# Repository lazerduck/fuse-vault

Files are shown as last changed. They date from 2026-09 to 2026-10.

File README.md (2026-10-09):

# Fuse Vault
Fuse Vault is a security hardware device designed to provide a genuinely trustable location where you can store various secret and sensitive documents. It provides encrypted at rest storage and on-device unlocking alongside FIDO2 passkey capabilities.

## Philosophy
Fuse Vault is built around the principle of Trust. Every aspect of Fuse Vault needed to be as open source, inspectable and trustable by the user as possible. The intention was to create a device that could be trusted rather than a device that had to be trusted. Specifically in contrast to things like a TPM. To achieve this, Fuse Vault has used open source hardware where possible and all the software is also open source, inspectable and customizable. Additionally, where trust can't be 100% confirmed, we instead take whatever measures we can to get as close as possible to something we can trust. For example, when encrypting data, we allow users to establish a stack of algorithms each with a varied provenance.

## Hardware
The core of Fuse Vault is the RP2354, a Raspberry Pi RP2350-family microcontroller with integrated flash. Its architecture, memory map and peripheral interfaces are publicly documented, and the Pico SDK and boot ROM source are available. The Hazard3 RISC-V cores are open hardware; the Arm Cortex-M33 cores used by this firmware are not open-source implementations. The whole chip should therefore not be described as open-source hardware. See the [Raspberry Pi chip documentation](https://www.raspberrypi.com/documentation/microcontrollers/microcontroller-chips.html) and [boot ROM source](https://github.com/raspberrypi/pico-bootrom-rp2350). There is also a screen and D-pad enabling user interaction with the device without using the host computer. This is intended to ensure the user's key is never exposed to an attacker through a compromised computer. The PCB contains a USB-A and a USB-C male port allowing it to be plugged into most devices. In this revision of the PCB, for simplicity the storage is attached as an SD card. All data on this card is either always encrypted or not sensitive, however this is understood as a potential vulnerability.

## Software
The software is written in C with the Pico SDK and controls and coordinates the rest of the functionality of the device. The software is highly user configurable and designed to be secure over fast with observed speeds around 400 KiB/s on the device display. Throughput depends on the selected cipher stack and workload; this is not a guaranteed rate. One KiB is 1,024 bytes.

### Subsections

- [Key handling](docs/KeyHandling.md)
- [File storage](docs/FileStorage.md)
- [Setup, unlock and enrollment](docs/Setup.md)
- [FIDO2 and passkeys](docs/FIDO2.md)
- [The unlocked session](docs/Session.md)
- [Randomness](docs/Randomness.md)
- [Planned improvements](docs/Improvements.md)

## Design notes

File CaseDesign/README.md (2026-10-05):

# Fuse Vault PCB reference

**Latest: prototype E — four supported shell snaps.** [Print instructions](prototype-e/README.md)
replace D's failed thin latch with ramped alignment posts and recesses. Print the
standard snap sample first, then E base and lid. Reuse the working D end caps and
USB-C collar. Closure must hold the collar securely without help from the end caps;
physical holding force still needs testing. Intended for occasional service access.

**Previous prototype D — slimmer case; latch failed physical test.** [Print and assembly instructions](prototype-d/README.md)
cover the 12.1 mm body, tighter PCB locators, hook-and-snap closure, TPU covers
with detents, bare joystick and tactile back-button dimple. Start with the latch
test pair. The existing USB-C collar is reusable; D needs new base, lid and covers.
Physical testing is pending; earlier prototypes are preserved.

**Previous prototype C — assembly access.** [Print and assembly instructions](prototype-c/README.md)
cover the open-top PCB/collar seats, enlarged SD-card loading clearance and
externally accessible top nut. Print the C base and lid; reuse the previous
accessories. Built after the first real V2 board trial exposed insertion
obstructions. C CAD checks pass; a physical re-test is still needed.

**Previous prototype B:** [prototype-b/README.md](prototype-b/README.md) contains
print files and instructions for the flat lid, wider/lower TPU D-pad, integral
back-button tab and two TPU USB end caps. Start with the small back-button coupon.
[REVISION_B_REQUIREMENTS.md](REVISION_B_REQUIREMENTS.md) records the feedback and
current direction. B printing and populated V2 board fit remain pending.

**First case prototype now available:** [prototype-a/README.md](prototype-a/README.md)
contains the five-part PLA/TPU fit prototype, single M2 screw, hooked lid and captured
USB-C collar. Use `build_case.py` and `prototype_parameters.json` for that design.
Its corrected reference and validation are separate from the original files below.

**2026-09-21 evidence update:** See [CASE_DESIGN_BRIEF.md](CASE_DESIGN_BRIEF.md)
for the supplied screen drawing, verified USB shell heights, USB-C support
requirement, captive controls and enclosed SD card. Manufacturer PDFs are now in
`datasheets/`. The reference exports below remain revision 1: the display thickness
and USB-C mounting datum still require correction and regeneration before case CAD.

Mechanically useful **reference revision 1**, built from the supplied Gerber archive, BOM, CPL and top/bottom renders. No enclosure has been designed. The board geometry and assembly positions are source-derived; the components are simplified envelopes with explicitly provisional Z dimensions.

## Open these files

- **reference.step**: coloured, named assembly with PCB, 71 populated component envelopes and one clearly named TFT placeholder.
- **pcb.step**: exact nominal bare-board geometry, including all unique drilled holes, slots and the rectangular cutout.
- **keepouts.step**: 98 separately named clearance, terminal, solder, locating-peg and access volumes. Import in the same coordinates as reference.step.
- **reference.stl**: millimetre-scale, multi-solid preview. Components can overlap and touch; this is not a single watertight printable assembly or an enclosure.
- **pcb.stl**: bare-board mesh.
- **reference_preview.png**: top and underside views of the actual generated geometry.
- **top_validation.png / bottom_validation.png**: model envelopes and extracted features registered against the supplied renders.
- **parameters.json**: editable assumptions, with evidence beside each important component.
- **drill_schedule.csv / placements.csv / component_envelopes.csv**: extracted drill data, BOM-linked placement data, and generated component bounds.
- **validation.json**: machine-readable geometry and render-registration checks.

## Board geometry

All coordinates are **millimetres in the original EasyEDA Gerber coordinate system**, viewed from the top. X increases toward USB-A. Y is negative across the board. The bottom PCB surface is Z=0 and the top is Z=1.6. Bottom-side component coordinates are not mirrored; only the bottom-view image is mirrored for comparison.

| Feature | Nominal value / bounds | Evidence |
|---|---|---|
| Board size | 73.335 x 21.237 mm | Original GKO outline centreline |
| X extent | -0.127 to 73.208 | GKO |
| Y extent | -21.237 to 0 | GKO |
| Thickness | 1.6 mm | Gerber ZIP manufacturing metadata: `erp_parameter_file.json`, `stencil_ply=1.6` |
| Internal rectangular cutout | 2.540 x 15.748 mm | GKO |
| Cutout X | 11.42583 to 13.96583 | GKO |
| Cutout Y | -19.52613 to -3.77813 | GKO |
| Unique drill features | 105 round holes + 2 routed slots | Three original Excellon files, duplicate via records removed |
| USB-C slots | 0.50002 diameter cutter; 1.29997 centreline travel; 1.79999 overall length | PTH G85 records |

The large green areas above and below the circuitry in the renders are manufacturing rails. The processed CAM panel outline adds approximately 25 mm at each long edge. Those rails and their tooling holes are excluded from the finished PCB reference. No dedicated enclosure screw-hole pattern is established on the finished board: the large holes near USB-A and the other non-plated holes are occupied connector/switch locating features.

These are exact **design-file nominal** coordinates, not measurements of the manufactured board. Router corner radii, V-score break residue, board thickness tolerance and plating variation are not determined by the supplied data. The cutout retains the sharp nominal corners in the GKO.

## Important component locations

These are CPL placement origins, which are not always the physical centre of the body. Explicit `offset_xy` values align the simplified body to its footprint/render. Special-component sizes and offsets are expressed in board axes; generic packages use the CPL rotation.

| Ref | BOM part | Side | CPL X | CPL Y | CPL rotation |
|---|---|---|---:|---:|---:|
| J1 | SHOU HAN AM90, C404965 | Top | 69.850 | -11.049 | 90 |
| J2 | XKB U261-121N-4BS2S, C2879827 | Top / assumed mid-mount | 1.143 | -10.668 | 270 |
| CARD1 | SHOU HAN TF PUSH, C393941 | Bottom | 57.404 | -9.779 | 0 |
| U3 | SHOU HAN 0.5-8P CTSJ-H2.0 119, C5373445 | Bottom | 23.241 | -11.557 | 90 |
| SW3 | SHOU HAN 10*10*9-6P WX, C2858290 | Top | 60.325 | -14.732 | 0 |
| SW4 | LXW-TS-45X45X38-SMD, C53447035 | Top | 49.149 | -15.875 | 270 |
| SW1 | TS-1140SP-4x4x2.0H-260, C51927161 | Bottom | 6.731 | -3.302 | 180 |
| SW2 | TS-1140SP-4x4x2.0H-260, C51927161 | Bottom | 6.858 | -17.526 | 0 |

Both USB components are represented as protruding **plugs**, consistent with the supplied renders. Their simplified solid envelopes are not detailed connector shells.

## Assumptions to resolve before committing enclosure dimensions

1. **TFT:** No display part appears in either BOM or CPL. The 27.9 x 13.5 mm rectangle comes directly from top silkscreen, but is not proven to be the glass outline or active viewing area. The cyan volume is a placeholder with a 0.5 mm PCB gap and 2.5 mm thickness. No bezel opening should be derived from it yet. The flex corridor to the cutout is a provisional clearance volume, not a verified cable route.
2. **USB Z position:** J1 uses an assumed 4.5 mm body height sitting on the top PCB surface. J2 uses an assumed 2.4 mm height with its bottom 2.0 mm below the top PCB surface. These seating heights need a drawing or physical measurement. Their XY envelopes have been compared with the renders.
3. **Controls:** SW3 total height 9.0 mm, SW4 3.8 mm, and SW1/SW2 2.0 mm are inferred from exact BOM part identifiers, not verified against mechanical drawings. Joystick base/shaft shape, movement diameter and button actuators are simplified. No separate D-pad or joystick cap is supplied or modelled.
4. **microSD:** Body XY and offset are estimated from the registered bottom render, and its 2.0 mm height is provisional. The card exits toward +Y. A 20 mm withdrawal space is provided as a design allowance; actual latched/ejected card positions and push travel are not established.
5. **FPC connector:** XY uses the bottom-silkscreen envelope; 2.0 mm height is inferred from the H2.0 identifier. Latch-opening clearance remains provisional.
6. **Other parts:** Package dimensions come from footprint names, with assumed heights. Inductor heights 4.0 and 2.0 mm are inferred from series names. Solder, pins, locating pegs, special terminals and general 0.5 mm clearances are conservative editable allowances, not tolerance-certified bounds.

The manufacturer-document links were investigated, but their PDF downloads returned access/rate-limit errors. **No height is labelled drawing-verified.** Do not infer that an assumed clearance guarantees fit.

## Validation performed

- Parsed the original metric 4.5-format outline and metric Excellon files. Unsupported drill/outline syntax causes extraction to fail rather than silently dropping geometry.
- Deduplicated identical drill records across the PTH/via files; retained both original source references in the drill schedule.
- Checked that the PCB is one valid solid and every extracted drill centre passes through it.
- Independently calculated PCB volume from rectangle areas and circular/slot areas: **2383.867963245 mm3**, matching the exported STEP geometry.
- Re-imported the STEP files: **73 reference solids** and **98 keep-out solids**, all valid, with preserved volumes.
- Registered the top and mirrored bottom images using board edges, then compared seven independently selected visible component centres. Maximum discrepancy: **1.134 pixels**, approximately **0.115 mm at the render scale**. This is an image-registration result, not an assembly tolerance claim.
- Visually inspected the top/bottom overlays and depth-buffered 3D preview. The display guide, cutout, connector arrangement, joystick and bottom-side controls correspond to the supplied renders.

Z heights cannot be validated from these orthographic top/bottom renders. This revision is ready for spatial planning and measurement correction; close-fitting enclosure openings depend on resolving the assumptions above.

## Regenerate or change dimensions

Tested with Python 3.13 and CadQuery 2.8.0. From this directory:

```powershell
python -m pip install -r requirements.txt
python extract_geometry.py
python build_reference.py
python validate_and_preview.py
```

Edit `parameters.json` for body sizes, seating offsets, display dimensions and access allowances. Set `display.enabled` to false to remove the TFT placeholder. The extraction script preserves the original source files and creates `geometry.json`. To change source placements, update the source CPL and run extraction again.

`reference.step` and `keepouts.step` have the same origin and units. Keep the assemblies separate in CAD. The keep-outs intentionally overlap one another and the reference; they are spaces reserved from a future case, not extra physical parts. The PCB keep-out is a conservative bounding box and reserves the internal cutout too.

## Source provenance

The original archive was `fuse-vault_PCB1_20260916_204032.zip_Y4.zip`; geometry comes from its `12416276a_y4/yg` originals, not its translated panel CAM output. Selected source Gerbers and drills are included. The supplied top and bottom PNGs are preserved as `source/top.png` and `source/bottom.png`.

The two user-supplied files are tab-delimited UTF-16 despite their `.csv` extension:

- `d195f926bac54f4a8a605b863e6e7800_1789587642000.csv` -> `source/assembly-a.csv` (BOM).
- `d195f926bac54f4a8a605b863e6e7800_1789587642000 (1).csv` -> `source/assembly-b.csv` (CPL).

`source_hashes.json` records SHA-256 digests for the included source files. Factory account/order metadata and signed download links are not redistributed.

Manufacturer-document lookup locations, for resolving the remaining assumptions:

- [AM90](https://jlcpcb.com/partdetail/SHOUHAN-AM90/C404965)
- [U261-121N-4BS2S](https://jlcpcb.com/partdetail/XKBConnection-U261_121N4BS2S/C2879827)
- [TF PUSH](https://jlcpcb.com/partdetail/SHOUHAN-TFPUSH/C393941)
- [10*10*9-6P WX](https://jlcpcb.com/partdetail/SHOUHAN-10_10_9_6PWX/C2858290)

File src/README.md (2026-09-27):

# Source layout

All active first-party software lives under `src/`. Directory names describe
where the code runs, rather than whether it happens to be called firmware.

```text
src/
  shared/                 Libraries used by both device and desktop builds
    ui/                   Scenes, menus, drawing, credential input, debounce
    crypto/               Cipher interfaces and portable implementations
    storage/              Authenticated block storage and volume format
    security/             Vault lifecycle, keys, policy and persistence logic
    fido/                 FIDO transport, verification and encrypted store
    benchmark/            Shared benchmark engine and protocol
  pico/                   RP2354/Pico SDK code
    device/               Main application, USB, worker queues, UI/FIDO adapters
    platform/             GPIO buttons, TFT, SD, entropy, authority, board headers
    crypto/               SHA accelerator and SRAM placement headers
    benchmark/            Benchmark firmware application
    alive/                Minimal board bring-up application
  host/                   Desktop entry points and hardware simulations
    tools/                UI preview, command-line clients, browser test server
    tests/                Unit/integration tests, SDK stubs and test fixtures
```

`third_party/` contains pinned dependencies and their integration code. `v1/`
is the reference archive, not part of the active build. `build*/` contains
local generated output. Historical reports in `results/` retain the paths used
when they were written.

## Build entry points

Run these commands from the repository root. Use a **new build directory** when
switching from the old `firmware/` source paths: CMake caches its source directory.
The examples assume the Pico SDK is available at `$PICO_SDK_PATH`.

Desktop libraries, tools and tests:

```sh
cmake -S . -B build-host -DFV_MBEDTLS_DIR="$PICO_SDK_PATH/lib/mbedtls"
cmake --build build-host -j4
ctest --test-dir build-host --output-on-failure
```

Add `-DFV_ENABLE_FIDO_ENGINE=ON` for FIDO integration tests (requires Python
`fido2` and `cryptography`), or `-DFV_SANITIZERS=ON` for ASan/UBSan. The root
CMake project delegates to `host/CMakeLists.txt`; host test definitions live
in `host/tests.cmake` and `host/fido_tests.cmake`. Executables remain at the
build-directory root.

Main device application, with physical UI, USB storage and FIDO:

```sh
cmake -S src/pico/device -B build-device \
  -DPICO_SDK_PATH="$PICO_SDK_PATH" \
  -DFV_DEVICE_UI=ON -DFV_USB_MSC=ON -DFV_USB_FIDO=ON
cmake --build build-device -j4
```

The application target is still named `fuse_vault_security` to preserve existing
artifact names. Benchmark and bring-up images use `-S src/pico/benchmark` and
`-S src/pico/alive` respectively. Each application links the shared libraries it
needs; it does not contain another implementation of them.

For offline UI screenshots:

```sh
python3 src/host/tools/ui_preview.py --output /tmp/fuse-vault-ui-preview
```

This needs a host C compiler and Pillow; it renders synthetic data without
accessing a device. See [UI architecture](shared/ui/README.md) for the event flow
and how to add a scene or menu action.

## Dependency direction

Pico applications and host tools depend on shared libraries. Shared C code must
not depend on GPIO, USB scheduling, SDK time functions, host filesystems, or
worker queues. Build configuration may select an accelerated Pico backend.

The UI submits `fv_ui_job` data and receives `fv_ui_result` data. The device
adapter owns queue transport and the display driver; scene code owns presentation
and navigation. Expensive storage/crypto operations continue to run on the worker
core, outside input handling and drawing.

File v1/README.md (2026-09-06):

# Fuse Vault

Fuse Vault is a physically separate trust boundary for storing and using digital
secrets. It protects data at rest, keeps authentication and cryptographic keys
away from the host computer, and releases plaintext only through deliberate,
user-authorized disclosure. Its security model combines physical possession
with a knowledge-based secret, without biometric recovery, key escrow, or a
vendor-accessible back door.

The project is an experimental hardware-encrypted USB storage device built
around the Raspberry Pi RP2354A. It is designed for material such as recovery
codes, passwords, private documents, encryption keys, and passkey credentials:
secrets that must remain protected while stored but must also be usable when
their owner chooses to reveal them.

The device is a custom PCB with USB-A and USB-C plugs, an 80×160 colour display,
physical directional controls, and removable SD-card storage. All authentication,
key derivation, encryption, and decryption are intended to happen on the device.

Fuse Vault is currently under development. The PCB is in manufacture. Portable
firmware implements the setup and unlock state machines, device-root and
attempt-count lifecycle, authenticated redundant headers, selectable AES-XTS
and ChaCha20 data layers inside an authenticated Ascon storage envelope, and a
shared target runtime with SD-sector and TinyUSB MSC backends. The remaining
release work is hardware validation of the display, SD transport, and USB mux,
plus physical OTP/secure-boot validation and target interoperability/security testing. See
[the product-readiness checklist](docs/product-readiness.md).

## Mission

Fuse Vault is designed around two primary goals: **security at rest** and
**controlled disclosure**.

A secret is useful only if it can eventually be used. Fuse Vault therefore does
not attempt to prevent plaintext from ever reaching another computer. Instead,
it keeps the device locked and its contents encrypted until the user explicitly
authorizes access using the device's own display and physical controls.

The intended disclosure boundaries are:

- **Locked:** The host receives no storage volume, unlock secret, plaintext, or
  usable key material.
- **Unlocked storage:** The user deliberately exposes the decrypted filesystem
  as a USB mass-storage volume. The connected host can then access that volume.
- **Selective disclosure:** Where supported, the user releases one chosen
  credential or performs one authentication operation without mounting or
  exposing the wider vault.

This makes Fuse Vault more than an encrypted USB drive. It is a user-controlled
boundary between stored secrets and computers that are not inherently trusted.

## The idea

Connecting Fuse Vault supplies power and starts its user interface, but does not
immediately expose a storage volume. The user enters their unlock secret using
the onboard display and controls, without typing it on the host computer.

After successful authentication, the device presents itself as a conventional
USB mass-storage volume. The host performs ordinary block reads and writes while
the RP2354A transparently decrypts data read from the SD card and encrypts data
before writing it. The SD card should never contain the plaintext filesystem.

Disconnecting or locking the device removes access to the decrypted volume and
clears transient secrets from RAM.

```text
                    Fuse Vault
             ┌───────────────────────┐
USB-A / USB-C│  RP2354A              │      SD card
host ◀───────│  USB mass storage     │◀────▶ encrypted blocks
             │  key derivation       │
             │  cipher pipeline      │
             │  display + controls   │
             ├───────────────────────┤
             │ Password entry occurs │
             │ entirely on-device.   │
             └───────────────────────┘
```

## Design principles

- **Security at rest.** Capturing the locked device or removing and imaging its
  SD card does not reveal the stored contents.
- **Hardware-isolated authentication.** Password entry, key derivation, and
  storage cryptography are performed by the RP2354A rather than the host CPU.
- **Deliberate disclosure.** Nothing is mounted before authentication. Plaintext
  is released only after an explicit action using the physical device.
- **Minimum necessary disclosure.** Modes that operate on individual
  credentials reveal only the selected secret or authentication result rather
  than exposing the complete storage volume.
- **Integrity as well as confidentiality.** Encrypted storage must detect
  unauthorized modification and, where the storage design permits, rollback of
  protected data.
- **Encrypted media is untrusted media.** Removing and imaging the SD card
  should disclose ciphertext, not the filesystem or its contents.
- **No recovery by design.** The user secret is combined with a unique,
  device-bound secret. If that secret is destroyed or the device becomes
  unrecoverable, the encrypted data is also permanently lost.
- **Do not depend on one cipher.** The planned cryptographic pipeline can apply
  multiple independently keyed algorithms, reducing reliance on any single
  primitive or standards authority.
- **Minimise host trust.** The host receives only data that the user explicitly
  makes available. It should never receive the vault password or master keys.

Fuse Vault necessarily trusts a deliberately limited set of components: the
RP2354A silicon and immutable boot process, the configured device-security
facilities, the Fuse Vault firmware and provisioning process, and the onboard
display and controls used to authorize operations. The host computer, removable
storage, and undocumented host security processors remain outside that trusted
boundary.

## Hardware

The current design includes:

- Raspberry Pi RP2354A microcontroller with 2 MB of stacked flash
- WiseVision N096-1608TBBIG09-C08 80×160 RGB display
- Four-way directional control and a back button
- SD card wired for native four-bit SD; firmware uses PIO/DMA-driven SPI over
  the same pins as a conservative baseline
- Male USB-A and USB-C connectors
- USB ESD protection and power-path diodes
- Voltage-divider sensing for connector detection
- A multiplexer for selecting the active USB data connection

The RP2354A was chosen for its integrated flash and security-oriented facilities,
including OTP storage, a hardware true-random-number generator, SHA-256
acceleration, Arm TrustZone support, signed boot, and encrypted code storage.

The EasyEDA Pro hardware project is stored in
[`circuit board/fuse-vault.eprj2`](circuit%20board/fuse-vault.eprj2).

## Key hierarchy

The intended key flow is:

```text
user-entered secret ─┐
                     ├─▶ password KDF ─▶ master key
device-bound secret ─┘                       │
                                            ├─▶ key for cipher layer 1
                                            ├─▶ key for cipher layer 2
                                            └─▶ keys for authentication,
                                                metadata, and other purposes
```

The user-entered secret exists only in RAM while needed. It is never stored on
the SD card or sent to the host. A salt and an appropriate password-based key
derivation function will be used alongside the device-bound secret. Derived keys
must be domain-separated so that no key is reused across algorithms or purposes.

The device-bound secret deliberately makes the vault inseparable from its
hardware. Fuse Vault will not provide a back door, recovery key, or escrow path.

The V1 KDF domains, credential envelope, memory ownership, OTP root layout,
candidate page locks, secure-boot/recovery policy, and fail-closed signing
workflow are specified. Target KDF-cost calibration, real signing identities,
and sacrificial-silicon validation remain release gates.

## Encryption pipeline

Fuse Vault supports a versioned stack of block-preserving encryption layers.
The user selects and orders the available layers when the vault is formatted.
Encryption passes each storage block through the configured pipeline;
decryption processes the same pipeline in reverse.

```text
write: plaintext block  ─▶ cipher A ─▶ cipher B ─▶ encrypted SD block
read:  encrypted block ─▶ cipher B⁻¹ ─▶ cipher A⁻¹ ─▶ plaintext block
```

The V1 registry implements AES-256-XTS and ChaCha20 and reserves an unavailable
ID for SM4-XTS. Every layer uses independently derived key material bound to its
algorithm, version, vault, and stack position. A mandatory authenticated Ascon
storage envelope prevents a user selection from removing integrity protection.

The V1 on-media format defines tweaks/nonces, authenticated metadata, redundant
copy-on-write records, interrupted-write recovery, and its explicit rollback
limit. See [the encrypted-data format](docs/encrypted-data-format-v1.md).

## Operating modes

The device may offer a mode selector when it powers on. Planned modes include:

### Encrypted storage

After local authentication, expose the decrypted vault as USB mass storage.
While it is unlocked, the connected host can read, copy, modify, or delete all
data made available through that volume. Fuse Vault protects data at rest; it
does not attempt to isolate data that the user has made available to an unlocked
host.

### FIDO2 authenticator

Act as a FIDO2 roaming authenticator, with user interaction and verification on
the device. FIDO credentials and storage-encryption keys must use separate key
domains and permissions. Unlocking one function must not implicitly authorize
the other.

### Selective keyboard output (possible future feature)

Allow the user to select one stored credential on the device and deliberately
send only that value to the host as USB keyboard input at the current cursor.
This would avoid mounting the storage vault or exposing unrelated secrets.

The selected value would necessarily become visible to the receiving host and
application, so this mode is selective disclosure rather than secret isolation.
It is a post-V1 possibility, not a current requirement.

## Initial threat model

Fuse Vault aims to protect against:

- Theft or loss while the device is locked
- Offline imaging or removal of the SD card
- Password capture by host keyloggers during normal on-device entry
- Direct access to plaintext or storage keys by the host before unlocking
- Unauthorized or downgraded firmware, once secure boot and provisioning are
  correctly implemented
- Repeated guessing, using a persistent attempt counter and a possible
  destructive lockout policy

Data exposed to a host after unlocking falls outside this boundary. Side-channel
analysis, fault injection, debug-port policy, firmware rollback, supply-chain
attacks, and invasive physical attacks will be addressed in a separate threat
model.

A proposed limit of approximately ten failed unlock attempts would erase or
irreversibly invalidate the device-bound secret. This behaviour must be designed
to survive power interruption and state rollback. It also intentionally permits
denial of service: an attacker with the device could destroy access to its data
even without learning the data.

## Project status

Fuse Vault is at the assembled-firmware and hardware-integration stage. The PCB
is in manufacture. The setup, selectable encryption, persistence, encrypted
block, and USB-MSC control paths now form one RP2354A runtime. The remaining
critical path is physical display/SD/presence-sense bring-up, OTP and secure-boot validation,
and hardware power-loss, performance, and host-interoperability testing.

Near-term work includes:

1. Bring up the display and SD card, confirm USB presence polarity, and verify
   connector routing on revision-1 boards.
2. Benchmark KDF, crypto-stack, SD, and USB performance on the RP2354A.
3. Create the release/recovery signing identities and validate the frozen OTP,
   secure-boot, debug, rollback, and signed-update policy on sacrificial devices.
4. Run power-cut/removal campaigns and Windows/macOS/Linux MSC tests.
5. Complete independent cryptographic and firmware review.
6. Add FIDO2 as an independently authorized product slice after V1 storage.

## Security status

The project is at the design and prototyping stage and has not yet undergone an
independent security audit. A dedicated security policy and private disclosure
process will be added before public hardware or firmware releases.

## Documentation

- [Raspberry Pi microcontroller documentation](https://www.raspberrypi.com/documentation/microcontrollers/microcontroller-chips.html)
- [FIDO2 specifications](https://fidoalliance.org/specifications/download/)
- [V1 product contract](docs/v1-product-contract.md)
- [Product-readiness checklist](docs/product-readiness.md)
- [FIDO2 library assessment and integration plan](docs/fido2-integration-plan.md)
- [Release and OTP artifact workflow](provisioning/README.md)

## License

No project licence has been selected yet. Until a licence is added, all rights
remain with the project copyright holder.

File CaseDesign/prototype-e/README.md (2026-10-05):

# Prototype E — four ramped shell snaps

Replaces the failed thin D latch with short, broad alignment posts and matching
sloped recesses. Intended for a firm closure and occasional opening, including
holding the USB-C collar captive with the USB end covers removed. **Physical
holding strength remains untested.** No thin spring arm or sacrificial support web.

## Print tonight

1. Start with **base_snap_standard.stl + lid_snap_standard.stl**. These use the
   same 0.25 mm engagement as the supplied full case. They are short cross-sections
   with two opposing walls, so they exercise more than an isolated flexible tooth.
2. Use your **0.4 mm nozzle**, 0.2 mm layers and the shell material/settings you
   intend for the case. Inspect the slicer preview: stems, ramps and recesses must
   have continuous extrusion paths. Keep supports off the snap mating surfaces.
   All STLs are already bed-oriented: base floor down, lid outer face down.
3. Let the sample cool, clear stray strings, align it and press the two sides home.
   It should seat fully and resist being pulled apart. There is no web to cut.
   A sample that barely catches or falls apart is a failed fit, not ready for USB-C
   retention. A sample that needs excessive force should not be forced onto a board.
4. Print **base.stl + lid.stl** after the standard sample works. Reuse the working
   D USB covers and existing USB-C collar. Do not mix E and D shell halves.

Additional sample pairs: `*_snap_light.stl` use 0.15 mm engagement;
`*_snap_firm.stl` use 0.35 mm. They are comparison samples only. The supplied full
shell is **standard**, not firm. If only another sample works, the full shell
needs regenerating with that engagement before printing. Local samples do not
establish the complete case's stiffness or retention force.

## What changed

- Four supported snap posts: one on each side near USB-C and another pair near
  USB-A. Front posts are 3.5 mm wide and rear posts 3 mm wide, with 1 mm stems,
  wider roots and sloping catches. Surrounding shell walls provide the small
  elastic movement, rather than a separately slotted spring arm.
- Nominal 0.25 mm engagement beyond the entry clearance. The ramps/recesses slope
  in both printing directions. These are detents, not irreversible barbs.
- Original USB-C-end hooks remain. The old D latch cuts, catch and support web
  are removed; that side wall is solid again.
- Board supports are independent of the snaps. Populated-board loading, the
  larger SD notch, 12.1 mm body thickness, controls and flex pocket are unchanged.
- D end-cap shapes and USB-C collar are unchanged. `preserved_geometry.json`
  also checks that the case's USB-C capture region matches D.

## Assembly and retention check

Fit the SD card and USB-C collar to the board first, then lower them together
into the base. Arrange the cable without pinching it. Engage the original
USB-C-end lid hooks, lower the lid, then press beside each opposing snap pair.
Press on the rim, not on the screen, joystick or back button. Check that all four
positions seat and that the seam closes evenly.

First try the empty case without end covers. Gently pull the halves apart near
both ends: the four snaps must hold on their own. Then install the board and
check that ordinary USB insertion/removal does not open the seam or displace the
collar. Do not use the bare connector as a lever or a destructive strength test.
If a snap does not hold, stop and adjust the engagement rather than relying on
an end cover to provide the missing USB-C retention.

Opening is deliberately less convenient than closing. Remove the USB covers,
work a thin plastic pick along the side seam near a snap, and release one region
at a time. Avoid levering on the connectors or pushing tools into the electronics.
The design is for a few service openings, not frequent daily access. Inspect for
cracks after opening; infrequent use does not make a damaged snap safe to reuse.

## Files and checks

`base.stl` and `lid.stl` are the only new full-size prints needed. Accessory STLs
are included for completeness. STEP parts retain assembly coordinates; assembly
STEPs include simplified electronics and are not single printable objects.

`validation.json` covers solids, STEP round trips, closed bed-oriented meshes,
static/sample fit, board/SD/collar insertion, bare-shaft clearance, lid closure,
end-cover fit and axial collar capture. During closure, intentional interference
is permitted only on the outward snap beads; the stems and other case geometry
must remain clear. A 0.4 mm sample separation encounters the retaining ramps.

These checks do **not** establish wall stress, pull-off force, print tolerance or
USB-C load capacity. Test the real printed parts with the end covers removed.
The slimmer D cable allowance and other provisional electronics dimensions are
unchanged. Earlier A/B/C/D files and ZIPs are preserved.

Rebuild using CadQuery 2.8 and VTK:

```sh
python CaseDesign/build_case_e.py
python CaseDesign/render_case_e.py
```

`P['snap_engagement']` sets the full-case engagement. The three sample pairs are
fixed at 0.15 / 0.25 / 0.35 mm. Repackage the ZIP after rebuilding.

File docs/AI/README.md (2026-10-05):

# AI documentation archive

These are earlier AI-generated design notes, proposals and implementation records.
They are retained for reference and may contain stale status or superseded decisions.
For the documentation currently being reconciled with the implementation, start with
the [project README](../../README.md) and [key handling](../KeyHandling.md).
A proposal or completion claim in this archive is not by itself an accepted current requirement.

## Previous project overview

A fresh start from the existing circuit board design.

FIDO implementation stages, accepted design decisions, validation evidence and
the next action are tracked in the [V2 FIDO delivery ledger](v2-fido-progress.md).
The [browser/passkey-management runbook](v2-fido-browser-testing.md) covers F4 testing.
Current development priorities are tracked in the
[V2 software completion and polish plan](v2-software-polish.md).
For offline screen previews, run `python3 src/host/tools/ui_preview.py` (host C compiler
and Pillow required); no USB connection is needed.

## Source map

All active source is under `src/`:

- [`src/shared/`](../../src/README.md): reusable UI, crypto, storage, security and FIDO libraries.
- [`src/pico/`](../../src/pico/device/README.md): device applications, board drivers and accelerated backends.
- [`src/host/`](../../src/host/CMakeLists.txt): desktop tools, tests and simulated hardware.

See the [source/build guide](../../src/README.md) and [UI scene guide](../../src/shared/ui/README.md).
The main device application is `src/pico/device/`; `v1/` remains an archive.

## V2 source

The [standalone crypto module](../../src/shared/crypto/README.md) contains the cipher interface,
AES-256-XTS and Camellia-256-XTS implementations, ordered pipelines, desktop tests,
and a RAM benchmark. See its README for build instructions and current scope.

The [board benchmark firmware](../../src/pico/benchmark/README.md) adds native four-bit SD,
a laptop-controlled binary USB interface and two-core encryption/storage benchmarks.

The [authenticated storage module](../../src/shared/storage/README.md) adds packed HMAC tags
and unset sectors. See [security-state placement](v2-security-state.md) for
the split between SD metadata and Pico flash/OTP state.

The next-stage [volume format and key lifecycle draft](v2-volume-and-key-design.md)
defines proposed headers, derivations, unlock and credential-change behaviour for review.
The [portable vault module](../../src/shared/security/README.md) implements the four-slot
[VMK envelope](v2-vmk-envelope-proposal.md), create/unlock, encrypted storage,
credential changes and attempt accounting, with desktop lifecycle/failure tests.
The [OTP enrollment and authenticated flash journal](v2-persistent-authority.md)
are implemented for hardware testing; the persistent format is not frozen.

The [security bring-up firmware](../../src/pico/device/README.md) links that lifecycle
to the Pico/SD and adds TRNG/CTR-DRBG diagnostics, unlock timing, and optional
OTP snapshots and guarded provisioning/destruction tools. Persistent enrollment
uses 60,000 PBKDF2 iterations. Physical provisioning and power-cycle verification
are the next board tests. Track release work in the
[production checklist](production-checklist.md).

## Circuit board

- [EasyEDA Pro board project](../../circuit%20board/fuse-vault.eprj2)
- [Hardware evidence and bring-up notes](hardware-bringup-stage4.md)
- [Display connector investigation](display-connector-failure-analysis.md)
- [Extracted display connector evidence](hardware-evidence/u3-project-records.json)

The retained hardware notes are historical records. References to firmware,
tests, and implementation status describe V1; that code now lives under `v1/`.

## V1 reference archive

[The previous project](../../v1/README.md) is preserved under `v1/`, including firmware,
display drivers, tests, tools, provisioning files, documentation, editor settings,
and local build outputs. It is available for reference and selective reuse.

Archived files retain their original contents. Commands, absolute paths, editor
settings, and cached build paths may need updating before reuse. Links to the
board project in the archived README refer to its former relative location;
the board project remains in the top-level `circuit board/` folder.

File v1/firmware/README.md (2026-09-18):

# Fuse Vault firmware

This directory contains the C firmware for the custom Fuse Vault RP2354A board.
It uses the Raspberry Pi Pico C/C++ SDK and contains the portable product core,
the RP2354A platform composition, native simulation, and verification tests.

The firmware enters locked and exposes no USB data interface. The GPIO map and
FSUSB42 OE/SEL behavior and active-high USB presence dividers are captured for
PCB revision 1. The screen mounts horizontally with its flex through the PCB;
its P-channel backlight switch enables low. Display initialization and SD
card-detect polarity remain gated pending assembled-board bring-up.

The application state machine and 160x80 RGB565 framebuffer renderer are
portable C shared by the RP2354A target, a native simulator, and automated
tests. Consequently, the simulator displays the same pixels that will be sent
to the TFT rather than recreating the interface with desktop widgets. Platform
code—not the application core—owns secrets, persistent security state, USB,
storage, input, and display hardware.

The SD card uses the standard SD memory-card SPI protocol on the existing
CLK/CMD/DAT0/DAT3 wiring. PIO0 drives mode-0 SPI timing; two DMA channels move
transmit and receive bytes, including whole 512-byte payloads. The fixed SPI
peripheral cannot map CLK=GPIO4, MOSI=GPIO5 and MISO=GPIO6, so PIO preserves the
PCB wiring. The display continues to use its separate SPI0 peripheral.

Initialization is limited to 400 kHz (divider rounded down in frequency), with
at least 74 initial clocks after a power-settling delay. After initialization
and CSD validation, data transfers use at most 8 MHz. Command CRC7, data CRC16,
capacity parsing and read-back verification remain in place. DMA/PIO waits have
a 100 ms deadline; a transport failure stops the state machine and DMA before
returning, invalidates the card and follows the existing storage-fault path.
Reinitialization resets the transport and returns to the slow clock.

The driver claims one PIO0 state machine, two instruction words and two DMA
channels, and releases them on deinitialization. Resource exhaustion fails
initialization. Calls remain synchronous on core 0: PIO/DMA removes CPU-driven
bit timing and byte copying, but does not add background USB/UI scheduling.
The candidate clock rates still require logic-analyser and card testing.

PCB revision 1 accidentally connects each USB-presence signal to two GPIOs:
GPIO2/GPIO16 for USB-A and GPIO3/GPIO17 for USB-C. Firmware treats GPIO2 and
GPIO3 as canonical and must leave GPIO16 and GPIO17 configured as high-impedance
inputs.

## Prerequisites

- CMake 3.15 or later
- Ninja or Make
- Arm GNU embedded toolchain supported by the Pico SDK
- Raspberry Pi Pico SDK 2.3.0 or later
- `picotool` for inspecting and loading binaries (recommended)

On Ubuntu-based systems, install the build dependencies with:

```sh
sudo apt install build-essential cmake ninja-build python3 \
  gcc-arm-none-eabi libnewlib-arm-none-eabi \
  libstdc++-arm-none-eabi-newlib
```

Add `libusb-1.0-0-dev` if `picotool` should communicate with connected boards
over USB. It is not required to compile the firmware or copy a UF2 file to a
board in BOOTSEL mode.

Clone the Pico SDK, including its submodules, somewhere outside this repository:

```sh
git clone --branch 2.3.0 --recurse-submodules \
  https://github.com/raspberrypi/pico-sdk.git /path/to/pico-sdk
```

## Build

From the repository root:

```sh
cmake -S firmware -B firmware/build -G Ninja \
  -DPICO_SDK_PATH=/path/to/pico-sdk \
  -DCMAKE_BUILD_TYPE=Debug
cmake --build firmware/build
```

The build produces `fuse_vault.uf2`, `fuse_vault.elf`, and related files in
`firmware/build/`.

The custom board definition selects the secure Arm Cortex-M33 platform, the
RP2350 A package, and the RP2354A's 2 MiB stacked flash. It uses the generic
serial-read boot stage until the flash configuration has been validated on the
assembled device.

The candidate ST7735S display turns on by default, so orientation, offsets and
colour order can be inspected during bring-up. `FUSE_VAULT_ENABLE_DISPLAY=OFF`
is available for transport diagnostics (normal application startup requires a
working display). Enabling the display does not mark its profile as validated.
Bench builds can supply `FUSE_VAULT_BENCH_USB_A_PRESENT_LEVEL`,
`FUSE_VAULT_BENCH_USB_C_PRESENT_LEVEL`, and
`FUSE_VAULT_BENCH_SD_CARD_DETECT_LEVEL` as `0` or `1`. Measured values must be
recorded in the board definition before release.

A production-candidate configuration additionally sets
`FUSE_VAULT_RELEASE_BUILD=ON`. That profile requires an optimized Release build,
a semantic version, an assigned non-development USB VID/PID, an explicit review
acknowledgement, and all display/SD/USB evidence gates in the board definition.
It rejects every bench-only override and a disabled display, and runs the OTP
policy verifier in release mode. It therefore fails today by design until the
signing hashes, recorded evidence, and assembled-board measurements have been
reviewed. A successful release build is still unsigned; use the
read-only packaging workflow in `../provisioning/README.md` to sign and verify
the ELF and recovery UF2.

## Host simulator and tests

Build the portable firmware core without the Pico SDK:

```sh
cmake -S firmware/host -B firmware/build-host -G Ninja \
  -DCMAKE_BUILD_TYPE=Debug
cmake --build firmware/build-host
ctest --test-dir firmware/build-host --output-on-failure
```

For AddressSanitizer and UndefinedBehaviorSanitizer verification, configure a
separate host build with `-DFUSE_VAULT_ENABLE_SANITIZERS=ON`. Environments that
run tests under `ptrace` must invoke CTest with
`ASAN_OPTIONS=detect_leaks=0`; address and undefined-behavior checking remain
enabled, while leak checking must be run on an unrestricted host.

### File-backed OTP emulator

Host builds include a deliberately small OTP model backed by an 8 KiB file.
It represents all 4096 logical ECC data rows as little-endian 16-bit values.
New images contain only zeroes; programming may change bits only from zero to
one, each row is flushed independently, and the image persists across process
restarts. It therefore exercises the firmware's empty, partially programmed,
active, invalid, and revoked layouts without claiming to reproduce OTP timing,
analogue failure modes, ECC fault correction, permissions, or page locking.

The accompanying tool generates test roots from the host operating system and
never prints them:

```sh
firmware/build-host/fuse_vault_otp_file_tool /tmp/fuse-vault-otp.bin status
firmware/build-host/fuse_vault_otp_file_tool /tmp/fuse-vault-otp.bin provision
firmware/build-host/fuse_vault_otp_file_tool /tmp/fuse-vault-otp.bin status
firmware/build-host/fuse_vault_otp_file_tool /tmp/fuse-vault-otp.bin revoke
```

Deleting the image creates a new emulated device on the next invocation. This
is intentionally possible only in the host model; real OTP cannot be reset.
Equivalent inspect, provision, and revoke commands are available in the VS Code
task list and use `firmware/build-host/emulated-otp.bin`.

Run the interactive terminal simulator:

```sh
firmware/build-host/fuse_vault_simulator
```

On a desktop with GTK 3 development files installed, the host build also
produces a graphical 160x80 landscape display simulator:

```sh
firmware/build-host/fuse_vault_display_simulator
```

The graphical simulator displays the 80x160 panel rotated into the device's
160x80 landscape orientation at 4x scale. Arrow keys map to the four D-pad
directions, Enter (or Space) maps to the centre OK button, and Backspace (or
Escape) maps to the Back button. Clickable controls use the same debounce and
repeat handling. The simulated-host note field accepts normal text input;
click a device control to return keyboard focus to navigation.

Keyboard press and release events now pass through the same input controller as
the RP2354 GPIO buttons. It applies a 25 ms debounce, a 450 ms hold delay, and a
120 ms repeat interval. Each application state registers only the controls it
accepts and whether they may repeat; changing screens while a control is held
requires release before the new binding can fire. See
[`docs/firmware-architecture.md`](../docs/firmware-architecture.md).

Secret entry is a reusable component shared by setup, confirmation, and
unlocking. The setup method screen offers four methods:

- **Number wheels:** three 0-99 wheels. Left and Right choose a wheel, Up and
  Down change it, and OK completes entry.
- **Direction sequence:** D-pad directions append to a 6-16 step sequence,
  Back removes the last step, and OK completes a sufficiently long sequence.
- **Numeric keypad:** a navigable 3x4 keypad provides digits, delete, and OK.
  PINs contain 4-12 digits; Back also deletes the most recent digit.
- **Word list:** four initially empty positions each select one of 64 stable
  words. Choices sit above, right, below, and left to match the D-pad. Each press
  chooses a group of 16, a group
  of four, then a word. Every word takes exactly three presses, and selection
  advances to the next empty position. Group labels show the first and last
  three-letter word prefixes. After all four words are chosen, arrows edit the
  corresponding numbered position and OK submits the reviewed phrase. Back
  undoes a group choice, cancels an edit, or removes the previous word at the
  root. Back at the first empty position leaves the screen. Held buttons do
  not repeat. Incomplete phrases cannot be submitted or encoded; completed
  phrases retain the existing word IDs and canonical encoding.

Pressing Back on an empty variable-length entry returns to the preceding
screen. Setup keeps the first entry in transient memory and confirms it by
comparing its canonical encoding with a separately entered value. The selected
method remains active after setup. On a persistent restart, the boot-recovery
boundary validates the complete vault header and translates its stable method
identifier before supplying the recovered method to `fv_app_init`; missing or
invalid provisioned metadata fails closed.

Every method produces a fixed-capacity, zero-padded canonical encoding with a
format version, method identifier, value count, and method-specific values.
The credential-envelope backend consumes the complete encoding through two
independently salted, bounded work functions; the encoding is never treated as
an encryption key. These human-entered methods rely on the persistent attempt
limit and device-held secret rather than standalone password entropy.

In VS Code, run `Fuse Vault: Run display simulator` from **Tasks: Run Task**.
Use `Fuse Vault: Run persistent simulator` to exercise attempt persistence
across restarts without manually acknowledging counter writes.
For breakpoints and stepping, select `Fuse Vault: Debug display simulator` in
the Run and Debug panel and press F5. The build is configured automatically
before either action.

The graphical simulator now always uses persistent development storage and
the shared `fv_device_runtime`. Setup, authentication, attempt accounting,
encryption-stack selection, encrypted block access and teardown run for real.
There are no success/failure injection shortcuts in this window. The separate
terminal simulator remains an event-driven state-machine inspection tool.

With no arguments, the default device is stored under
`$XDG_DATA_HOME/fuse-vault/simulator/default` (normally
`~/.local/share/fuse-vault/simulator/default`). First launch enters setup;
subsequent launches recover that device. Use `--state-dir DIRECTORY` to keep a
named device elsewhere. Only one simulator may open a given device at a time.

`--new` starts a separate device; `--unprovisioned` remains an alias.
With an explicit state directory, existing provisioned state always wins and
is never erased. The window's **New device** button creates a uniquely named
sibling directory, leaving the previous device available via `--state-dir`.

A useful ergonomics session:

1. Complete setup using the clickable D-pad/OK/Back or keyboard controls.
2. Choose an entry method, enter and confirm its secret, choose the ordered
   cipher stack, then accept the no-recovery policy.
3. Enter the same secret to unlock, then select Vault storage.
4. Type a short sample note in the simulated-host panel and click **Save**.
5. Click **Restart**, unlock again, then **Load** to retrieve that note.
6. Try a wrong secret, Back, Lock and Eject; try another method with **New device**.

The note panel accesses logical sector zero exclusively through virtual MSC and
the encrypted block adapter, with sync on save. It is a 511-byte UTF-8 sample
payload, not a filesystem or an OS-mounted drive. Lock/restart/eject disables
the panel and clears its displayed text. The backing media file stores the
encrypted record. Simulated roots remain ordinary local files, so use test
secrets and test notes. This environment does not emulate physical OTP locks
or device timing; cryptographic work runs synchronously on the host CPU.

When Mbed TLS 3.6 sources are available, the graphical simulator also connects
**FIDO2** to the real CTAP engine and encrypted private credential store. CMake
looks in `$PICO_SDK_PATH/lib/mbedtls` and `~/pico-sdk/lib/mbedtls`, or accepts
`-DFUSE_VAULT_MBEDTLS_SOURCE=/path/to/mbedtls`. The selected Python interpreter
must have `fido2` and `cryptography` installed; choose it with
`-DPython3_EXECUTABLE=/usr/bin/python3`. Set `-DFUSE_VAULT_SIMULATOR_FIDO2=OFF`
for a storage-only GUI build.

Unlock, select **FIDO2**, and use the simulated host's **Register** or
**Authenticate** buttons. Approve on the device with **OK**; **Back** cancels.
The client verifies registration and authentication signatures using python-fido2.
When idle, device **OK** opens the passkey list; select a passkey and confirm
with **Right** to delete it. Password changes and restarts preserve credentials.
Verification starts within 30 seconds of unlock and remains bound to that site
for up to ten minutes; unlock again for another site or after expiry.

This panel uses private local IPC, not USB HID: it does not expose a security key
to desktop browsers. The simulated site's `simulated-fido-host.json` contains
public registration data; authenticator signing keys stay in encrypted media.
New simulator devices have 2 MiB of media, including a 1 MiB FIDO reservation.
Older 128 KiB devices still open unchanged for storage and settings, but cannot
fit the FIDO store. Use **New device** for FIDO testing; it preserves the old device.
After rebuilding, close and reopen the application to load the new executable.

**Restart** performs orderly detach and starts recovery using the same files.
Power-cut fault injection remains in automated tests. **New device** creates
fresh simulated roots on setup and lets you compare password methods without
deleting earlier devices. Keyboard holds use the firmware debounce/repeat
controller; loss of window focus releases held controls.

The RP2354 boot path now composes OTP roots, the internal flash journal, the raw
SD backend, authenticated media layout and redundant header store through the
same platform-service boundary as the host tests. It validates journal/media
vault identity before recovering the entry method and fails locked on any
missing, corrupt, unsupported, or inconsistent provisioned metadata.

The SD driver may initialize successfully with no card present. New devices can
therefore reach setup and retry after insertion. Provisioned devices show a
media-required state with USB disconnected, initialize a card on its insertion
edge, and continue only after the journal identity and authenticated vault
header match. Removal, low-level SD failure, encrypted-block failure, or MSC
sync failure during a live session is promoted to the application fault path so
USB disconnects and session keys are erased.

A limited host NOR utility tests the invariants needed by the future RP2354A
internal-flash attempt journal: aligned erase/program operations, the inability
to change programmed zero bits back to one without erase, and torn programming.
It is a fault-injection aid, not a hardware simulator, and does not model flash
timing, XIP/cache effects, wear, or electrical failure.

The portable authenticated journal itself is now implemented and shared with
the RP2354A build. It uses two erase sectors and append-only 256-byte records,
keeps the latest valid record safe while rotating sectors, and authenticates
each record with two 32-byte tags supplied by the platform cryptography layer.
Host tests interrupt writes at every byte boundary, corrupt the newest record,
and force sector rotation. Their deterministic tag function is intentionally
non-cryptographic.

The RP2354A flash adapter reserves the final 8 KiB of stacked flash, enforces
page/sector alignment and bounds, performs writes through Pico SDK safe-flash
coordination, and verifies programmed or erased contents. Link-time and boot-time
overlap checks keep firmware out of the reserved range; boot fails locked if the
geometry is not safe.

The dual authenticator is now implemented: independent 256-bit device roots
feed SP 800-108 HMAC-SHA-256 and KMAC256 derivations, and both full-size tags
must validate. The SHA branch uses RP2350 hardware acceleration and the Keccak
branch is portable C. Host tests include NIST's published KMAC256 sample and an
independently generated HMAC derivation/tag answer. Hardware journal writes
are enabled only after active roots have been recovered; the boot path connects
that root set to journal recovery.

The same firmware handles first setup and normal operation. On a fresh device,
setup generates, commits and reads back two random OTP roots before creating
the vault header and journal. No provisioning build or second flash is needed.
Setup reuses existing active roots. Only a completely empty root/revocation
layout permits creation; partial, invalid, revoked or unreadable OTP never
causes regeneration. Recoverable SD or journal failures never revoke roots.

The OTP lifecycle uses page 60 for roots, format and active markers, and page 59
for revocation. Root data is verified before the active marker is committed.
Boot accepts empty roots for first setup, or active roots with an empty journal
for new vault setup. Provisioned state requires a matching authenticated SD
header. Attempt reservations append before authentication; destructive lockout
programs the one-way revocation marker and clears derived keys.

OTP access locks and firmware signing are separate from root creation. Candidate
page locks, a picotool-compatible permission file, secure-boot policy and signing
packager are defined in `../provisioning/`. Root creation must finish before
applying the permanent page-60 read-only lock. The application does not program
these locks or secure-boot settings automatically.

The credential-envelope backend generates a random 32-byte VMK and protects it
with an inner AES-256-GCM envelope and an outer Ascon-AEAD128 envelope. The
independent wrapping keys come from PBKDF2-HMAC-SHA-256 plus Root A and iterated
KMAC256 plus Root B. The 92-byte result fits in the existing vault header, whose
security-relevant metadata is authenticated as AEAD associated data. Host tests
require the correct entry and both roots, mutate every envelope byte, exercise
metadata tampering and work limits, and include the official empty-message
Ascon-AEAD128 known answer. The target starts at 100,000 PBKDF2 and 10,000 KMAC
iterations; assembled-device latency measurement must set final release values.

The core refuses to begin authentication until an incremented attempt counter
has been persisted, and it refuses to request USB mass-storage attachment until
successful authentication and persistence of the reset counter. The tests exercise
provisioning, vault unlock and lock, future-FIDO availability gating, persistent attempt
limits, fault handling, and the MSC attachment boundary.

The shared authentication coordinator canonicalizes the active entry, validates
the persisted header and method, reads both device roots, and opens the envelope.
Credential and method mismatches are ordinary failed attempts; missing, corrupt,
or unreadable security material faults closed. A successful VMK belongs to an
explicit session until lock, eject, or fault requests session-key erasure, while
the coordinator workspace is cleared before every return.

## Flash

For initial bring-up, hold the board's BOOTSEL control while connecting it and
copy `firmware/build/fuse_vault.uf2` to the RP2350 boot volume. Alternatively,
use a supported debug probe or `picotool` once the board connection and reset
arrangement have been confirmed.

## Layout

```text
firmware/
├── boards/fuse_vault.h       Custom Pico SDK board definition
├── host/                     Native simulator and tests
├── include/fuse_vault/app.h  Portable application interface
├── include/fuse_vault/block_device.h
│                              Protocol-neutral storage interface
├── include/fuse_vault/security_journal.h
│                              Portable authenticated journal interface
├── src/app.c                 State machine and UI view model
├── src/main.c                RP2354A platform entry point
├── src/rp2354_security_flash.c
│                              Reserved stacked-flash journal backend
└── CMakeLists.txt            Firmware build definition
```

## Next steps

1. Verify the populated ST7735S module, candidate framebuffer orientation,
   offsets, colour order, SPI rate, and reset/backlight polarity.
2. Verify USB-A/USB-C presence polarity and bench-test the integrated
   disable/select/enable routing and disconnect-on-change behavior.
3. Bench-test SD CRC, geometry, removal, durability, and throughput on real cards.
4. Test TinyUSB MSC format/mount/read/write/sync/eject across supported hosts.
5. Supply signing identities and validate the frozen OTP, secure-boot, debug,
   rollback, and signed-update policy on sacrificial boards.
6. Run target KDF/stack/throughput/stack-watermark and power-cut campaigns.

See [`docs/product-readiness.md`](../docs/product-readiness.md) for the current
release checklist.

## Pico FIDO device integration

The optional FIDO build connects the upstream CTAP2 engine to device unlock,
physical confirmation, the existing USB owner and encrypted SD storage. After
normal provisioning, unlock the device and select **FIDO2**. There is no separate
FIDO PIN. Select approves a request; Back cancels or locks the device.

The unlock can supply FIDO verification for the first site within 30 seconds,
then for that site for at most ten minutes. A different site or expiry requires
the same device unlock again. Storage and FIDO remain exclusive USB modes.

```sh
cmake -S firmware -B firmware/build-fido \
  -DPICO_SDK_PATH=/path/to/pico-sdk -DFUSE_VAULT_ENABLE_FIDO2=ON
cmake --build firmware/build-fido -j4
```

The enabled build requires Pico SDK 2.3's linker override API and reserves a
64 KiB guarded main-SRAM stack. Existing electrical bring-up gates still apply.
The feature defaults off and remains forbidden in release builds pending actual
hardware, interoperability and security validation. No physical device has been
tested. Development HID PID `0x4012` avoids the MSC descriptor-cache collision;
it is not a production USB identity.

FIDO's private SD region uses the same encrypted-block implementation and selected
stack as the vault, with separate keys derived from the unlocked VMK. Two snapshot
banks and an authenticated internal-journal digest protect committed state from
SD replay. FIDO reset deletes FIDO credentials only; whole-device root revocation
also destroys access to FIDO data. Journal v2 migration requires keeping the
firmware rollback protection policy intact.

Host validation, including the independent FIDO client, is available with:

```sh
cmake -S firmware/host -B /tmp/fuse-vault-fido-host \
  -DFUSE_VAULT_MBEDTLS_SOURCE=/path/to/pico-sdk/lib/mbedtls
cmake --build /tmp/fuse-vault-fido-host -j4
ctest --test-dir /tmp/fuse-vault-fido-host --output-on-failure
```

When the selected Python interpreter has `fido2` and `cryptography`, CMake adds
`fuse_vault_fido_device_reference` (complete simulated device path) and
`fuse_vault_fido_reference` (engine ClientPIN regression fixture). The fixtures'
auto-approved presence is test-only. Tests verify signatures independently,
restart persistence, lock/verification limits, deletion/reset, failed writes and
old-media rejection. Sanitizer testing covers these paths; hardware timings,
watermarks and power-cut behavior are still unmeasured.

See the [integration status and hardware checklist](../docs/fido2-integration-plan.md)
and [pinned sources/local adaptations](third_party/pico_fido/README.fuse-vault.md).

## On-device passkey browser

In a FIDO-enabled target build, unlock, select FIDO2, then press Select to
browse saved resident passkeys. Up/Down selects an entry; Left/Right scrolls
site and account text. Select opens a deletion confirmation, Back cancels,
and a fresh Right press deletes the selected passkey. Back from the list
returns to FIDO; Back again locks. Empty stores show “No saved passkeys”.
Non-resident credentials are held by the relying party and cannot be listed.

The host cannot issue FIDO commands while local management is open. Deletion
uses the stable credential ID and the existing encrypted snapshot/journal
commit, returning to the list only after durable success. Failures close the
session; lock, faults and the ten-minute session limit clear displayed metadata.
Local management does not issue host UV tokens or change the RP verification
cache. Site/account text is bounded to 255 bytes and non-ASCII bytes display as
question marks with the current device font. There is no rename/export UI.

The independent simulated-device test now drives this same application and
runtime flow after registering real credentials, covering cancellation,
multiple entries, host exclusion, durable deletion, failed commits, expiry and
metadata clearing. Run the FIDO host suite above to exercise it without a board.
The graphical storage simulator remains storage-only.

All target builds now reserve a guarded 64 KiB stack in main SRAM with a separate
heap boundary, including the default storage build. Link-time assertions protect
the reservation; compiler `.su` reports are generated for firmware sources.
This fixes the default build's former 2 KiB allocation beneath a roughly 26 KiB
display frame. Physical stack watermark measurements remain a bring-up task.

## Password and entry-method settings

Both storage-only and FIDO-enabled builds unlock before showing the mode menu.
Unlocking alone does not attach USB; choose storage to mount it, or Settings to
change the password or entry method using the authenticated session. The user enters the replacement twice, reviews it, and
saves; success locks the device while preserving storage and FIDO credentials.
Navigation, view rendering and the persistent change coordinator are separate
modules. See [the lifecycle and transaction design](../docs/password-change.md)
for the journal-v3 header anchor, power-loss behavior and extension points.

After rebuilding the graphical simulator, close and relaunch its window to load
the new executable. Its Restart button only reboots the simulated device state
inside the running process; it does not reload an updated binary.

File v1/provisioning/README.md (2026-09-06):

# Fuse Vault release and OTP artifacts

This directory separates release preparation from irreversible hardware
provisioning. Repository tools create and verify files only. They never invoke
`picotool load`, `picotool otp load`, `picotool otp permissions`, or any other
device-writing operation.

## Files

- `otp-policy-v1.json` is the complete machine-readable release policy. Its two
  signing-key hashes and its hardware-evidence flags intentionally start
  incomplete.
- `picotool-otp-permissions-v1.json` is the picotool 2.3.0 page-permission input
  for OTP pages 59 and 60.
- `tools/verify_otp_policy.py` checks allocation, permissions, majority-vote
  words, boot/recovery policy, key slots, and evidence gates without touching a
  device.
- `tools/prepare_signed_release.py` signs an image, asks picotool to verify it,
  and creates four ordered OTP input files plus a SHA-256 receipt. It does not
  program them.

## Key ceremony and release preparation

Generate independent secp256k1 release and offline-recovery signing identities
outside the repository. Keep private keys out of source control. Record the
picotool-compatible SHA-256 public-key digests in slots 0 and 1 of
`otp-policy-v1.json`, then set the two corresponding `release_evidence` flags
only after an independent comparison.

Prepare each final ELF or UF2 with a deliberate semantic and rollback version:

```text
python3 tools/prepare_signed_release.py \
  --input <unsigned-image> \
  --output <new-signed-image> \
  --private-key <release-private-key.pem> \
  --artifact-dir <new-receipt-directory> \
  --major <major> --minor <minor> --rollback <monotonic-version>
```

The command refuses to overwrite an image or artifact directory, refuses an
unrecorded/mismatched release key, includes full-SRAM clearing in the signed
image metadata, and checks picotool's signature and rollback report. Run it once
for the factory ELF and once for the USB-recovery UF2 using the same version.

## Irreversible ceremony boundary

The numbered JSON files are deliberately staged rather than combined:

1. Program and independently read back both boot-key hashes.
2. Mark slots 0 and 1 valid and slots 2 and 3 permanently invalid.
3. After ordinary firmware first setup creates the device roots and verifies
   their read-back (no image swap required), apply pages 59 and 60 access
   permissions using picotool's dedicated permissions command.
4. Only after signed normal boot, signed USB recovery, rollback, permission,
   power-cut, and debug tests pass, apply the final critical boot flags. Secure
   boot and permanent debug disablement are in this last file.

The actual hardware commands are intentionally absent. They must live in a
separately reviewed manufacturing work instruction with device identity,
operator confirmation, independent read-back, and reject/quarantine handling.
Run `python3 tools/verify_otp_policy.py --release` before that ceremony; any open
gate is a stop condition.

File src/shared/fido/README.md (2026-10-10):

# Portable FIDO engine and SD journal

Firmware uses the bounded storage callbacks in `fido_engine.h` with
`fv_fido_journal` from `fido_journal.h`. The 824 KiB filesystem stays on SD; no
complete plaintext image is allocated. The 1 MiB private region and USB geometry
are unchanged. See [format, migration and recovery](../../../docs/AI/v2-fido-storage.md)
and [user-visible behaviour](../../../docs/FIDO2.md).

The engine supports 512 resident slots, built-in UV, physical approval, zero
signature counters, host credential management and local management. SD callbacks
are serialized by the firmware worker. Close the engine and journal before lock,
credential changes or media replacement. A storage failure faults the session.
Record views have function-scoped ownership; verification tokens have dedicated
session buffers. No API returns a borrowed pointer into SD storage.

The old RAM-image/snapshot API is retained for compatibility tests and migration
fixture generation, not firmware operation. Never use it to write a converted
card. Import provenance remains in
[the vendor notes](../../../third_party/pico_fido/README.fuse-vault.md).

## Build and test

```sh
cmake -S . -B build-fido \
  -DFV_MBEDTLS_DIR=/home/adam/pico-sdk/lib/mbedtls \
  -DFV_ENABLE_FIDO_ENGINE=ON -DCMAKE_BUILD_TYPE=Debug
cmake --build build-fido -j4
ctest --test-dir build-fido --output-on-failure
```

Python `fido2` and `cryptography` are required. Use `-DFV_SANITIZERS=ON` for
ASan/UBSan; in this traced environment set `ASAN_OPTIONS=detect_leaks=0` (no leak
check claim). Journal interruption tests take several minutes. Hardware acceptance
still requires actual power cuts, timing and peak RAM under combined USB/FIDO use.

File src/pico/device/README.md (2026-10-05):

# RP2354 security bring-up firmware

A separate **development image** linking the actual portable vault lifecycle to
four-lane SD, SRAM cipher code and Pico SHA. Core 0 services USB; core 1 owns
crypto, entropy, SD and device authority. USB identity is `cafe:4022`, product
`Fuse Vault SECURITY DEBUG`, distinct from the existing pipeline benchmark.

## Available bring-up tests

- Read-only OTP snapshots: all 64 pages' blank/programmed/all-ones/unreadable row
  counts, raw public lock rows, lock-read errors and current software locks.
- Laptop snapshot comparison: decoded permanent Secure/Non-secure/bootloader
  locks, key-selection settings, redundant-copy agreement and occupancy changes.
- TRNG-backed AES-256 CTR-DRBG, with built-in health checks enabled, source-error
  propagation, repeated/zero/all-ones block checks and fresh reseeding per request.
- Full envelope seal/unlock/wrong-credential timing at a chosen PBKDF2 count.
- Destructive SD test: create a two-layer AES/Camellia vault, unlock, write 1 MiB,
  lock/reopen/read/verify, change credential, reject the old credential, then
  reopen and verify all data using the new credential. Batches are 32 KiB.

The persistent path stores root/token in fixed application OTP pages and attempts/
header authority in an authenticated flash journal. See the
[allocation, record format and debug workflow](../../../docs/AI/v2-persistent-authority.md).
These operations are implemented and host-tested; physical OTP programming and
power-cycle verification remain pending. No automatic initial provisioning occurs.

The separate `vault-test` command still uses RAM-only enrollment and now refuses
an already provisioned device. All test credentials are public literals. No VMK,
root, token, entropy bytes or raw data-row contents are returned. The existing
benchmark image/protocol remains separate.

## Build and remove debug commands

```sh
cmake -S src/pico/device -B build-pico-security \
  -DPICO_SDK_PATH=/home/adam/pico-sdk -DPICO_NO_PICOTOOL=1 \
  -DCMAKE_BUILD_TYPE=Release -DFV_DEBUG_OTP_INSPECT=ON \
  -DFV_DEBUG_ENROLLMENT=ON
cmake --build build-pico-security -j4
v1/firmware/build/_deps/picotool/picotool uf2 convert \
  build-pico-security/fuse_vault_security.elf \
  build-pico-security/fuse_vault_security.uf2 --family rp2350-arm-s --platform rp2350
```

The archived picotool is reused only as a build executable. An installed picotool
can be substituted. Source dependencies stay in V2 / the configured Pico SDK.

`FV_DEBUG_OTP_INSPECT` and `FV_DEBUG_ENROLLMENT` default **OFF**. The OFF build
excludes inspection and the prepare-flash/provisioning/create/check/change/wrong/destroy command
handlers; binary symbols and command strings were checked. Internal final-attempt
destruction remains enabled. This entire image is a debug harness: disabling these
options alone does not make it a production application. There are no arbitrary
OTP-row, raw-memory, secret-export or software-lock-change commands.

## First-run commands

Flash `build-pico-security/fuse_vault_security.uf2` using BOOTSEL, then reconnect
normally. Use its `/dev/serial/by-id/usb-Fuse_Vault_Fuse_Vault_SECURITY_DEBUG_...`
port (the tool validates the distinct USB VID/PID).

```sh
python3 src/host/tools/security_probe.py --port "$PORT" info
python3 src/host/tools/security_probe.py --port "$PORT" snapshot --out results/otp-before.json
python3 src/host/tools/security_probe.py --port "$PORT" rng
python3 src/host/tools/security_probe.py --port "$PORT" kdf --iterations 60000
python3 src/host/tools/security_probe.py --port "$PORT" vault-test --erase-sd
```

The last command destroys the SD layout: headers at LBA 0/8, metadata at 2064,
and 2,048 payload sectors. It leaves the private-object reservation untouched,
but the card's previous partition/filesystem layout is no longer usable. No writes
occur from info/snapshot/rng/kdf themselves. On boot, an enrolled device can finish
a previously pending final-attempt destruction; virgin devices are never enrolled
automatically.

The KDF command is a configurable timing diagnostic. Enrollment and the vault
self-test now use the agreed **60,000 iterations**; persistent header acceptance
bounds are exactly 60,000. Previous hardware timing measured about 1.40 seconds.

For persistent provision/create/power-cycle/check/rotation, follow the
[persistent workflow](../../../docs/AI/v2-persistent-authority.md#debug-workflow).
Capture a new snapshot after provisioning or advancement:

```sh
python3 src/host/tools/security_probe.py --port "$PORT" snapshot --out results/otp-after.json
python3 src/host/tools/security_probe.py diff results/otp-before.json results/otp-after.json
```

Snapshot files are created exclusively, so a baseline cannot be overwritten by
mistake. Diffs reject different device identities. An unreadable row/page is not
reported as blank, erased or securely destroyed. Occupancy is aggregate: programming
more bits in an already-programmed row may leave counts unchanged. Lock rows show
individual redundant copies so partial lock transitions can be seen. These tools
do not by themselves verify irreversible destruction or authorize an allocation.
Factory/boot/key-reserved pages must be identified before selecting application slots.
No data-row hashes are exported as an indirect secret fingerprint.

The protocol is bounded ASCII requests and JSON responses, one command at a time.
Malformed/oversized framing requires reconnect. A timeout does not retry a command;
a running SD test can continue after USB disconnect and erases its temporary keys
when it finishes. None of these commands is intended as a production host API.

## Entropy implementation and remaining work

`src/pico/platform/entropy.c` uses chain 0, sample period 100 system clocks and
normal VN/CRNGT/autocorrelation checks. Each 192-bit collection has a one-second
bound; health failure/timeout aborts the operation. These development parameters
follow [RP2350 datasheet §12.12](https://datasheets.raspberrypi.com/rp2350/rp2350-datasheet.pdf).
`pico_rand` is not linked or used. Mbed TLS CTR-DRBG consumes 48 entropy bytes for
initialization/reseeding and reseeds every generation request. Its standard
self-test runs before bring-up use. Diagnostics return status/timings only.

This is an implemented candidate entropy adapter, not a claim of characterized
min-entropy, certification or hardware-tested reliability. The first board run passed the source smoke test; qualification still includes temperature,
clock and supply conditions and failure recovery policy. There is no fallback to
SDK PRNG, serial numbers, timers or test seeds on entropy failure.

The current allocation is root page 16, token pages 17–24, with flash offsets
0x1fe000–0x1fffff reserved by both V2 firmware linker layouts. Commands recheck live
contents/permissions and verify writes. Permanent access locks are deliberately
unchanged during development. Hardware interruption testing, Secure access/debug
policy and protected RAM isolation are tracked in the
[production checklist](../../../docs/AI/production-checklist.md).

More passing RNG smoke tests show reliable integration, not entropy quality. We
rely on vendor source design and focus remaining checks on failure handling and
the intended board operating conditions.

## Validation

- 19 desktop tests pass, also under ASan/UBSan. They include entropy failures,
  OTP inspection contracts, CLI wrong-device/debug-option guards, byte-cut journal
  failures, token lifecycle and a full vault pipeline using the persistent model.
- ARM builds succeed with both debug options enabled and both disabled. The debug
  ELF has 129,484 bytes BSS, including a 32 KiB worker stack and 32 KiB data buffer.
  Physical runtime stack verification remains a release task.
- [First hardware run, 2026-09-17](../../../results/security-bringup-20260917.md): five
  RNG diagnostics, three 60,000-iteration envelope timing runs and three complete
  SD lifecycle runs passed. Median unlock: 1.40151 s. This used the previous
  RAM-authority firmware; OTP snapshots matched and no OTP writes were performed.
- The new persistent image still needs flashing, real provisioning and power-cycle
  tests. Host failure injection does not prove physical OTP/ECC behavior.

## Reused-board initialization (2026-09-18)

The first persistent-image connection showed blank root/token OTP pages but a
failed authority open. No provisioning was attempted. The updated image adds
occupancy fields to `state` to distinguish stale flash from an OTP/read failure,
and an explicit `prepare-flash --confirm-device ID` command guarded by entirely
blank/readable enrollment OTP. See the
[hardware run record](../../../results/security-persistence-20260918.md). The cause
is not yet confirmed; a new flash is needed to run those diagnostics.

## Startup isolation image

`FV_DEBUG_STARTUP=ON` (default OFF) delays worker launch and authority recovery
until an explicit `START` command. This is diagnostic-only: it deliberately delays
pending-policy recovery and must not appear in production. Build output lives in
`build-pico-security-startup/`; journal reservation and OTP allocation are unchanged.

Use `python3 src/host/tools/security_startup.py --port "$PORT" boot` for core0 startup stage
and USB A/C sense inputs; `start` requests the worker. Neither unlocks. START runs
normal authority recovery, which can complete an already pending destruction.
Normal `security_probe.py` commands work after stage 14. Stages: 0 awaiting START,
1 core0 flash-lockout setup, 2 core1 launch, 10 worker entered, 11 worker lockout
ready, 12 authority adapter ready/open starting, 13 open finished/recovery starting,
14 worker ready. The existing USB mux selection/interlock remains unchanged.

### Automatic boot trace fallback

`FV_DEBUG_BOOT_TRACE=ON` requires `FV_DEBUG_STARTUP=ON`. This separate diagnostic
arms a five-second ROM BOOTSEL watchdog before SDK clock initialization and cancels
it when USB mounts. It records a tagged progress stage in watchdog scratch0. Other scratch fields
were unreliable across the ROM/load path and are no longer treated as trace data. Stages: 1 early runtime, 2 clocks returned,
3 main entered, 4 before TinyUSB init, 5 TinyUSB returned, 6 USB mounted;
7 early peripheral resets returned, 8 early USB power-down returned,
254 watchdog arming returned an error.
On a subsequent warm image load, BOOT exposes the previous trace only if its magic
matches. Do not unplug after a fallback: power loss clears the retained trace.
The watchdog cannot capture faults before its early hook executes. This is a
diagnostic mechanism, not a production recovery policy. It never starts the
worker, unlocks, provisions or changes the journal by itself.

Trace-only link wrappers also mark crystal oscillator entry/return (10/11),
system PLL (12/13), USB PLL (14/15) and voltage adjustment (16/17). They preserve
SDK calls and do not change clocks/voltages beyond the original initialization.
Observed tagged stage 8 on cold boot narrowed the failure to SDK clock setup.

Clock-switch/tick checkpoints: entry `20+2*clock_index`, return `+1`; tick entry
`60+2*tick_index`, return `+1` (SDK enum values). Trace-only `security_startup.py
--port "$PORT" reboot` requests a normal ROM restart and is accepted only while
stage 0 and START has not been requested. It does not run authority callbacks.
A software restart is useful for reproduction, not proof of physical cold boot.

## USB mass-storage bring-up

The opt-in `FV_USB_MSC` + `FV_DEBUG_SESSION` build exposes an existing encrypted
vault as a removable disk with CDC debug lock/unlock. See [USB_STORAGE.md](USB_STORAGE.md)
for the build, host commands, filesystem setup, lock behaviour and limitations.

## Device UI / full-card setup

See [DEVICE_UI.md](DEVICE_UI.md) for the firmware-owned framebuffer, GTK debug
viewer, physical D-pad, full-capacity initialization, failure policy settings and
USB-C-preferred mux. This build preserves existing volumes until explicit erase
and setup; it does not silently enlarge the earlier 1 MiB test vault.

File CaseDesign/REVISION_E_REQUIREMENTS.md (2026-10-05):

# Prototype E requirements

D physical feedback: latch failed to catch and was too flimsy. Slimmer dimensions,
SD bay and end caps were positively received. Printer has a 0.4 mm nozzle.

User direction: use small sloping snaps on shell-alignment features, with shallow
matching recesses. Moderate strength is required because the closed shell secures
the USB-C collar. Opening is occasional; hundreds of service cycles are unnecessary.
The end covers must not be the only mechanism holding the shell closed.

E implements four short supported snap posts, retains the original USB-C hooks,
and removes D's isolated spring arm and support web. Standard engagement is 0.25 mm;
0.15 and 0.35 mm fit samples are also included. Board supports remain independent.
Only the base/lid need reprinting. D body envelope, controls, collar and covers
are retained. CAD clearance/capture checks are not a physical strength result.

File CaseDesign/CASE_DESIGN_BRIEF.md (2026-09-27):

# V2 enclosure design brief

**Current requirements:** [REVISION_B_REQUIREMENTS.md](REVISION_B_REQUIREMENTS.md)
records prototype-A print feedback and the new joystick protection, back-button
redesign and USB end caps. It supersedes the older control/closure proposals below.
Prototype A exists and has been printed; the remainder of this document preserves
the earlier drawing evidence and planning assumptions, not its current build status.

Updated 2026-09-21 following the user's screen datasheet and enclosure requirements.

## Agreed requirements

- Provide structural support for the long USB-C plug at its narrow PCB attachment.
- Fit a separate joystick cap and a captive plunger for the back button.
- Keep the microSD card inside the enclosure, with no external removal opening.
- Use a two-piece enclosure. The first prototype will use screws for repeatable
  assembly and adjustment; snap closure can be reconsidered after fit checks.
- Locate the PCB with selected clear edge supports and matching lid restraints.
  Case screws join external-to-PCB bosses, not the occupied connector locating holes.

## Drawing evidence

Local copies of the manufacturer PDFs are in `datasheets/`. Source URLs and
SHA-256 digests are in `datasheets/manifest.json`.

### Display: N096-1608TBBIG09-C08, revision A

PDF page 5, Mechanical Drawing, specifies:

- Backlight/module outline: 27.9 +/-0.15 by 13.5 +/-0.15 mm.
- Thickness: 1.5 +/-0.1 mm; provisionally reserve 1.6 mm before mounting adhesive
  and assembly clearance.
- Active area: 21.7 by 10.8 mm. This is offset along the long axis, not centred
  within the module: 1.7 mm from the end opposite the flex, leaving 4.5 mm at
  the flex end. Across the width the nominal margins are 1.35 mm.
- Flex extension from the module end: 23.0 +/-0.5 mm in the flat drawing.
- Flex contact end: 4.5 +/-0.07 mm wide; 0.3 +/-0.03 mm thick including stiffener.

Page 4's summary instead lists a 27.95 mm module length and 1.5 mm maximum
thickness. Retain this discrepancy: use the dimensioned drawing plus its
tolerances for provisional clearance, and verify the supplied module before
finalising its seat. The existing 27.9 by 13.5 silkscreen guide agrees with the
drawing's nominal outline. Its existing 2.5 mm thickness is an obsolete assumption.

The expected flex exit faces the PCB cutout (negative X), but installed orientation
and folded route must be checked. With that orientation, the active area would
start 4.5 mm from the module's negative-X edge and end 1.7 mm before its positive-X
edge. Do not centre a bezel opening on the module automatically. Provide mounting
support under the module perimeter/backlight structure without point loading the
glass or pinching the flex. The flat flex length does not establish bend radius.

### USB-A: SHOU HAN AM90

Manufacturer drawing on PDF page 1:

- Main shell height: 4.50 +/-0.10 mm.
- Mating shell width: 12.00 +/-0.10 mm.
- Rear/attachment width: 12.52 +/-0.15 mm.
- Body length shown: 18.75 +/-0.15 mm.
- Rear view also shows a 5.85 +/-0.10 mm overall extent including attachment
  features; 4.5 mm is not an all-features envelope.

The current 4.5 mm shell height is therefore supported by the drawing. The model
still needs a separate mating shell and rear attachment envelope, plus registration
of the seating plane against the PCB footprint. Its simple 12.4 mm wide box is
not an accurate representation of both regions.

### USB-C: XKB U261-121N-4BS2S

Manufacturer drawing, PDF page 1, revision A1:

- Main shell height: 2.40 +/-0.03 mm.
- Main shell width: 8.25 +/-0.05 mm.
- Rear width: 8.75 +/-0.25 mm; front view also shows an 8.60 mm extent.
- Overall length: 13.61 +/-0.25 mm.
- Side view shows 11.25 mm to the rear of the principal shell.
- Rear view places the solder-contact plane 0.95 mm above the shell bottom.
  Interpreting that plane as the PCB top gives nominal shell bounds Z=0.65 to
  3.05 mm for a 1.6 mm PCB, before solder seating variation. Confirm that datum
  interpretation and footprint registration before generating the close-fitting cradle.

The current reference instead uses Z=-0.4 to 2.0 mm, from an assumed
`bottom_from_surface=-2`. Do not size the support from that reference without
correcting the mounting datum. The 2.4 mm shell height itself is supported.

## USB-C support construction

Use an integrated lower cradle and a matching lid saddle around the rear metal
shell, with side ribs tied into the main case. This provides a load path from the
connector shell into the case, reducing dependence on the narrow PCB attachment.
Provide nearby PCB restraints so the board cannot slide under insertion or
withdrawal loads. Avoid bearing on pins, solder fillets, or small surface parts.

The shroud must stop behind the plug's required mating region. Neither the drawing's
overall length nor the shell height establishes how much may safely be covered.
Keep its length, shell clearance, and shell-to-PCB offset adjustable and verify full
insertion in a real receptacle. Do not assume a long cosmetic sleeve provides support.
The first fit sample should include the cradle, its lid saddle, and the local PCB
supports, so both connector seating and receptacle clearance can be checked together.

## Controls and retention

- Joystick: allow a provisional 3 mm displacement from neutral in any lateral
  direction (conservative interpretation of the user's estimate). This is not a
  verified travel specification. Clearance at the lid depends on shaft height and
  cap geometry; include a separate allowance for centre-press travel. The existing
  10 mm motion diameter only approximates shaft clearance and does not reserve a cap.
- Back button: use a guided, captive plunger with a retaining flange, a small
  unpressed gap, and a mechanical travel stop. SW4 is the provisional target; confirm
  its function before freezing the lid. Neither the required stroke nor plunger
  length is established solely by the switch's total height.
- SD: install the card before case closure. Remove the external withdrawal corridor
  from the enclosure's design constraints, but retain an installed-card envelope and
  a gap that avoids pressing the push-push mechanism. A covered card is not the same
  as a modelled card: the current reference represents only its socket.
- Retention: locate supports using both PCB faces. Match the upper restraints to
  lower supports so screw tightening does not bend the board. Use case-to-case stops
  to control closure; the display must not serve as a clamping spacer.

## Reference status and next construction step

This brief supersedes the old display, USB verification, and externally removable
SD assumptions. Existing `parameters.json`, STEP/STL exports, and `validation.json`
remain reference revision 1; they have not been regenerated by this evidence review.
They must not be described as already corrected or validated against these drawings.

Before building the fit-test tray, update and regenerate the reference with the
screen drawing envelope, separate USB shell/attachment envelopes, corrected USB-C
datum, installed SD card allowance, and cap movement envelope. Then build the
screw-closed tray/lid with the USB-C cradle as a required feature. Printer/material
tolerances and the physical screen/flex installation remain prototype fit checks.

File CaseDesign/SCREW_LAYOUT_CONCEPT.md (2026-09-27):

# V2 screw layout concept

2026-09-21. Planning sketch, not a printable or mechanically validated design.

Four screws can join the enclosure outside the existing PCB. Use one pair near
each end of the board, with continuous rounded side walls enclosing all four posts.
This avoids separate exterior ears and requires no board drilling or V3 revision.

All coordinates use the existing Gerber XY origin; dimensions are millimetres.

| Concept | Post envelope diameter | Screw centres | Approximate main body |
|---|---:|---|---|
| M2 | 6.5 | X=8 and 65, each at Y=3.75 and -24.987 | 80 x 36.737 |
| M3 | 8.5 | X=8 and 65, each at Y=4.75 and -25.987 | 80 x 40.737 |

The main body runs X=-3.5 to 76.5 with 5 mm plan corner radii. The USB-C cradle
extends another 1 mm at the nose. Exposed plugs are excluded from body length.
These are illustrative budgets, not minimum achievable dimensions.

Each post is 0.5 mm clear of the nominal PCB edge. Its surrounding case extends
0.75 mm beyond its circular envelope; the post itself supplies the local bulk.
The four post circles do not intersect any of the existing component-envelope XY
rectangles, checked for both concepts. This does not check cap sweep, installed SD
card, flex folds, screw access, or a complete three-dimensional assembly.

The section illustrates screws entering from underneath and engaging captive nuts
in the lid. Screw holes and nut pockets must be specified against selected hardware;
the 2.3/3.4 mm drawn clearance bores and post diameters are provisional. This is not
a heat-set insert sizing recommendation: insert body diameter and surrounding
plastic requirements depend on the selected insert. See manufacturer guidance:
https://www.spirol.com/resources/white-papers/how-to-design-the-proper-hole-for-heat-ultrasonic-inserts/

The PCB sits on separate ledges with matching upper restraints. Put these only on
confirmed clear edge regions, and stop case closure on the posts, not the PCB or
screen. The section is schematic and does not establish case height or screw length.

USB-C support remains mandatory: lower cradle plus upper saddle around the rear
shell, tied into the case. The sketch places it around X=-4.5 to 1.2, leaving about
7.26 mm of the present model's plug ahead of the support. This is a proposed fit-test
position, not a verified USB insertion requirement. Blend the nose into the case,
check against real receptacles, and use the corrected USB-C Z datum in the brief.

Recommendation: start with the M2 concept. Captive nuts permit repeated opening
without relying on printed machine threads. A V3 with dedicated mounting holes
could reduce case width, but V2 need not wait for that board revision.

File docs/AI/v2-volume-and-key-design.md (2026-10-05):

> **Implementation update:** [volume layout version 2](v2-lazy-metadata.md)
> adds a small initialization bitmap before the tag area. New vaults use lazy
> metadata initialization; original version-1 volumes keep their existing layout.

# V2 volume format and key lifecycle — review draft

**Status: four-slot share envelope and portable vault lifecycle implemented and tested.
TRNG/DRBG, OTP enrollment/destruction and flash authority are implemented for
hardware testing; production access protections remain pending.
The persistent format is NOT frozen.**

This is the next step after the working, benchmarked USB → cipher stack →
HMAC/metadata → SD path. It replaces public benchmark keys with a persistent,
random vault master key (VMK), a protected header and a real session lifecycle.
It does not add FIDO, a filesystem, per-sector rollback protection or duplicated
payloads. The existing benchmark firmware remains unchanged.

## 1. What this gives us

Create a volume once, write data, restart the device, unlock it, and reconstruct
exactly the same pipeline and keys. A password change rewraps the VMK; it does
not re-encrypt the data. Locking removes the working keys from RAM.

There are three distinct types of key:

| Key | Purpose | Lifetime/location |
|---|---|---|
| Device root, 32 random bytes | Binds unlock to this device | Protected device state; never SD |
| VMK, 32 random bytes | Root of this volume's working keys | Wrapped on SD; temporarily in RAM |
| KEK, 32 derived bytes | Encrypts/authenticates the stored VMK | Temporary during create/unlock/change |

Working keys derived from the VMK serve each XTS layer and sector HMAC separately.
The credential is not a data-encryption key. Slow password derivation runs only
at authentication, never during reads or writes.

The security boundary stays as agreed in [device-state placement](v2-security-state.md):
SD possession/manipulation must not reveal secrets or reset authentication.
Deletion, corruption and replay of valid historical data are accepted. Device-root
protection, trusted firmware and debug policy are necessary assumptions; simply
putting a secret in flash does not establish those protections.

## 2. Decisions and remaining gates

Accepted: random device root and VMK; device-bound credential derivation; separate
working keys; no separate password verifier; credential changes preserve VMK;
explicit session erasure; device-local charged attempts and header authority.

- PBKDF2-HMAC-SHA-256 is the first KDF to implement/benchmark. Production iteration
  counts remain unset until actual RP2354 calibration targets 1–2 seconds, about
  3 seconds maximum. KDF ID/version remain explicit.
- AES-GCM is **not** the sole/default VMK wrapper. The
  [stack-aware envelope candidate](v2-vmk-envelope-proposal.md) specifies a
  shares + standardized key-wrap + outer-HMAC construction. The user accepted
  shares and four slots; portable implementation and independent reference vectors
  are present. Independent security review remains outstanding.
- Authentication policy is configurable and anchored. Default: ten attempts,
  **cryptographic destruction**. Persistent lockout has a separate action ID;
  future delay actions are reserved, rejected until implemented. No unlimited mode.
- Device failure/root loss may destroy access. No recovery keys, VMK export,
  manufacturer/cloud recovery or cross-device root cloning are introduced.
- One active vault per device initially. Keep the 1 MiB future-object reservation.
- The [device-state/destruction proposal](v2-device-state-proposal.md) defines the
  journal, policy codec, final-attempt semantics and irreversible token invalidation
  candidate. Physical OTP access/lock sequence and record encoding require review.

`credential_generation` means **which authentication envelope is authoritative**.
Advance it on credential/profile/KDF changes, rewrap/envelope replacement and
relevant authentication-policy changes. Never advance it for file writes/deletes,
sector tags, FIDO/SSH object creation/deletion or ordinary private-object activity.
It is not a whole-volume generation. It must not wrap around.

The boundary also explicitly prohibits extra attempts or revival after destruction
through SD rollback. Historical encrypted data/private objects may be replayed
where they do not bypass device authentication. No whole-volume/object hashes,
Merkle trees or per-write monotonic counters are added.

Standard primitive references: [PBKDF2, RFC 8018](https://www.rfc-editor.org/rfc/rfc8018.html)
and [HKDF, RFC 5869](https://www.rfc-editor.org/rfc/rfc5869.html). The application
protocol is our review-stage design, not a standards-certified composition.

## 3. Encoding rules

All offsets below are byte offsets. Integers are unsigned little-endian.
Encode/decode explicitly; never persist a C struct, its padding or pointers.
Ranges written as `a:b` include a and exclude b.

`||` means concatenate. `LE16`, `LE32`, `LE64` encode exactly that many bits.
`L(s)` means the exact ASCII bytes of the quoted label followed by one zero byte.
Labels are case-sensitive. Hashes are SHA-256; HMAC tags are full 32 bytes.

The storage library takes a byte string plus explicit length for `user_secret`:
no implicit terminator, trimming or Unicode conversion. Propose nonempty, at most
256 bytes. Text input profile 1 is UTF-8 without normalization. Navigation input
profile 2 is a sequence of bytes: up=1, down=2, left=3, right=4, reserved legacy input=5; back
edits input and submit is out-of-band. The UI must use the selected profile
consistently. Secret input comes from the on-device UI in production; desktop
secret input is only a test adapter. Neither logs credentials nor derived keys.
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

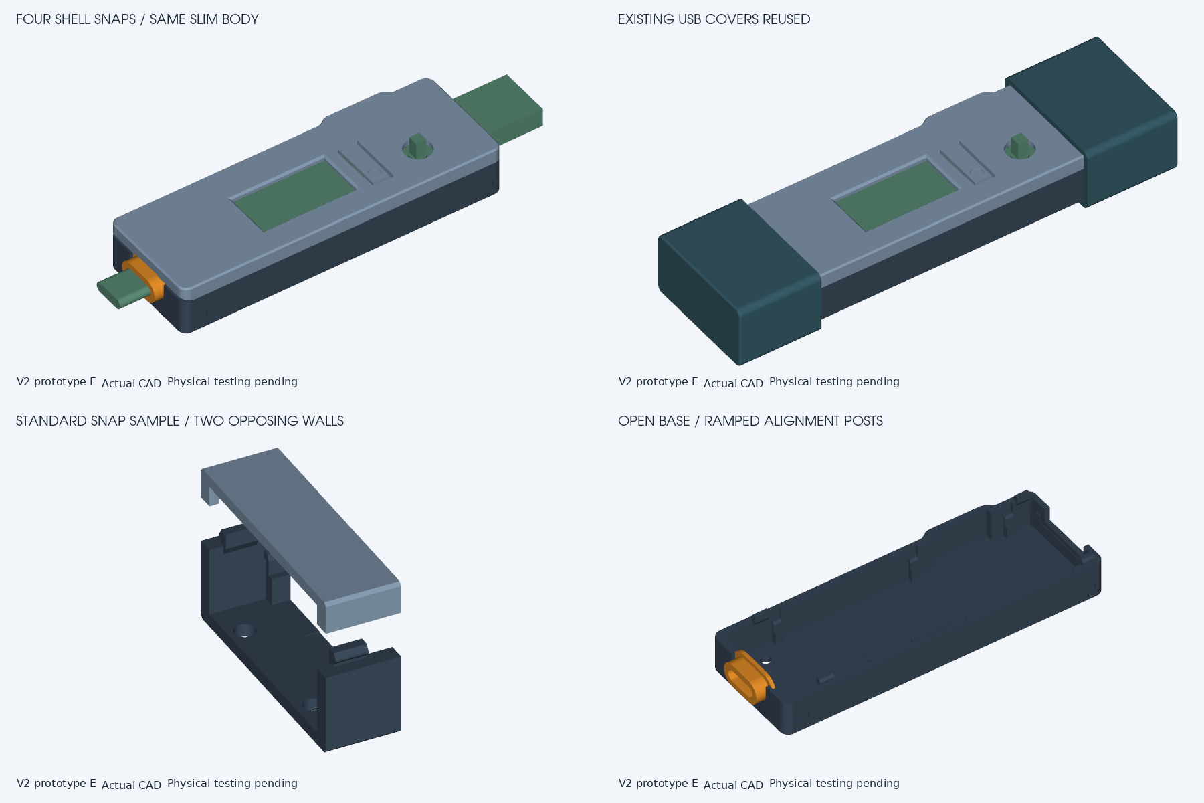
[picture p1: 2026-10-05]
CaseDesign/prototype-e/preview.png

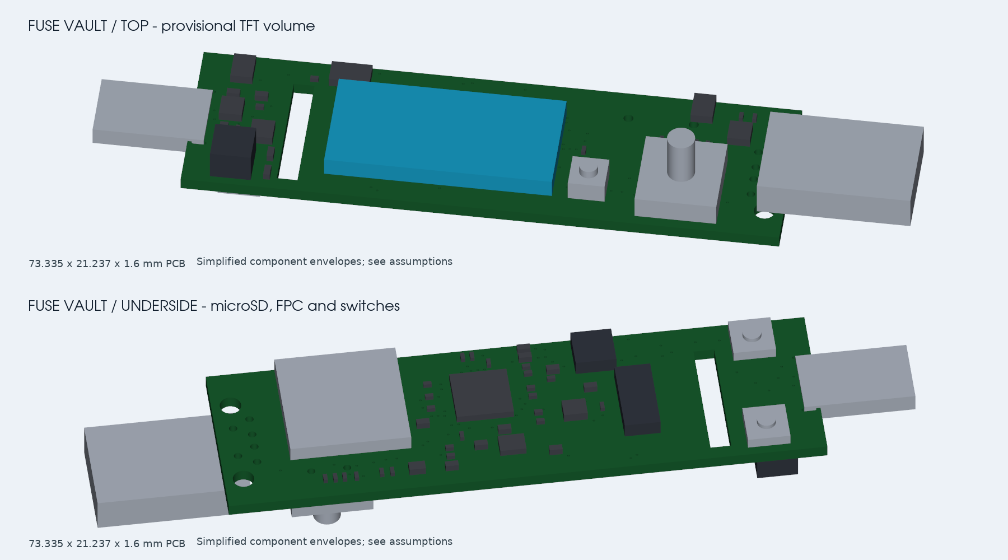
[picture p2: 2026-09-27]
CaseDesign/reference_preview.png

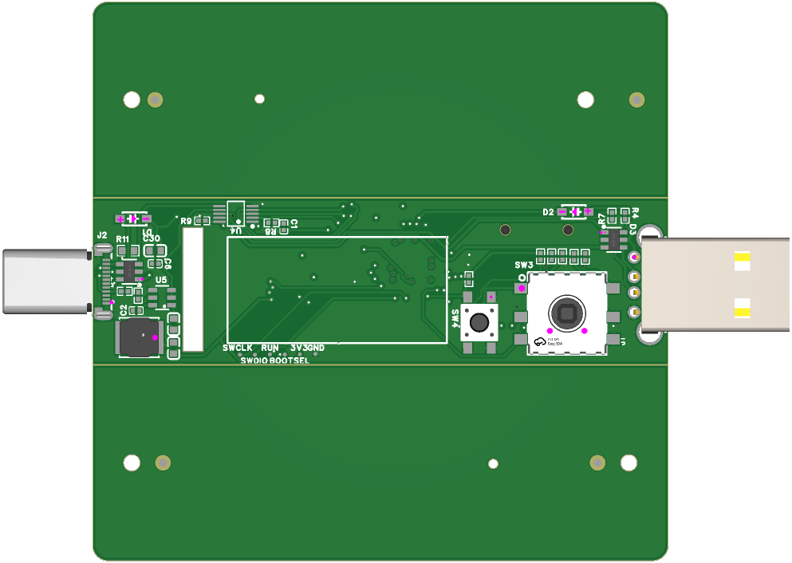
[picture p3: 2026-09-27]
CaseDesign/source/top.png

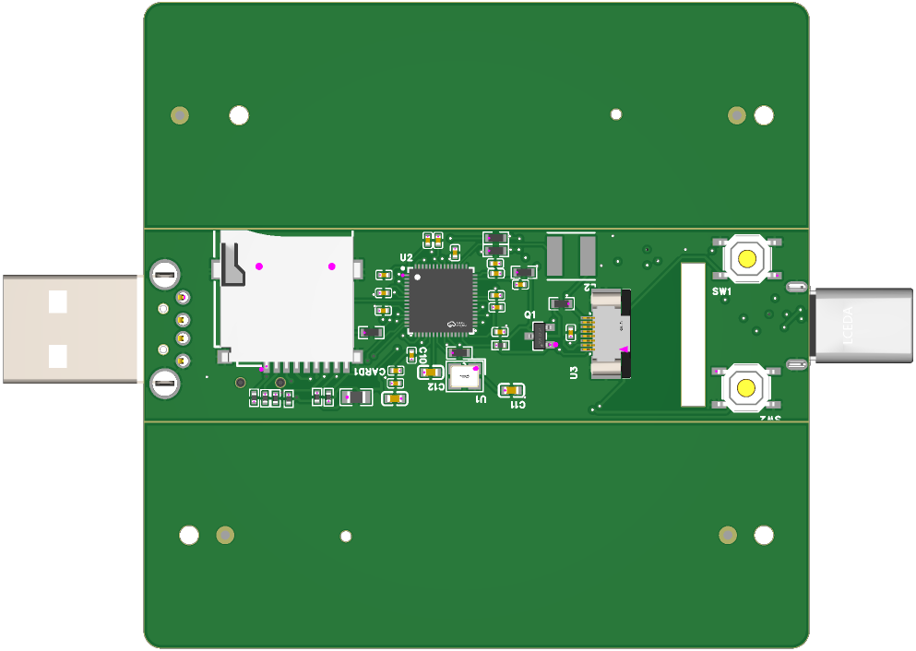
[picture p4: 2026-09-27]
CaseDesign/source/bottom.png

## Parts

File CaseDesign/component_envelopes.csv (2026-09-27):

name | side | xmin | xmax | ymin | ymax | zmin | zmax | evidence
PCB | both | -0.127 | 73.208 | -21.237 | 0.0 | 0.0 | 1.6 | Exact original GKO and unique Excellon drill/slot geometry; nominal thickness
C1 | T | 24.007 | 24.507 | -4.183 | -3.183 | 1.6 | 2.2 | CPL centre/rotation; footprint package envelope including lead span where named; height assumption
C2 | T | 4.961 | 5.961 | -14.601 | -14.101 | 1.6 | 2.2 | CPL centre/rotation; footprint package envelope including lead span where named; height assumption
C3 | T | 9.825 | 10.625 | -16.867 | -15.267 | 1.6 | 2.5 | CPL centre/rotation; footprint package envelope including lead span where named; height assumption
C4 | T | 9.822 | 10.622 | -19.915 | -18.314999999999998 | 1.6 | 2.5 | CPL centre/rotation; footprint package envelope including lead span where named; height assumption
C5 | B | 38.651 | 39.151 | -3.128 | -2.128 | -0.6 | 0.0 | CPL centre/rotation; footprint package envelope including lead span where named; height assumption
C6 | T | 7.373999999999999 | 8.373999999999999 | -8.632 | -8.132 | 1.6 | 2.2 | CPL centre/rotation; footprint package envelope including lead span where named; height assumption
C7 | B | 33.966 | 34.966 | -4.0600000000000005 | -3.56 | -0.6 | 0.0 | CPL centre/rotation; footprint package envelope including lead span where named; height assumption
C8 | B | 46.275 | 47.275 | -7.323 | -6.823 | -0.6 | 0.0 | CPL centre/rotation; footprint package envelope including lead span where named; height assumption
C9 | B | 33.848 | 34.848 | -7.577 | -7.077 | -0.6 | 0.0 | CPL centre/rotation; footprint package envelope including lead span where named; height assumption
C10 | B | 43.438 | 43.938 | -14.421 | -13.421 | -0.6 | 0.0 | CPL centre/rotation; footprint package envelope including lead span where named; height assumption
C11 | B | 31.903000000000002 | 33.503 | -18.189 | -17.389 | -0.9 | 0.0 | CPL centre/rotation; footprint package envelope including lead span where named; height assumption
C12 | B | 40.794000000000004 | 42.394000000000005 | -16.21 | -15.41 | -0.9 | 0.0 | CPL centre/rotation; footprint package envelope including lead span where named; height assumption
C13 | B | 25.912 | 26.412 | -11.93 | -10.93 | -0.6 | 0.0 | CPL centre/rotation; footprint package envelope including lead span where named; height assumption
C14 | B | 44.96 | 45.96 | -17.257 | -16.757 | -0.6 | 0.0 | CPL centre/rotation; footprint package envelope including lead span where named; height assumption
C15 | B | 44.921 | 45.921 | -15.868 | -15.368 | -0.6 | 0.0 | CPL centre/rotation; footprint package envelope including lead span where named; height assumption
C16 | B | 44.748 | 46.348 | -19.098000000000003 | -18.298000000000002 | -0.9 | 0.0 | CPL centre/rotation; footprint package envelope including lead span where named; height assumption
C17 | B | 31.211 | 32.211 | -6.385 | -5.885 | -0.6 | 0.0 | CPL centre/rotation; footprint package envelope including lead span where named; height assumption
C18 | B | 46.314 | 47.314 | -9.267 | -8.767 | -0.6 | 0.0 | CPL centre/rotation; footprint package envelope including lead span where named; height assumption
C19 | B | 40.517 | 41.017 | -1.77 | -0.77 | -0.6 | 0.0 | CPL centre/rotation; footprint package envelope including lead span where named; height assumption
C20 | B | 33.878 | 34.878 | -5.164 | -4.664 | -0.6 | 0.0 | CPL centre/rotation; footprint package envelope including lead span where named; height assumption
C21 | B | 46.236 | 47.236 | -5.33 | -4.83 | -0.6 | 0.0 | CPL centre/rotation; footprint package envelope including lead span where named; height assumption
C22 | B | 33.458 | 34.458 | -11.602 | -11.102 | -0.6 | 0.0 | CPL centre/rotation; footprint package envelope including lead span where named; height assumption
C23 | B | 41.66 | 42.16 | -1.77 | -0.77 | -0.6 | 0.0 | CPL centre/rotation; footprint package envelope including lead span where named; height assumption
C24 | B | 33.79 | 34.79 | -8.886 | -8.386 | -0.6 | 0.0 | CPL centre/rotation; footprint package envelope including lead span where named; height assumption
C30 | T | 7.074 | 8.674 | -7.1240000000000006 | -6.324 | 1.6 | 2.5 | CPL centre/rotation; footprint package envelope including lead span where named; height assumption
CARD1 | B | 50.004000000000005 | 64.804 | -14.799999999999999 | -0.09999999999999964 | -2.0 | 0.0 | TF PUSH C393941 BOM. Body XY estimated from registered bottom render; CPL midpoint is not geometric body centre. All envelope dimensions provisional.
D1 | T | 3.7299999999999995 | 6.430000000000001 | -4.517 | -0.8169999999999995 | 1.6 | 2.8 | CPL centre/rotation; footprint package envelope including lead span where named; height assumption
D2 | T | 59.991 | 62.691 | -3.628 | 0.07200000000000006 | 1.6 | 2.8 | CPL centre/rotation; footprint package envelope including lead span where named; height assumption
D3 | T | 64.89399999999999 | 67.694 | -6.784 | -3.8839999999999995 | 1.6 | 2.8 | CPL centre/rotation; footprint package envelope including lead span where named; height assumption
D4 | T | 3.1719999999999997 | 5.972 | -10.847999999999999 | -7.947999999999999 | 1.6 | 2.8 | CPL centre/rotation; footprint package envelope including lead span where named; height assumption
J1 | T | 69.94999999999999 | 88.75 | -17.249 | -4.848999999999998 | 1.6 | 6.1 | AM90 identified by BOM. XY envelope reconciled with Gerber document outline and render. Height and seating Z assumed; verify drawing/part.
J2 | T | -11.757 | 1.8529999999999998 | -14.867999999999999 | -6.467999999999998 | -0.3999999999999999 | 2.0 | U261-121N-4BS2S identified by BOM. XY from document outline and render; 13.61 length provisional. Mid-mount seating and 2.4 height assumed; verify drawing/part.
L1 | T | 3.3419999999999996 | 8.341999999999999 | -20.28 | -15.280000000000001 | 1.6 | 5.6 | 5x5 footprint; 4.0 height inferred from ZENR5040 part series, provisional.
L2 | B | 23.615 | 28.615 | -5.5009999999999994 | -0.5009999999999994 | -2.0 | 0.0 | 5x5 footprint; 2.0 height inferred from NR5020 part series, provisional.
Q1 | B | 28.141000000000002 | 31.041 | -13.011000000000001 | -10.611 | -1.2 | 0.0 | CPL centre/rotation; footprint package envelope including lead span where named; height assumption
R1 | B | 33.617000000000004 | 35.217000000000006 | -1.416 | -0.6159999999999999 | -0.9 | 0.0 | CPL centre/rotation; footprint package envelope including lead span where named; height assumption
R2 | B | 52.582 | 53.082 | -19.042 | -18.042 | -0.6 | 0.0 | CPL centre/rotation; footprint package envelope including lead span where named; height assumption
R3 | B | 37.623000000000005 | 39.223000000000006 | -14.05 | -13.25 | -0.9 | 0.0 | CPL centre/rotation; footprint package envelope including lead span where named; height assumption
R4 | T | 67.441 | 67.941 | -2.786 | -1.786 | 1.6 | 2.2 | CPL centre/rotation; footprint package envelope including lead span where named; height assumption
R5 | T | 3.489 | 4.489 | -12.136 | -11.636 | 1.6 | 2.2 | CPL centre/rotation; footprint package envelope including lead span where named; height assumption
R6 | T | 5.465 | 5.965 | -12.946 | -11.946 | 1.6 | 2.2 | CPL centre/rotation; footprint package envelope including lead span where named; height assumption
R7 | T | 65.79 | 66.29 | -2.786 | -1.786 | 1.6 | 2.2 | CPL centre/rotation; footprint package envelope including lead span where named; height assumption
R8 | T | 22.186 | 23.186 | -3.425 | -2.925 | 1.6 | 2.2 | CPL centre/rotation; footprint package envelope including lead span where named; height assumption
R9 | T | 13.343 | 14.343 | -3.171 | -2.671 | 1.6 | 2.2 | CPL centre/rotation; footprint package envelope including lead span where named; height assumption
R10 | B | 33.617000000000004 | 35.217000000000006 | -2.8129999999999997 | -2.013 | -0.9 | 0.0 | CPL centre/rotation; footprint package envelope including lead span where named; height assumption
R11 | T | 3.628 | 5.228 | -7.131 | -6.3309999999999995 | 1.6 | 2.5 | CPL centre/rotation; footprint package envelope including lead span where named; height assumption
R12 | B | 60.785 | 61.285 | -19.094 | -18.094 | -0.6 | 0.0 | CPL centre/rotation; footprint package envelope including lead span where named; height assumption
R13 | B | 59.567 | 60.067 | -19.146 | -18.146 | -0.6 | 0.0 | CPL centre/rotation; footprint package envelope including lead span where named; height assumption
R14 | B | 58.424 | 58.924 | -19.169 | -18.169 | -0.6 | 0.0 | CPL centre/rotation; footprint package envelope including lead span where named; height assumption
R15 | B | 56.975 | 57.475 | -19.221 | -18.221 | -0.6 | 0.0 | CPL centre/rotation; footprint package envelope including lead span where named; height assumption
R16 | B | 53.852 | 54.352 | -19.019 | -18.019 | -0.6 | 0.0 | CPL centre/rotation; footprint package envelope including lead span where named; height assumption
R17 | B | 48.784 | 50.784 | -19.167 | -17.917 | -1.0 | 0.0 | CPL centre/rotation; footprint package envelope including lead span where named; height assumption
R18 | B | 47.324000000000005 | 48.92400000000001 | -11.821 | -11.020999999999999 | -0.9 | 0.0 | CPL centre/rotation; footprint package envelope including lead span where named; height assumption
R19 | T | 59.492 | 59.992 | -7.941 | -6.941 | 1.6 | 2.2 | CPL centre/rotation; footprint package envelope including lead span where named; height assumption
R20 | T | 58.095 | 58.595 | -7.941 | -6.941 | 1.6 | 2.2 | CPL centre/rotation; footprint package envelope including lead span where named; height assumption
R21 | T | 56.698 | 57.198 | -7.941 | -6.941 | 1.6 | 2.2 | CPL centre/rotation; footprint package envelope including lead span where named; height assumption
R22 | T | 62.361 | 62.861 | -7.993 | -6.993 | 1.6 | 2.2 | CPL centre/rotation; footprint package envelope including lead span where named; height assumption
R23 | T | 60.964 | 61.464 | -7.993 | -6.993 | 1.6 | 2.2 | CPL centre/rotation; footprint package envelope including lead span where named; height assumption
R24 | T | 47.573 | 48.073 | -10.831 | -9.831 | 1.6 | 2.2 | CPL centre/rotation; footprint package envelope including lead span where named; height assumption
R25 | B | 26.378 | 27.978 | -8.655000000000001 | -7.855 | -0.9 | 0.0 | CPL centre/rotation; footprint package envelope including lead span where named; height assumption
R27 | B | 33.409 | 34.409 | -13.077 | -12.577 | -0.6 | 0.0 | CPL centre/rotation; footprint package envelope including lead span where named; height assumption
R30 | B | 30.527 | 32.127 | -5.199000000000001 | -4.399 | -0.9 | 0.0 | CPL centre/rotation; footprint package envelope including lead span where named; height assumption
SW1 | B | 4.131 | 9.331 | -5.902 | -0.702 | -2.0 | 0.0 | 5.2 footprint/silkscreen envelope; 2.0 height inferred from exact BOM part name. Actuator shape simplified.
SW2 | B | 4.257999999999999 | 9.458 | -20.126 | -14.926 | -2.0 | 0.0 | 5.2 footprint/silkscreen envelope; 2.0 height inferred from exact BOM part name. Actuator shape simplified.
SW3 | T | 55.325 | 65.325 | -19.982 | -9.482 | 1.6 | 10.6 | XY from silkscreen x55.325..65.325 y-19.982..-9.472. 9.0 total height inferred from 10*10*9-6P WX part name. Base height, shaft diameter and movement are assumptions; no cap supplied.
SW4 | T | 46.899 | 51.399 | -18.125 | -13.625 | 1.6 | 5.4 | XY from GTO; 3.8 height inferred from LXW-TS-45X45X38-SMD identifier; actuator simplified.
U1 | B | 36.245999999999995 | 39.446 | -17.506 | -15.006 | -0.9 | 0.0 | CPL centre/rotation; footprint package envelope including lead span where named; height assumption
U2 | B | 36.967 | 43.967 | -11.407 | -4.406999999999999 | -1.0 | 0.0 | CPL centre/rotation; footprint package envelope including lead span where named; height assumption
U3 | B | 19.653000000000002 | 24.053000000000004 | -16.357 | -6.757 | -2.0 | 0.0 | C5373445 BOM; envelope from GBO x19.65297..24.05309 y-16.35699..-6.75693. Height 2.0 inferred from H2.0 part identifier; not drawing-verified.
U4 | T | 15.661000000000001 | 20.661 | -3.532 | -0.5319999999999997 | 1.6 | 2.8 | CPL centre/rotation; footprint package envelope including lead span where named; height assumption
U5 | T | 7.3629999999999995 | 10.163 | -14.149999999999999 | -11.249999999999998 | 1.6 | 2.8 | CPL centre/rotation; footprint package envelope including lead span where named; height assumption
TFT_PLACEHOLDER | T | 17.101459999999996 | 45.00146 | -18.49208 | -4.99208 | 2.1 | 4.6 | XY is exact silkscreen guide only. TFT is absent from BOM, CPL and rendered assembly. Model is a placeholder; active viewing area, glass, adhesive, FPC and height unverified.

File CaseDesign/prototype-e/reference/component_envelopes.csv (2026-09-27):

name | side | xmin | xmax | ymin | ymax | zmin | zmax
PCB | both | -0.12700010000002848 | 73.20800010000002 | -21.237000100000028 | 1.0000002847716647e-07 | -0.0004041618448597023 | 1.60040416184486
C1 | T | 24.006999899999997 | 24.507000100000006 | -4.183000100000004 | -3.1829998999999964 | 1.5999998999999965 | 2.2000001000000036
C2 | T | 4.960999899999998 | 5.961000100000002 | -14.601000100000002 | -14.1009999 | 1.599999899999998 | 2.2000001000000022
C3 | T | 9.824999899999996 | 10.625000100000003 | -16.867000100000006 | -15.266999899999997 | 1.5999998999999965 | 2.5000001000000034
C4 | T | 9.821999899999998 | 10.622000100000001 | -19.9150001 | -18.314999899999997 | 1.5999998999999996 | 2.5000001000000003
C5 | B | 38.650999899999995 | 39.15100010000001 | -3.128000100000007 | -2.127999899999993 | -0.600000100000007 | 1.000000071056442e-07
C6 | T | 7.373999899999997 | 8.374000100000002 | -8.632000100000003 | -8.131999899999997 | 1.5999998999999976 | 2.2000001000000027
C7 | B | 33.96599989999999 | 34.96600010000001 | -4.060000100000008 | -3.559999899999993 | -0.6000001000000071 | 1.000000071609385e-07
C8 | B | 46.27499989999999 | 47.27500010000001 | -7.323000100000008 | -6.822999899999993 | -0.600000100000007 | 1.0000000710548156e-07
C9 | B | 33.8479999 | 34.8480001 | -7.577000100000001 | -7.076999899999999 | -0.6000001000000008 | 1.0000000088991144e-07
C10 | B | 43.437999899999994 | 43.93800010000001 | -14.421000100000006 | -13.420999899999993 | -0.600000100000007 | 1.000000071056442e-07
C11 | B | 31.9029999 | 33.5030001 | -18.1890001 | -17.3889999 | -0.9000001000000001 | 1.000000001110223e-07
C12 | B | 40.7939999 | 42.3940001 | -16.210000100000002 | -15.409999899999999 | -0.9000001000000019 | 1.000000017798229e-07
C13 | B | 25.911999899999994 | 26.412000100000004 | -11.930000100000003 | -10.929999899999997 | -0.6000001000000035 | 1.0000000355314733e-07
C14 | B | 44.95999989999999 | 45.96000010000001 | -17.25700010000001 | -16.756999899999993 | -0.6000001000000079 | 1.0000000794410928e-07
C15 | B | 44.92099989999999 | 45.92100010000001 | -15.868000100000007 | -15.367999899999994 | -0.6000001000000073 | 1.0000000732410687e-07
C16 | B | 44.747999899999996 | 46.34800010000001 | -19.098000100000007 | -18.297999899999994 | -0.9000001000000071 | 1.0000000710629466e-07
C17 | B | 31.210999899999997 | 32.2110001 | -6.385000100000001 | -5.884999899999999 | -0.6000001000000008 | 1.0000000088991144e-07
C18 | B | 46.31399989999999 | 47.31400010000001 | -9.267000100000006 | -8.766999899999993 | -0.600000100000007 | 1.000000071056442e-07
C19 | B | 40.516999899999995 | 41.01700010000001 | -1.7700001000000072 | -0.7699998999999929 | -0.6000001000000071 | 1.0000000710895014e-07
C20 | B | 33.8779999 | 34.8780001 | -5.1640001 | -4.663999899999999 | -0.6000001 | 1.0000000005551115e-07
C21 | B | 46.23599989999999 | 47.236000100000005 | -5.3300001000000075 | -4.829999899999993 | -0.600000100000007 | 1.000000071056442e-07
C22 | B | 33.4579999 | 34.4580001 | -11.602000100000001 | -11.1019999 | -0.6000001000000017 | 1.0000000177722398e-07
C23 | B | 41.659999899999995 | 42.1600001 | -1.7700001000000003 | -0.7699998999999997 | -0.6000001000000003 | 1.0000000022887833e-07
C24 | B | 33.78999989999999 | 34.79000010000001 | -8.886000100000006 | -8.385999899999993 | -0.600000100000007 | 1.000000071056442e-07
C30 | T | 7.073999899999999 | 8.6740001 | -7.124000100000002 | -6.323999899999999 | 1.5999998999999987 | 2.500000100000001
CARD1 | B | 50.0039999 | 64.8040001 | -14.800000100000005 | -0.09999989999999248 | -2.000000100000007 | 1.0000000716158396e-07
D1 | T | 3.7299998999999984 | 6.430000100000002 | -4.5170001000000015 | -0.8169998999999986 | 1.599999899999999 | 2.800000100000001
D2 | T | 59.99099989999999 | 62.69100010000001 | -3.628000100000007 | 0.07200010000000719 | 1.599999899999993 | 2.8000001000000068
D3 | T | 64.8939999 | 67.6940001 | -6.7840001 | -3.8839998999999987 | 1.5999998999999991 | 2.8000001000000005
D4 | T | 3.1719998999999977 | 5.9720001000000025 | -10.8480001 | -7.9479998999999975 | 1.599999899999998 | 2.800000100000002
J1 | T | 69.94999989999998 | 88.75000010000001 | -17.384000100000016 | -4.713999899999985 | 1.5999998999999858 | 6.100000100000014
J2 | T | -11.757373081599022 | 1.8530001000000016 | -15.0430001 | -6.292999899999997 | 0.6496269184009783 | 3.0503730815990218
L1 | T | 3.3419998999999985 | 8.3420001 | -20.280000100000002 | -15.2799999 | 1.5999998999999991 | 5.600000100000001
L2 | B | 23.614999899999994 | 28.615000100000003 | -5.501000100000003 | -0.5009998999999963 | -2.000000100000004 | 1.0000000366877897e-07
Q1 | B | 28.140999899999997 | 31.041000100000005 | -13.011000100000004 | -10.610999899999996 | -1.200000100000004 | 1.0000000397360592e-07
R1 | B | 33.6169999 | 35.2170001 | -1.4160001000000002 | -0.6159998999999998 | -0.9000001000000003 | 1.0000000024825341e-07
R2 | B | 52.58199989999999 | 53.08200010000001 | -19.04200010000001 | -18.041999899999993 | -0.600000100000007 | 1.000000071056442e-07
R3 | B | 37.6229999 | 39.2230001 | -14.050000100000002 | -13.249999899999999 | -0.9000001000000019 | 1.000000017798229e-07
R4 | T | 67.44099990000001 | 67.9410001 | -2.7860001000000003 | -1.7859998999999995 | 1.5999998999999996 | 2.2000001000000005
R5 | T | 3.488999899999998 | 4.489000100000002 | -12.1360001 | -11.635999899999998 | 1.599999899999998 | 2.2000001000000022
R6 | T | 5.464999899999998 | 5.965000100000002 | -12.946000100000001 | -11.945999899999999 | 1.5999998999999983 | 2.200000100000002
R7 | T | 65.7899999 | 66.29000010000001 | -2.786000100000014 | -1.7859998999999858 | 1.5999998999999858 | 2.2000001000000142
R8 | T | 22.185999899999995 | 23.186000100000005 | -3.425000100000003 | -2.9249998999999964 | 1.5999998999999965 | 2.2000001000000036
R9 | T | 13.342999899999999 | 14.343000100000001 | -3.171000100000002 | -2.6709998999999978 | 1.5999998999999983 | 2.200000100000002
R10 | B | 33.6169999 | 35.2170001 | -2.8130001 | -2.0129998999999996 | -0.9000001000000005 | 1.0000000045775668e-07
R11 | T | 3.627999899999999 | 5.228000100000001 | -7.131000100000001 | -6.330999899999998 | 1.5999998999999991 | 2.500000100000001
R12 | B | 60.784999899999995 | 61.2850001 | -19.094000100000002 | -18.0939999 | -0.6000001 | 1.0000000005551115e-07
R13 | B | 59.56699989999999 | 60.06700010000001 | -19.14600010000001 | -18.145999899999993 | -0.600000100000007 | 1.000000071056442e-07
R14 | B | 58.42399989999999 | 58.92400010000001 | -19.16900010000001 | -18.168999899999992 | -0.6000001000000079 | 1.0000000794410928e-07
R15 | B | 56.97499989999999 | 57.47500010000001 | -19.22100010000001 | -18.220999899999992 | -0.6000001000000079 | 1.0000000794410928e-07
R16 | B | 53.85199989999999 | 54.352000100000005 | -19.019000100000007 | -18.01899989999999 | -0.600000100000007 | 1.000000071056442e-07
R17 | B | 48.78399989999999 | 50.78400010000001 | -19.16700010000001 | -17.916999899999993 | -1.0000001000000072 | 1.000000071056442e-07
R18 | B | 47.323999900000004 | 48.9240001 | -11.8210001 | -11.0209999 | -0.9000001000000001 | 1.000000001110223e-07
R19 | T | 59.49199989999999 | 59.992000100000006 | -7.941000100000007 | -6.9409998999999925 | 1.599999899999993 | 2.200000100000007
R20 | T | 58.0949999 | 58.5950001 | -7.941000100000001 | -6.940999899999999 | 1.5999998999999991 | 2.200000100000001
R21 | T | 56.69799989999999 | 57.19800010000001 | -7.941000100000007 | -6.9409998999999925 | 1.599999899999993 | 2.200000100000007
R22 | T | 62.36099989999999 | 62.861000100000005 | -7.993000100000008 | -6.992999899999993 | 1.599999899999993 | 2.200000100000007
R23 | T | 60.9639999 | 61.4640001 | -7.9930001000000015 | -6.992999899999999 | 1.5999998999999991 | 2.200000100000001
R24 | T | 47.57299989999999 | 48.07300010000001 | -10.831000100000006 | -9.830999899999993 | 1.5999998999999927 | 2.2000001000000076
R25 | B | 26.3779999 | 27.978000100000006 | -8.655000100000004 | -7.854999899999997 | -0.9000001000000035 | 1.0000000355444797e-07
R27 | B | 33.40899989999999 | 34.40900010000001 | -13.077000100000006 | -12.576999899999993 | -0.600000100000007 | 1.000000071056442e-07
R30 | B | 30.5269999 | 32.127000100000004 | -5.199000100000002 | -4.398999899999999 | -0.900000100000001 | 1.0000000089509042e-07
SW1 | B | 4.130999899999998 | 9.3310001 | -5.902000100000002 | -0.701999899999998 | -2.000357540699062 | 1.0000000089509042e-07
SW2 | B | 4.257999899999995 | 9.458000100000005 | -20.126000100000006 | -14.925999899999995 | -2.0003575406990657 | 1.0000000089509042e-07
SW3 | T | 55.32499989999999 | 65.32500010000001 | -19.982000100000015 | -9.481999899999986 | 1.599999899999993 | 10.600000100000006
SW4 | T | 46.89899989999999 | 51.39900010000001 | -18.12500010000001 | -13.624999899999992 | 1.5999998999999996 | 5.400357540699068
U1 | B | 36.245999899999994 | 39.4460001 | -17.5060001 | -15.0059999 | -0.9000001000000001 | 1.000000001110223e-07
U2 | B | 36.9669999 | 43.96700010000001 | -11.407000100000007 | -4.406999899999993 | -1.0000001000000074 | 1.0000000732431724e-07
U3 | B | 19.652999899999998 | 24.053000100000006 | -16.357000100000004 | -6.756999899999997 | -2.000000100000004 | 1.0000000397205465e-07
U4 | T | 15.6609999 | 20.661000100000003 | -3.5320001000000003 | -0.5319998999999994 | 1.5999998999999996 | 2.8000001
U5 | T | 7.3629998999999975 | 10.163000100000001 | -14.1500001 | -11.249999899999999 | 1.5999998999999983 | 2.8000001000000014
TFT_PLACEHOLDER | T | 17.10145989999999 | 45.0014601 | -18.492080100000006 | -4.992079899999997 | 2.0999998999999967 | 3.7000001000000036
SD_CARD_ASSUMED | B | 51.903999899999995 | 62.90400010000001 | -13.800000100000007 | 1.2000001000000065 | -1.6500001000000073 | -0.6499998999999927

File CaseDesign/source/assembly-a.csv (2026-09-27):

No. | Quantity | Comment | Designator | Footprint | Value | Manufacturer Part | Manufacturer | Supplier Part | Supplier
1 | 6 | Test-Point | 3V3,BOOTSEL,GND,RUN,SWCLK,SWDIO | Test-Point-0.5mm
2 | 15 | 100nF | C1,C5,C6,C7,C9,C10,C13,C14,C18,C19,C20,C21,C22,C23,C24 | C0402 | 100nF | CL05B104KO5NNNC | SAMSUNG(三星) | C1525 | LCSC
3 | 1 | 100nF | C2 | C0402 | 100nF | MG15B104K160CT | Walsin(华新科) | C327781 | LCSC
4 | 2 | 22uF | C3,C4 | C0603 | 22uF | TCC0603X5R226K6R3CT | CCTC(三环) | C49275042 | LCSC
5 | 2 | 4.7uF | C8,C17 | C0402 | 4.7uF | GRM155D71A475ME15D | muRata(村田) | C20044522 | LCSC
6 | 2 | 15pF | C11,C12 | C0603 | 15pF | FCC0603N150J500CT | FOJAN(富捷) | C5137617 | LCSC
7 | 1 | 1uF | C15 | C0402 | 1uF | TCC0402X5R105K250AT | CCTC(三环) | C5359886 | LCSC
8 | 2 | 10uF | C16,C30 | C0603 | 10uF | MH0603A106M100N8RN | Sunway(信维通信) | C54349904 | LCSC
9 | 1 | TF PUSH | CARD1 | TF-SMD_TF-PUSH |  | TF PUSH | SHOU HAN(首韩) | C393941 | LCSC
10 | 2 | B5819W SL | D1,D2 | SOD-123_L2.7-W1.6-LS3.7-RD-1 |  | B5819W SL | CJ(江苏长电/长晶) | C8598 | LCSC
11 | 2 | USBLC6-2SC6 | D3,D4 | SOT-23-6_L2.9-W1.6-P0.95-LS2.8-BL |  | USBLC6-2SC6 | UMW(友台半导体) | C2687116 | LCSC
12 | 1 | AM90 | J1 | USB-AM-TH_AM90 |  | AM90 | SHOU HAN(首韩) | C404965 | LCSC
13 | 1 | U261-121N-4BS2S | J2 | USB-C-SMD_U261-121N-4BS2S |  | U261-121N-4BS2S | XKB Connection(中国星坤) | C2879827 | LCSC
14 | 1 | 3.9uH | L1 | IND-SMD_L5.0-W5.0 | 3.9uH | ZENR5040T3R9N-3.9uH | ZE(增益) | C42428060 | LCSC
15 | 1 | 3.3uH | L2 | IND-SMD_L5.0-W5.0_NR5020M150AS | 3.3uH | NR5020M3R3A | Coilank(驰兴电感) | C47327049 | LCSC
16 | 1 | AO3401A | Q1 | SOT-23_L2.9-W1.3-P1.90-LS2.4-BR |  | AO3401A | UMW(友台半导体) | C347476 | LCSC
17 | 3 | 27Ω | R1,R10,R25 | R0603 | 27Ω | FRQ0603F27R0TS | FOJAN(富捷) | C7468521 | LCSC
18 | 15 | 10kΩ | R2,R8,R9,R12,R13,R14,R15,R16,R19,R20,R21,R22,R23,R24,R27 | R0402 | 10kΩ | RC0402FR-0710KL | YAGEO(国巨) | C60490 | LCSC
19 | 1 | 1kΩ | R3 | R0603 | 1kΩ | FRC0603F1001TS | FOJAN(富捷) | C2907002 | LCSC
20 | 2 | 100kΩ | R4,R5 | R0402 | 100kΩ | RC0402FR-07100KL | YAGEO(国巨) | C60491 | LCSC
21 | 2 | 120kΩ | R6,R7 | R0402 | 120kΩ | FRC0402F1203TS | FOJAN(富捷) | C2909314 | LCSC
22 | 1 | 5.1kΩ | R11 | R0603 | 5.1kΩ | CRF0603Q512FN | SIE(永星科技) | C54973944 | LCSC
23 | 1 | 0Ω | R17 | R0805 | 0Ω | HRC0805F0000FNTN | HC(华橙熊猫) | C54921091 | LCSC
24 | 1 | 22Ω | R18 | R0603 | 22Ω | 1RC0603J0220 | SAE(世盟/世爱) | C54531690 | LCSC
25 | 1 | 33Ω | R30 | R0603 | 33Ω | FRC0603F33R0TS | FOJAN(富捷) | C2909394 | LCSC
26 | 2 | TS-1140SP-4x4x2.0H-260 | SW1,SW2 | SW-SMD_4P-L5.2-W5.2-P3.70-LS6.4 |  | TS-1140SP-4x4x2.0H-260 | CAX(创都) | C51927161 | LCSC
27 | 1 | 10*10*9-6P WX | SW3 | SW-SMD-6P-L10.5-W10.0_C2858290 |  | 10*10*9-6P WX | SHOU HAN(首韩) | C2858290 | LCSC
28 | 1 | LXW-TS-45X45X38-SMD | SW4 | SW-SMD_4P-L4.5-W4.5-P3.00-LS6.8 |  | LXW-TS-45X45X38-SMD | LXWCONN(连兴旺电子) | C53447035 | LCSC
29 | 1 | 12MHz | U1 | CRYSTAL-SMD_4P-L3.2-W2.5-BL | 12MHz | ABM8-272-T3 | ABRACON | C20625731 | LCSC
30 | 1 | RP2354A | U2 | QFN-60_L7.0-W7.0-P0.40-TL-EP3.4 |  | RP2354A | Raspberry Pi(树莓派) | C41378174 | LCSC
31 | 1 | 0.5-8P CTSJ-H2.0 119 | U3 | FPC-SMD_8P-P0.50_SHOUHAN_CTSJ-H2.0 |  | 0.5-8P CTSJ-H2.0 119 | SHOU HAN(首韩) | C5373445 | LCSC
32 | 1 | FSUSB42MUX | U4 | MSOP-10_L3.0-W3.0-P0.50-LS5.0-BL |  | FSUSB42MUX | onsemi(安森美) | C11355 | LCSC
33 | 1 | AP63203WU-7 | U5 | TSOT-26_L2.9-W1.6-P0.95-LS2.8-BL |  | AP63203WU-7 | DIODES(美台) | C780769 | LCSC

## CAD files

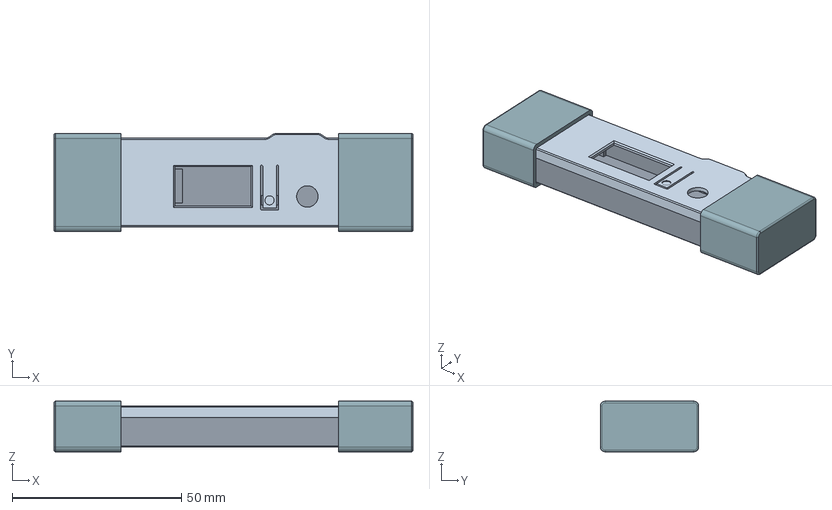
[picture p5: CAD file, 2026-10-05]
CaseDesign/prototype-e/case_assembly.step
106.1 x 29.1 x 15.0 mm
base
lid
usb_c_collar
usb_c_end_cap
usb_a_end_cap

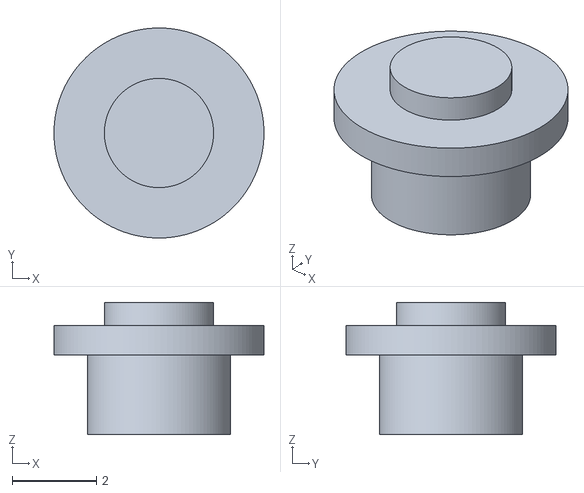
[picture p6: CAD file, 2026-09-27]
CaseDesign/files/back_plunger.stl
5.00 x 5.00 x 3.15

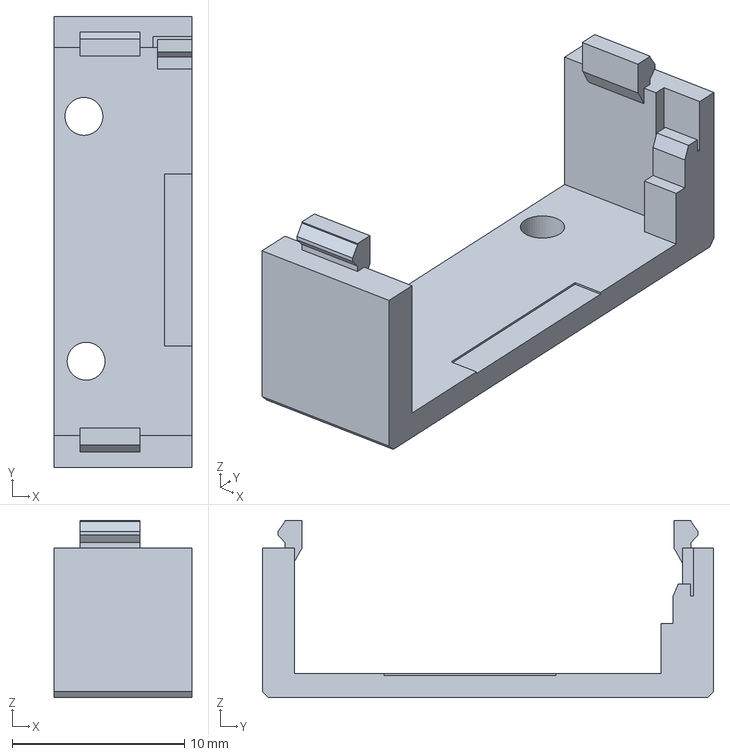
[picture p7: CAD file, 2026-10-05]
CaseDesign/prototype-e/base_snap_standard.step
8.00 x 26.2 x 10.3 mm

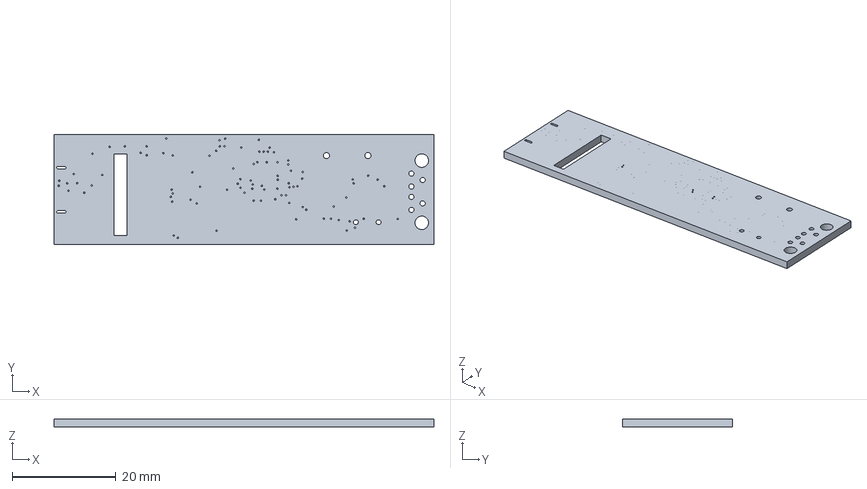
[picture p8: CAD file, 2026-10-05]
CaseDesign/prototype-e/reference/pcb.step
73.3 x 21.2 x 1.60 mm

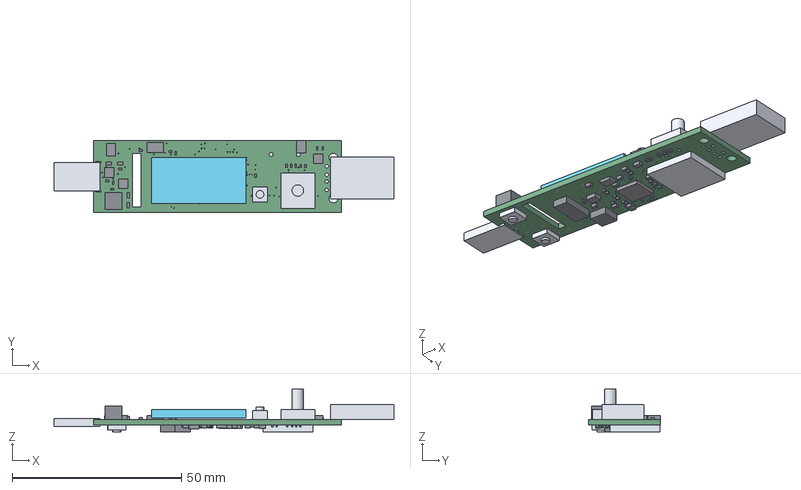
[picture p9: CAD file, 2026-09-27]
CaseDesign/reference.step
100.5 x 21.3 x 12.6 mm
PCB
C1
C2
C3
C4
C5
C6
C7
C8
C9
C10
C11
C12
C13
C14
C15
C16
C17
C18
C19
C20
C21
C22
C23
C24
C30
CARD1
D1
D2
D3
D4
J1
J2
L1
L2
Q1
R1
R2
R3
R4
R5
R6
R7
R8
R9
R10
R11
R12
R13
R14
R15
R16
R17
R18
R19
R20
R21
R22
R23
R24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

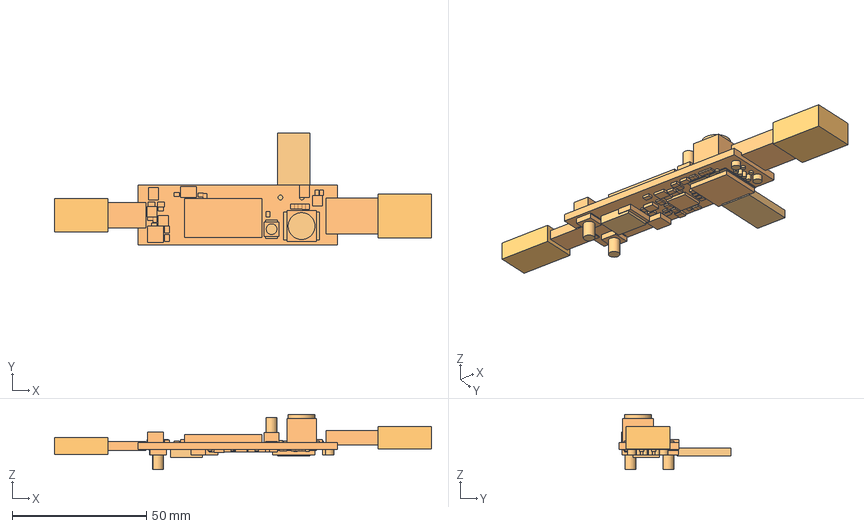
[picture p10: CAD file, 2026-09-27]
CaseDesign/keepouts.step
140.5 x 41.6 x 20.6 mm
PCB_clearance
C1_clearance
C2_clearance
C3_clearance
C4_clearance
C5_clearance
C6_clearance
C7_clearance
C8_clearance
C9_clearance
C10_clearance
C11_clearance
C12_clearance
C13_clearance
C14_clearance
C15_clearance
C16_clearance
C17_clearance
C18_clearance
C19_clearance
C20_clearance
C21_clearance
C22_clearance
C23_clearance
C24_clearance
C30_clearance
CARD1_clearance
D1_clearance
D2_clearance
D3_clearance
D4_clearance
J1_clearance
J2_clearance
L1_clearance
L2_clearance
Q1_clearance
R1_clearance
R2_clearance
R3_clearance
R4_clearance
R5_clearance
R6_clearance
R7_clearance
R8_clearance
R9_clearance
R10_clearance
R11_clearance
R12_clearance
R13_clearance
R14_clearance
R15_clearance
R16_clearance
R17_clearance
R18_clearance
R19_clearance
R20_clearance
R21_clearance
R22_clearance
R23_clearance
R24_clearance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

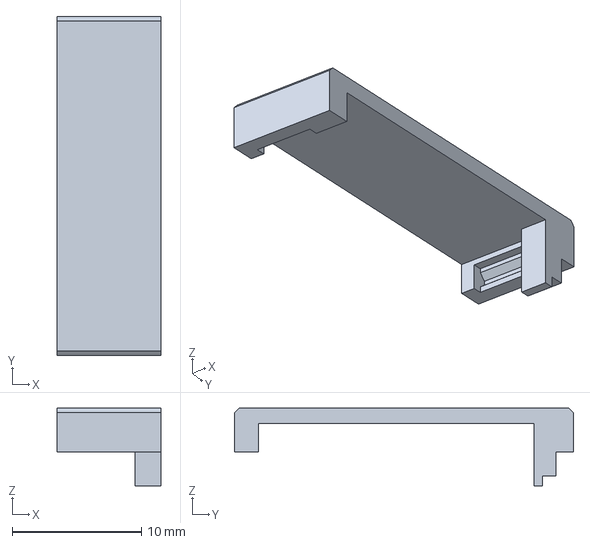
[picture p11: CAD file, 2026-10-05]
CaseDesign/prototype-e/lid_snap_firm.step
8.00 x 26.2 x 6.00 mm

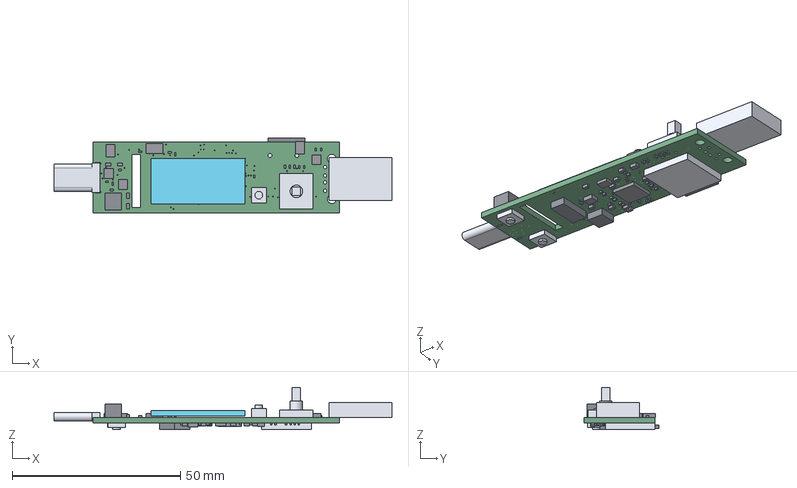
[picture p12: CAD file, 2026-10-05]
CaseDesign/prototype-e/reference/reference.step
100.5 x 22.4 x 12.6 mm
PCB
C1
C2
C3
C4
C5
C6
C7
C8
C9
C10
C11
C12
C13
C14
C15
C16
C17
C18
C19
C20
C21
C22
C23
C24
C30
CARD1
D1
D2
D3
D4
J1
J2
L1
L2
Q1
R1
R2
R3
R4
R5
R6
R7
R8
R9
R10
R11
R12
R13
R14
R15
R16
R17
R18
R19
R20
R21
R22
R23
R24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

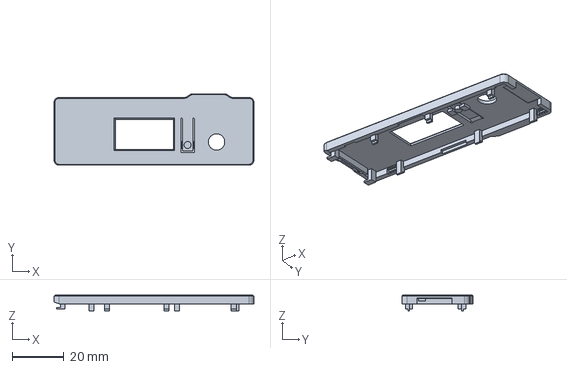
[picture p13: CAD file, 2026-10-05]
CaseDesign/prototype-e/lid.step
77.3 x 27.6 x 6.00 mm

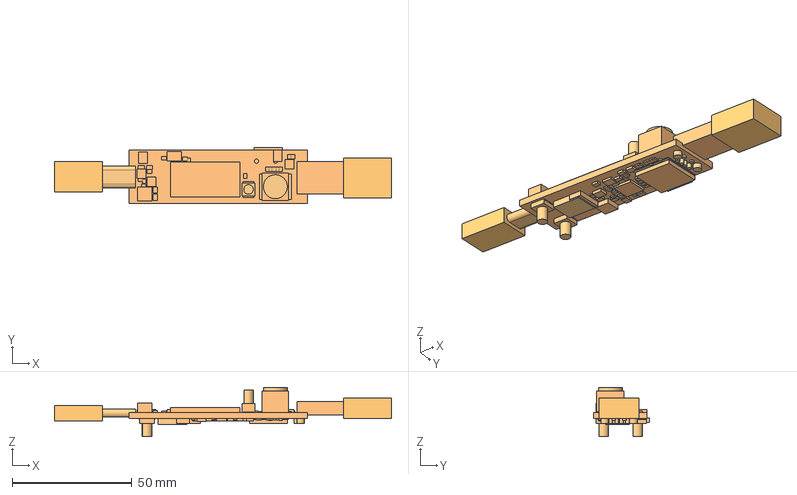
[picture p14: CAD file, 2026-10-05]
CaseDesign/prototype-e/reference/keepouts.step
140.5 x 23.3 x 20.6 mm
PCB_clearance
C1_clearance
C2_clearance
C3_clearance
C4_clearance
C5_clearance
C6_clearance
C7_clearance
C8_clearance
C9_clearance
C10_clearance
C11_clearance
C12_clearance
C13_clearance
C14_clearance
C15_clearance
C16_clearance
C17_clearance
C18_clearance
C19_clearance
C20_clearance
C21_clearance
C22_clearance
C23_clearance
C24_clearance
C30_clearance
CARD1_clearance
D1_clearance
D2_clearance
D3_clearance
D4_clearance
J1_clearance
L1_clearance
L2_clearance
Q1_clearance
R1_clearance
R2_clearance
R3_clearance
R4_clearance
R5_clearance
R6_clearance
R7_clearance
R8_clearance
R9_clearance
R10_clearance
R11_clearance
R12_clearance
R13_clearance
R14_clearance
R15_clearance
R16_clearance
R17_clearance
R18_clearance
R19_clearance
R20_clearance
R21_clearance
R22_clearance
R23_clearance
R24_clearance
R25_clearance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

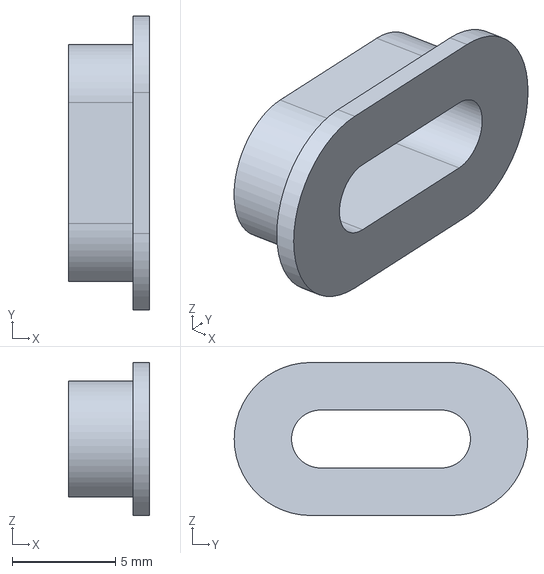
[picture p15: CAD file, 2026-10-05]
CaseDesign/prototype-e/usb_c_collar.step
3.90 x 14.2 x 7.40 mm

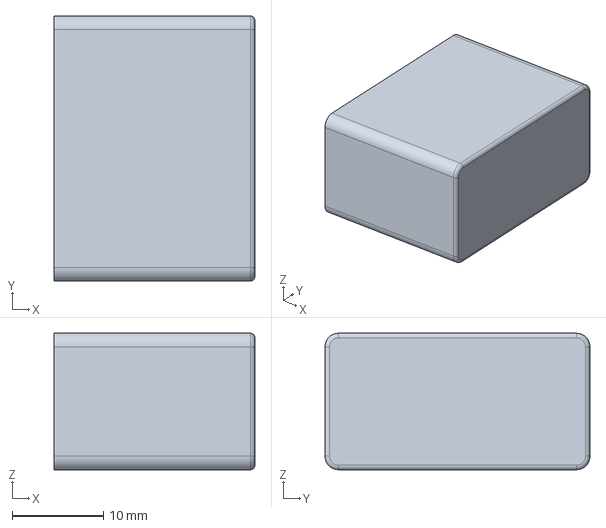
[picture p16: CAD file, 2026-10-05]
CaseDesign/prototype-e/usb_a_end_cap.step
22.0 x 29.1 x 15.0 mm

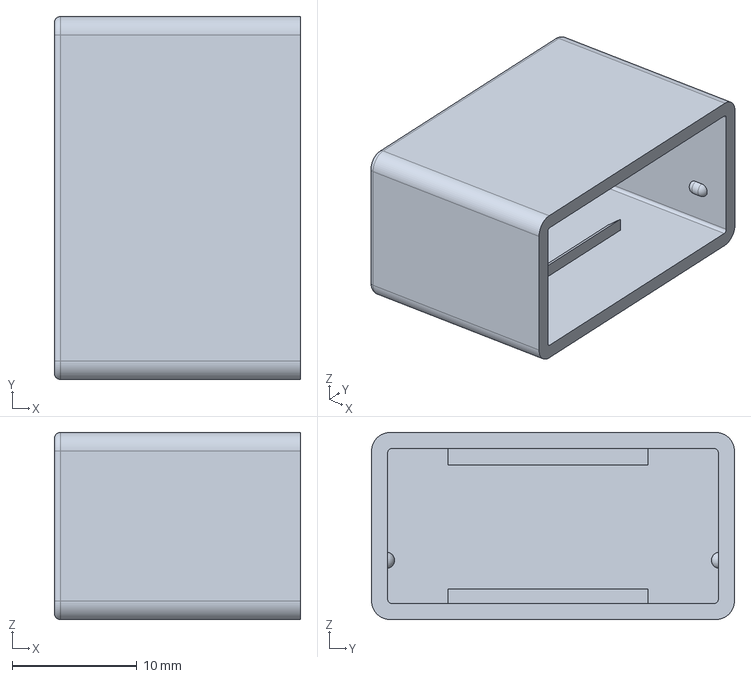
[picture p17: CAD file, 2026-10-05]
CaseDesign/prototype-e/usb_c_end_cap.step
19.8 x 29.1 x 15.0 mm

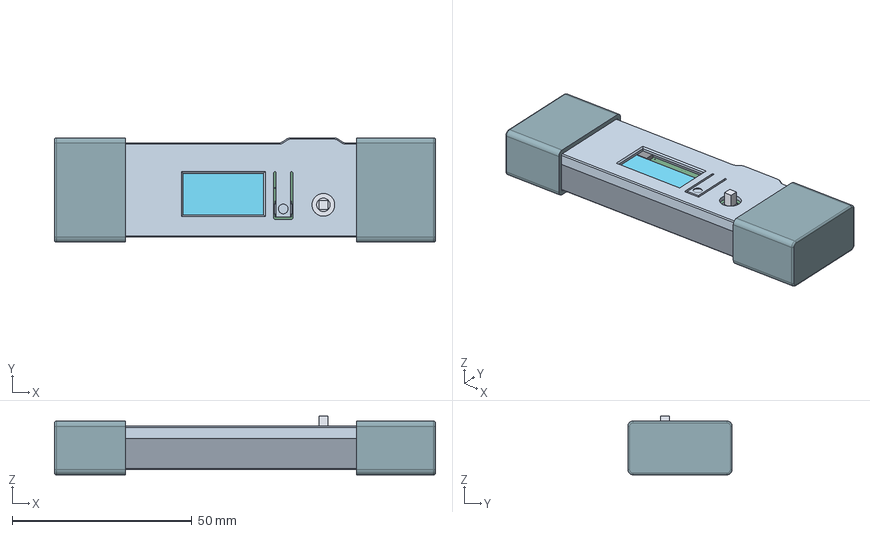
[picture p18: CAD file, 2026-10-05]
CaseDesign/prototype-e/case_with_board.step
106.1 x 29.1 x 16.4 mm
base
lid
usb_c_collar
usb_c_end_cap
usb_a_end_cap
REF_PCB
REF_C1
REF_C2
REF_C3
REF_C4
REF_C5
REF_C6
REF_C7
REF_C8
REF_C9
REF_C10
REF_C11
REF_C12
REF_C13
REF_C14
REF_C15
REF_C16
REF_C17
REF_C18
REF_C19
REF_C20
REF_C21
REF_C22
REF_C23
REF_C24
REF_C30
REF_CARD1
REF_D1
REF_D2
REF_D3
REF_D4
REF_J1
REF_J2
REF_L1
REF_L2
REF_Q1
REF_R1
REF_R2
REF_R3
REF_R4
REF_R5
REF_R6
REF_R7
REF_R8
REF_R9
REF_R10
REF_R11
REF_R12
REF_R13
REF_R14
REF_R15
REF_R16
REF_R17
REF_R18
REF_R19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

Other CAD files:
CaseDesign/pcb.step
CaseDesign/prototype-e/lid_snap_standard.step
CaseDesign/prototype-e/base_snap_light.step
CaseDesign/prototype-e/base.step
CaseDesign/files/base.stl
CaseDesign/files/joystick_cap.stl
CaseDesign/files/lid.stl
CaseDesign/pcb.stl
CaseDesign/prototype-a/back_plunger.step
CaseDesign/prototype-a/base.step
CaseDesign/prototype-a/base.stl
CaseDesign/prototype-a/case_assembly.step
CaseDesign/prototype-a/case_with_board.step
CaseDesign/prototype-a/joystick_cap.step
CaseDesign/prototype-a/joystick_cap.stl
CaseDesign/prototype-a/lid.step
CaseDesign/prototype-a/lid.stl
CaseDesign/prototype-a/usb_c_collar.step
CaseDesign/prototype-b (1)/prototype-b/back_button_coupon.step
CaseDesign/prototype-b (1)/prototype-b/back_button_coupon.stl
CaseDesign/prototype-b (1)/prototype-b/base.step
CaseDesign/prototype-b (1)/prototype-b/base.stl
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

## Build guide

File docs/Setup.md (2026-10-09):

# Setup unlock and enrollment

During initial setup the user selects how they want to enter their credential. Currently we support three methods: a direction pattern, four number wheels, and four word selectors. Each has a tradeoff between the number of possible values, remembering the credential and entering it on the device.

The number of possible values depends on the method and, for direction patterns, the length:

| Method | Choices | Possible values if chosen uniformly at random |
| --- | --- | --- |
| Direction pattern | 8–64 entries, each one of four directions | 4 to the power of the length; 2 bits per direction |
| Four number wheels | Each wheel selects 00–99 | 100 million combinations, about 26.6 bits |
| Four words | Each position selects from 64 words | About 16.8 million combinations, 24 bits |

The wheels have more possible values than the four-word method, but a direction pattern of 14 entries already has more possible values than the wheels. These figures describe random choices. Familiar sequences, dates or predictable word combinations can be much easier to guess.

## Creating the vault

The user first enters and confirms their credential, then selects the encryption stack. They can select one to four layers from AES-256, Camellia-256 and SM4-128. These layers build the pipeline through which content is encrypted and decrypted. Additional layers can reduce transfer speeds. Changing the stack currently requires creating a fresh vault. Credential changes preserve the existing vault.

The user also selects the failure policy before confirming creation. The current UI allows 1–100 attempts and offers either key destruction or permanent lockout. The default is ten attempts followed by key destruction. Removing the lockout option is an intended change described below.

The current setup order is:

1. Choose the credential entry method.
2. Enter and confirm the credential.
3. Select the encryption stack.
4. Select the attempt limit and failure action.
5. Review the choices and explicitly confirm creation, which replaces the existing SD layout.
6. Provision OTP enrollment material if needed. On a new device this includes both a permanent device root and an enrollment token; after destruction, the existing root is retained and a fresh token is provisioned.
7. Generate a random VMK and protect it using the credential and device-held secrets, with the selected cipher families.
8. Initialize storage metadata and create the partition table and FAT32 filesystem through the encrypted storage path. Prepare the FIDO store when FIDO is enabled.
9. Write and verify the vault headers, then commit the active-vault state in the internal journal.

The VMK is generated independently at random. The user credential and OTP secrets derive the keys used to protect it. The details are in [Key handling](KeyHandling.md).

The vault becomes active after storage initialization and header writes succeed. On successful completion, the temporary unlocked session is cleared and the user returns to the locked home screen. They must unlock the new vault before using it.

Formatting initializes the encrypted filesystem and the metadata needed to treat unwritten content as zeros, as described in [File storage](FileStorage.md).

## Unlock

While locked, the VMK is stored encrypted in the SD card's vault headers. Internal flash holds the security-state journal. The user credential and OTP secrets are needed to recover the VMK into RAM and construct the unlocked session.

From the locked home screen, pressing Select opens the entry method chosen at setup. That choice is recorded in the unencrypted SD header. The firmware checks the header against the authoritative hash held in the internal journal before trusting it.

Before evaluating a submitted credential, the device durably increments the attempt counter and records that an attempt is pending. HMAC authenticates the journal records, protecting the saved attempt count and other security state against unauthorized modification. Its authentication key is currently derived from the permanent device root. An interrupted attempt remains charged across power cycles.

If the credential is correct, the firmware recovers the VMK, resets the attempt count to zero and builds the working encryption pipeline. If it is incorrect, the user can try again while attempts remain. The final allowed attempt can still succeed. An interruption on the final charged attempt is handled conservatively by applying the limit policy during recovery.

## Reaching the attempt limit

With the default destruction policy, the device records destruction intent, marks the current enrollment token revoked, and programs its secret rows to all ones. Interrupted destruction is resumed during recovery before allowing further authentication. The permanent root is retained in the current implementation.

The enrollment token is a required input to deriving the VMK's wrapping keys. Destroying it removes that input, preventing the device from recovering the VMK even with the correct user credential. The encrypted VMK and encrypted files and passkeys remain on the SD card, with access lost through destruction of the token.

After destruction completes, the user can set up a fresh vault using the next available token slot. The current implementation has eight slots, including the initial enrollment, and partially programmed slots can also be consumed. The fresh enrollment creates a new, empty vault.

The alternative currently offered is permanent lockout. This refuses further authentication, including the correct credential, but retains the token. This is a terminal state with no supported recovery or fresh-setup route.

## Improvements not yet implemented

### Remove permanent lockout

Remove permanent lockout as a selectable failure action until we have designed an alternative with a clear purpose and a secure recovery path. Keep the configurable attempt limit, with destruction as the supported action when the limit is exhausted.

The new UI should make the consequence explicit: exhausting attempts destroys access to the current vault, and setting up again creates an empty vault. Existing lockout-policy records need an explicit compatibility decision that preserves enforcement of their stored state and policy.

### Simplify enrollment secrets and expand capacity

Remove the permanent device root. Use one independently random enrollment token to derive separate keys for vault protection and journal authentication. A new enrollment starts with a fresh journal, policy and zero attempts.

Use a single raw OTP status mask on page 3 and pack four token secrets per page across pages 4–60. This provides 228 slots on a fresh token area. The mask identifies unused, started, completed and revoked tokens. The allocation and derivation proposal is described in [Key handling](KeyHandling.md#proposed-improvements-not-implemented).

A token left in the started state after interruption is abandoned and destroyed before advancing. A completed token must be verified before being used to create a vault. A revoked token is never selected again, and any unfinished burning of its secret rows must be completed.

### Define interrupted setup and fresh journal creation

Specify and test the ordering between token completion, journal initialization, filesystem/FIDO initialization and the final active-vault commit. Track token completion and vault activation as separate stages.

Only explicit new-enrollment setup may initialize a fresh journal. A missing or corrupt journal for an existing active vault must deny access. Recovery after interruption between token completion and journal initialization remains a design detail to resolve.

Accept an incompatible format change for the two development units. Previously programmed OTP rows must be identified and excluded from fresh slot allocation.

Implementation of these improvements is pending. Attempt accounting must remain effective across normal resets and SD replacement or rollback. Restoring an older image of internal flash remains outside the agreed protection scope.

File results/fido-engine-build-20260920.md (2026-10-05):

# V2 portable FIDO engine validation — 2026-09-20

F1 portable baseline passed. This does not enable FIDO on the board. The formal
remaining stages and constraints are in [the ledger](../docs/AI/v2-fido-progress.md).

## Delivered

- V2-owned pico-fido/Pico Keys/TinyCBOR sources with pinned provenance and licenses.
- Opt-in `FV_ENABLE_FIDO_ENGINE` target, sharing V2's Mbed TLS 3.6 build/ABI.
- Required built-in UV callbacks, no external PIN setup; direct UV and scoped
  protocol 1/2 UV-token dispatch; ES256 and credential self-attestation.
- Zero counters and no counter-only assertion writes, matching accepted replay risk.
- Documented input/output bounds, serialized ownership and close-time wiping.
  Pre-cancelled commands and short response buffers fail before mutation.
- Independent python-fido2 client against the actual C engine and test-only RAM
  snapshot/UV/presence callbacks. No upstream USB/OTP/physical flash code linked.

## Host commands and results

```sh
cmake -S . -B build-fido -DFV_MBEDTLS_DIR=/home/adam/pico-sdk/lib/mbedtls \
  -DFV_ENABLE_FIDO_ENGINE=ON -DCMAKE_BUILD_TYPE=Debug
cmake --build build-fido -j4
ctest --test-dir build-fido --output-on-failure

cmake -S . -B build-fido-sanitize -DFV_MBEDTLS_DIR=/home/adam/pico-sdk/lib/mbedtls \
  -DFV_ENABLE_FIDO_ENGINE=ON -DFV_SANITIZERS=ON -DCMAKE_BUILD_TYPE=Debug
cmake --build build-fido-sanitize -j4
ASAN_OPTIONS=detect_leaks=0 ctest --test-dir build-fido-sanitize --output-on-failure

cmake -S . -B build-fido-disabled -DFV_MBEDTLS_DIR=/home/adam/pico-sdk/lib/mbedtls \
  -DFV_ENABLE_FIDO_ENGINE=OFF -DCMAKE_BUILD_TYPE=Debug
cmake --build build-fido-disabled -j4
ctest --test-dir build-fido-disabled --output-on-failure
```

Results: 27/27 enabled; 27/27 ASan/UBSan; 25/25 disabled. LeakSanitizer was disabled
for this traced environment; no leak validation is claimed. Python dependencies
are required at configuration rather than silently skipping the independent test.

The reference test verifies public-key signatures on self-attestation and login,
resident and nonresident keys, UV/UP flags, exclusion/wrong-RP denial, both scoped
token protocols, wrong permissions/RP, token timeout/reopen invalidation, host
PIN rejection, presence and UV denial, durable callback failure, RNG failure,
session faulting, deletion/reset across reopen, reset timeout, pre-cancellation,
malformed CBOR and oversized requests. A 64 KiB store filled after 44 records with
the fixture's 100-character names; it returned KEY_STORE_FULL and the earliest
credential still signed correctly after reopen. This is not a universal passkey
capacity promise: record sizes vary. Each protocol exercises 1,000 seeded malformed
messages; that is a regression smoke test, not exhaustive fuzzing or conformance.

## ARM evidence

```sh
cmake -S . -B build-fido-arm -DFV_MBEDTLS_DIR=/home/adam/pico-sdk/lib/mbedtls \
  -DFV_ENABLE_FIDO_ENGINE=ON -DFV_BUILD_TESTS=OFF -DCMAKE_SYSTEM_NAME=Generic \
  -DCMAKE_C_COMPILER=arm-none-eabi-gcc -DCMAKE_TRY_COMPILE_TARGET_TYPE=STATIC_LIBRARY \
  '-DCMAKE_C_FLAGS=-mcpu=cortex-m33 -mthumb -fstack-usage' -DCMAKE_BUILD_TYPE=Release
cmake --build build-fido-arm --target fv_fido_engine -j4
```

The library compiled and a temporary main calling `fv_fido_engine_command` linked
against it and `fv_crypto` using `--specs=nosys.specs -Wl,--gc-sections -lm`.
Newlib emitted its expected unimplemented-syscall warnings for this standalone
smoke executable. This is not a board image or executable hardware test.

Standalone smoke ELF: text 261,416 bytes; data 2,228; BSS 49,780. The caller's
64 KiB object image is not allocated in that smoke main, nor is the rest of V2
firmware. Do not interpret these figures as total product memory usage.
Largest individual engine stack frames: assertion 6,696 bytes, registration 5,896,
credential management 1,712. Nested call chains, Mbed TLS heap and runtime stack
watermarks still require integrated firmware measurement.

## Remaining gates

F2 encrypted SD persistence; F3 HID/MSC/UI/real unlock; F4 local UI/browser server;
F5 hardware interoperability/fault testing. Review upstream security changes before
hardware/release readiness. Bind reset timing to USB enumeration rather than engine
reopen during F3. Preserve physical-display and production-hardening release gates.

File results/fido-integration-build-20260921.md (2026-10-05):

# F3 development integration evidence — 2026-09-21

Implemented an opt-in composite FIDO HID/MSC/CDC adapter, worker-owned engine and
encrypted store, atomic modal mailbox, device re-verification, RP/freshness cache,
explicit local store initialization and asynchronous HID cancellation/keepalives.
Added real USB test client and extended the framebuffer viewer with request-bound
input generations. No hardware was flashed or accessed for this evidence.

Validation:

- Full desktop suite: **32/32 passed**, normal and ASan/UBSan
  (`ASAN_OPTIONS=detect_leaks=0`). After adding the scheduling test, focused runs
  cover all **33** current cases across full and focused evidence. Latest adapter,
  transport, UI and scheduling changes pass the sanitizer rerun.
- Actual firmware adapter compiled in a desktop peer with simulated platform/UI,
  real engine, HID framing and encrypted file-backed storage. Independent
  python-fido2 verifies registration and signed assertions, encrypted reopen,
  first unlock/RP change/expiry, physical rejection, cancellation, wrong-secret
  shared attempt accounting, UV token use, malformed RP rejection, expired reset
  rejection after engine reopen, and late cancellation after worker completion.
- HID tests cover fragmentation, sequence error, receive timeout, pending-buffer
  ownership, busy, cancellation, INIT resynchronization and output backpressure.
  UV tests cover exact first/max age boundaries, RP binding and clock wrap.
- UI tests cover explicit destructive initialization confirmation, approve/reject,
  fresh modal state and credential wiping. Physical debounce and real inter-core
  races still require hardware acceptance.
- USB bridge tests cover batch deferral during crypto, disk service during prompt
  windows, cached status/sync and bus invalidation deferred until worker completion.
- Re-verification test uses the actual vault lifecycle, preserves the VMK and
  generation on success, charges one wrong attempt and denies a locked session.
- Cortex-M33 composite firmware and existing FIDO-disabled device UI firmware
  both compile/link successfully. The smoke client help and Python compilation
  checks pass. UF2 packaging succeeded without flashing.

Build command: see `docs/AI/v2-fido-testing.md`. The current composite ELF reports
413,764 bytes text, 346,424 bytes BSS, zero separate data in `arm-none-eabi-size`.
This is not a peak heap/stack measurement. The worker stack reservation is 65,536
bytes; compiler frames include re-verification at 7,624 bytes and FIDO dispatch
at 216 bytes, in addition to nested engine/store/crypto frames.

UF2: `build-pico-fido/fuse_vault_security.uf2`
SHA-256: `1df28ec57a80391bb3cd7eb560af607d4eb92a8dd5affbe1c2d94bc23ece129e`

F3 software is ready for initial development board tests. Its physical acceptance
is still pending, so the formal stage remains in progress. No browser/site,
physical TFT, real dual-core timing, power-cut, SD load, stack high-water or
certification result is implied by these tests.

## Hardware discovery follow-up

After the user flashed the first build, read-only host inspection confirmed four
USB interfaces, HID interface 3, and an ACL granting adam read/write access to
`/dev/hidraw3`. Linux identified it as a FIDO token. The installed python-fido2
parser nevertheless raised `ValueError("Not a FIDO device")`: it clears report
size/count after INPUT and requires both to be repeated for OUTPUT. The original
27-byte descriptor inherited size according to HID semantics; the corrected
29-byte descriptor states both explicitly. The USB descriptor length now comes
from the same shared array. The firmware adapter regression now parses the actual
callback bytes with python-fido2 and passes, and the corrected ARM image builds.
The hash above identifies the corrected UF2. No flashing was performed by the
agent; discovery on the corrected flashed board is still to be confirmed.

## User-confirmed board smoke test

The user subsequently reported successful GetInfo, registration and login using
board `66ED2A91873CF67F` and the corrected image. The smoke client printed
“Registration verified” and “Login signature, RP, UV/UP flags and zero counter
verified.” Keepalives progressed through PROCESSING / UPNEEDED. This is evidence
of successful hardware registration and assertion, not yet reconnect persistence,
concurrent disk integrity, cancellation/fault acceptance or browser compatibility.

## Active-load scheduling correction

User subsequently confirmed reconnect persistence and login with the filesystem
mounted, but reported freezes under active disk traffic. The visible HID I/O error
was likely caused by unplugging during an operation, per the user's clarification.

Inspection found that the SDK's no-OS `tud_task_ext` drains the event queue until
empty. Deferred MSC callbacks enqueue retries, so it can indefinitely starve
outer-loop UI/CDC/FIDO polling. The pinned generated USBD copy now handles at most
eight events per call. Test `tools/test_usb_task_budget.py` compiles the exact task
function body against a retrying event source whose completion requires application
progress. The original fails deterministically with starvation; the patched version
returns to UI/CDC/FIDO polls and completes. Normal and ASan/UBSan runs pass.
Sanitizer execution uses `ASAN_OPTIONS=detect_leaks=0` because LeakSanitizer cannot
run under this environment's tracing. The actual MSC BOT driver overlap/durable
completion suite also passes under ASan/UBSan for 4096/16384/32768-byte buffers.

Composite FIDO and FIDO-disabled UI firmware both rebuild successfully. The hash
above now identifies the scheduling-corrected UF2. Hardware load retesting remains
pending; the eventual USB restart was not independently reproduced or diagnosed.

## Configurable verification follow-up

Added persistent on-device timed/same-site and unlocked-session modes. Defaults
remain unchanged for existing stores. No separate USB auto-lock timer added. The
firmware peer verifies encrypted reopen preserves the setting, session reuse across
RP/time changes still requires presence, switching to strict restores re-verification,
locked/invalid setters are rejected, and injected save failure is not reported as
success. Save clears cached UV and host tokens. Full normal suite: 33/33 passed;
focused FIDO/UI ASan/UBSan suite: 9/9 passed (detect_leaks=0), followed by normal
and sanitized failed-save regression runs. Composite and FIDO-disabled UI ARM
builds passed. Hash above identifies the latest policy-capable UF2. On-board policy
selection/persistence testing is pending; no device was flashed by the agent.

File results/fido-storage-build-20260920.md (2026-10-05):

# V2 encrypted FIDO store validation — 2026-09-20

F2 portable store implementation and test integration. No board was flashed and
no physical SD or OTP was changed. Format/API documentation is in
[the storage design](../docs/AI/v2-fido-storage.md); staged progress is in
[the delivery ledger](../docs/AI/v2-fido-progress.md).

## Changes

- `fv_fido_store` uses private sectors 16–2063, two independently keyed banks,
  the vault's selected XTS cipher layers, and existing V2 ciphertext sector HMAC.
- Domain-separated engine/bank/integrity/manifest keys derived from unlocked VMK
  and authenticated volume descriptor. No keys retained in the store handle.
- Explicit destructive initialization; opening is read-only and never implicitly
  formats. Authenticate manifests, every sector and the complete ciphertext image.
- Write/sync/readback before publishing a new manifest; stale writers and ambiguous
  failures fault the session. Internal ACTIVE authority is checked before access.
- No internal anti-rollback anchor or snapshot flash commits. Valid SD replay is
  deliberately allowed; destruction/attempt state remains internal authority.
- Actual pico-fido engine connected through its durable callback to file-backed
  encrypted media in a test target. Normal firmware attachment remains F3.

## Host validation

```sh
cmake --build build-fido -j4
ctest --test-dir build-fido --output-on-failure
cmake --build build-fido-sanitize -j4
ASAN_OPTIONS=detect_leaks=0 ctest --test-dir build-fido-sanitize --output-on-failure
```

The suite now has 30 CTest cases. The final full normal/sanitizer runs passed the
29 other cases, including both encrypted engine tests. The store fixture was then
corrected to distinguish rejection by internal authority from wrong-volume
cryptographic rejection after the new authority guard, and rerun separately:

```sh
ctest --test-dir build-fido -R '^fido_store$' --output-on-failure
ASAN_OPTIONS=detect_leaks=0 ctest --test-dir build-fido-sanitize -R '^fido_store$' --output-on-failure
```

Both focused store reruns passed. All 30 cases are validated in normal and
ASan/UBSan builds across the full suite and focused rerun.
LeakSanitizer is disabled in this traced environment; no leak-check claim.

Coverage includes:

- AES, Camellia and four ordered layers; USB/header region preservation; USB file
  round-trip; key-domain separation; FIDO image/key preservation across credential
  rewrap; locked/pending-destruction authority denial; full destruction then SD replay.
- 370 commit interruption cases: all 36 write calls (zero/17/512/4095-byte partial
  writes), four sync calls and 37 read calls, each with unsynchronized writes either
  retained or discarded on simulated power loss. Recovery accepts only complete
  old/new images. Includes bank reuse with previously valid inactive contents.
- Initialization interruptions, every open-read failure/output wiping, silent
  payload/tag/manifest write corruption, wrong VMK/volume/bank, stale writers,
  latest committed payload corruption, valid whole-image rollback, and replayed
  authentic sectors/tags beneath a different valid manifest.
- Independent python-fido2 client verifies real ES256 signatures after encrypted
  reopen and vault credential change, both UV-token protocols, resident/nonresident
  credentials, denial, permissions, token expiry, deletion/reset, full store,
  zero-counter/no-write assertions, real SD-write failure and malformed requests.

The test media models a synchronized file checkpoint and loss/retention of pending
writes. Authority/UI/entropy fixtures are test-only; this is not physical flash,
SD controller power-loss, trusted UI or USB compatibility validation.

## ARM compilation and linking

The existing Cortex-M33 build configuration compiles `fv_fido_store` and its V2
security/storage dependencies. A temporary standalone main calling both store
open and engine command linked with the engine/store/security/storage/crypto
archives, `--specs=nosys.specs -Wl,--gc-sections -lm`.

Standalone smoke ELF: text 275,912 bytes; data 2,228; BSS 123,108. Includes a 64 KiB
image, a vault session and response buffer, but not the real board USB/UI/worker
allocation. Newlib emitted its expected standalone syscall-stub warnings. It is
not a hardware firmware image or a measured runtime memory budget.

Compiler-reported individual store frames: write snapshot 12,816 bytes, open
11,704 bytes. These stack allocations are wiped on return. Combined engine call
chains, worker scheduling, heap demand and stack watermarks require F3/F5 checks.

## Next

F3: integrate standard HID alongside MSC, use the store from the single worker,
attach real unlock/reverification/approval and close both engine/store on shared
session invalidation. No store initialization may be triggered by a host command
or by recovery failure. Add bounded scheduling around storage batches and UI waits.

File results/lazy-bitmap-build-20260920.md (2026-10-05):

# Lazy bitmap build — 2026-09-20

Artifact: `build-pico-device-ui/v2_device_ui_bitmap.uf2`
SHA-256: `16556170fdc678259111665731b2f4d144d53ff00c30e36a08b5d667ee4b0d8b`
Highest loadable UF2 payload end: `0x10022900` (journal starts 0x101fe000).

For the previously measured 122909696 physical sectors:
- Logical capacity: 115224146 sectors.
- Metadata: 7681610 sectors; bitmap: 1876 sectors (938.0 KiB).
- Setup writes only the bitmap, headers and persistent authority state; it does
  not clear the tag area or data area. No on-device timing measured yet.

Validation: 25/25 desktop tests and 25/25 ASan/UBSan tests passed with leak detector
disabled. Covers failures before/after every first-write write/sync operation,
crossing bitmap sectors, preservation of unrelated bits, dirty old SD contents,
forged state/tag rejection and independent legacy-envelope unlock/read/write/
credential-change compatibility. ARM UI firmware build passed. UF2 bounds checked.

No firmware flashed and no attached-board storage/OTP operations performed.
Existing volumes stay at layout 1; new creates use layout 2. For setup instructions
and wire-format details see docs/AI/v2-lazy-metadata.md.

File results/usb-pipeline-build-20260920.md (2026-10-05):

# Double-buffered MSC firmware — 2026-09-20

Artifact: `build-pico-device-ui/v2_device_ui_pipeline.uf2`
SHA256: `a66dd9949bde3b7a648dbd04c41227d8d76437436183027abedce262c9fb11d1`
Highest UF2 payload end: `0x10025300`; all payloads below journal at `0x101fe000`.

- Two 32 KiB buffers: USB endpoint + worker scratch, 56 KiB more than before.
- ELF size: text 158252, data 0, BSS 198444 bytes.
- Main RAM static allocation ends at `0x2003465c`; heap limit `0x20080000`.
  About 302 KiB remains between these addresses (not a worst-case runtime audit).
- Writes overlap next USB receive with crypto/authentication/SD; final command
  status waits for the last durable write. Reads prefetch within command bounds.
- Existing vault format, credentials, OTP and flash journal unchanged.
- SDK TinyUSB source untouched; pinned build-time command/reset extension.

Validation:
- All 25 host tests passed normally and under ASan/UBSan.
- Affected USB tests rerun after final reset handling changes; all pass in both builds.
- Real patched TinyUSB BOT driver tested with a delayed worker at 4, 16 and 32 KiB
  under ASan/UBSan: next receive while worker pending, no premature successful CSW,
  read prefetch ownership, late failure and BOT reset drain/wipe all pass.
- Firmware build and UF2 address-range validation pass.
- LeakSanitizer disabled because it cannot run under this sandbox's ptrace;
  AddressSanitizer and UBSan remain enabled.

Not flashed by this task. Real-device copy/checksum, reconnect, error handling and
throughput comparison remain the next hardware step. No speed gain claimed from
host timing. See `docs/AI/v2-usb-pipeline.md` for implementation and test procedure.

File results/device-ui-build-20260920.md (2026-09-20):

# Device UI development build — 2026-09-20

Artifact: `build-pico-device-ui/v2_device_ui.uf2`
SHA-256: `ddb7785ec2ac0f9320400fa0667bc730d315f496d5256adc3ed972e8b22dca1d`
Highest UF2 payload end: `0x10021a00`; reserved authority flash begins
`0x101fe000`. Every loadable UF2 block is below the journal.
ELF size: text 143812 bytes, BSS 139736 bytes (including worker stack).

## Implemented

USB-C-preferred mux; full-card capacity calculation using existing format;
firmware-owned 160x80 framebuffer and physical/debug input; confirmed direction
credential; 1–4 cipher layers; initial provisioning/creation; lock/unlock;
authenticated failure-policy changes; explicit destructive reset with token
revocation; GTK framebuffer viewer. FIDO area reserved, not implemented.

## Validation

- 23/23 desktop CTest checks passed.
- 23/23 ASan/UBSan checks passed with `ASAN_OPTIONS=detect_leaks=0`; affected
  UI/USB tests rerun after final changes, 4/4 passed.
- ARM development UI/MSC build succeeded with warnings treated as errors.
- ARM UI build with remote screen/input and fixture unlock disabled succeeded.
- Existing non-UI MSC firmware build succeeded.
- Viewer imports/bytecode/CLI and frame validation passed; GTK3 and Cairo present.
- Rendered setup review framebuffer inspected. No interactive desktop display
  available to this process (`Gtk.init_check` false), so live GTK interaction
  awaits the user's desktop run.
- No firmware flashed and no SD/OTP changes performed during this build task.

## Next board checks

Follow `firmware/security/DEVICE_UI.md`. Flash working sample 66ED2A91873CF67F,
open old test vault before starting the viewer, explicitly erase it and create the
full-card volume. Confirm host filesystem format, file/hash round-trip, cold boot
locked/unlock, persistent policy and mux power combinations. Retain old failing
sample unchanged. Debug flags remain enabled for this migration artifact.

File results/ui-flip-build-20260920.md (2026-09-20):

# UI flip build

Artifact: `build-pico-device-ui/v2_device_ui_flip.uf2`
SHA-256: `187936be35e6c14647bd0a6a0d36a0f5239a1a0d0e18505686024451aca6cb04`
Highest payload end: `0x10022b00`, below the persistent journal.

Left/Right on the locked/unlocked home screen flips pixels and directional
controls 180 degrees. Select/Back retain their roles. The preference is volatile
and survives UI/session transitions while power remains applied. No storage
format, authority or key changes; existing vault is preserved.

ARM build and desktop UI tests pass, including ASan/UBSan. Tests compare every
pixel against the 180-degree transform, flip twice back to the original frame,
verify equal credential bytes with inverse physical directions, and exercise
unlocked menu navigation and preference retention/reset. Physical orientation
acceptance awaits user flashing. Firmware has not been flashed by this task.

User reports prior bitmap firmware successfully copied files and worked through
USB-A; this is user-reported functional validation, not a measured benchmark.

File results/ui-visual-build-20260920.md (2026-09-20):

# Credential display refresh — 2026-09-20

Four horizontal number reels show adjacent values and a highlighted active wheel.
Word ranges and review words occupy the corresponding D-pad positions; range
labels use three-letter prefixes as in V1. Compact Back/Done icons replace
repeated direction instructions. Credential values, mappings, storage, and
orientation handling are unchanged. No vault reset is required.

Validation: host device_ui_and_capacity passes normally and with sanitizers;
firmware builds; actual framebuffer previews inspected for wheels, word range
selection, and word review. Hardware validation remains for the next flash.

Artifact: build-pico-device-ui/v2_device_ui_visual.uf2

SHA256: d7f24fcbd7142f941368de5c146f2e83f01b18a6fd638150b719f06001c20530
Highest UF2 payload end: 0x10024800; below journal at 0x101fe000.

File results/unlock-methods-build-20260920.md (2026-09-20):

# Unlock methods build

Artifact: `build-pico-device-ui/v2_device_ui_methods.uf2`
SHA-256: `8015b13bab4efad13ff8299d35886aa40f9a9f40dc5566407a9389f9d17dbb94`
Highest payload end: `0x10023b00`; authority journal is preserved.

Implemented setup method selection, visible direction arrows, four 00–99 code
wheels, and four words through the stable V1 64-word directional tree. New profiles
3 and 4 have canonical four-byte encodings and preserve profiles 1/2. Unlock method
is selected from the flash-anchored header without spending an attempt. Changing
method from the unlocked menu verifies the current credential and rewraps the
existing VMK, preserving files, cipher stack, policy and OTP token slot.

Validation: full 25-test desktop and ASan/UBSan suites passed; affected five tests
rerun after final adjustments. Covers all 64 word selections, wheel wraparound,
confirmation, cancellation, profile bounds, unchanged VMK/file data/token across
method changes and rejection of forged profile hints without attempt commits.
Method, wheel, word-tree/review and visible-pattern framebuffers visually inspected.
ARM firmware build passed. No board flash or OTP/storage operations performed.

Board acceptance: flash, unlock the existing pattern vault, unmount filesystem,
choose Change unlock method, enter current credential and confirm a new one. Verify
unlock and files after cold reconnect; do not use Erase and set up merely to change
method. New profiles are unsupported by older firmware. Release checklist remains.

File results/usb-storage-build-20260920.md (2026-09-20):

# USB mass storage implementation — 2026-09-20

Artifact: build-pico-usb-storage/v2_usb_storage.uf2
SHA256: f84f2c61108d45b42d1dcd7945765f8fdfcc93056a7bca493403e3e0d9e7c79e
UF2 payload end (exclusive): 0x10024900; all blocks below journal 0x101fe000.
SDK 2.3.0, Release, fuse_vault, RP2350 ARM Secure.
MSC and DEBUG_SESSION enabled; enrollment, OTP inspection, deferred startup and
boot trace disabled. Normal recovery/worker initialization retained.

Implementation: CDC + MSC; starts locked, debug public-fixture unlock, persistent
vault read/write with 4 KiB batches, serialized worker ownership, error senses,
eject/reset/suspend lock and buffered plaintext clearing. Host helper rejects
wrong USB identity/capabilities and refuses lock on locally mounted filesystems.
No vault formatting, provisioning or device operation was performed in this turn.

Validation:
- 21/21 desktop CTest tests pass, including MSC callbacks and bus invalidation.
- 21/21 pass under AddressSanitizer/UBSan with ASAN_OPTIONS=detect_leaks=0.
  Initial LeakSanitizer runs failed because this environment uses ptrace; leak
  checking is therefore not claimed.
- MSC firmware and the existing non-MSC worker-check firmware build successfully.
- Host session helper Python compilation and CLI-help checks passed.
- git diff --check passed.
- Real host enumeration, block I/O, formatting, lock/unlock and cold-start remain
  pending physical flash. No throughput claims; callbacks synchronously wait for
  worker completion. See firmware/security/USB_STORAGE.md for limitations.

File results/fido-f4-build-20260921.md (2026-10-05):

# F4 software validation — 2026-09-21

Implemented:

- On-device resident credential list, long-label scrolling, confirmed deletion and
  empty-list state. Stable IDs prevent stale-index deletion. Worker closes the
  local engine management scope after each operation; failed deletion faults/clears
  the engine, and success follows durable encrypted commit.
- Loopback-only Python WebAuthn server with SQLite public records, exact Host/Origin
  checks, session-bound single-use expiring challenges, ES256/UV/UP enforcement and
  user-handle binding. Browser page supports register, account login, discoverable
  account selection, cancel and readable results.
- Preserved existing credentials, verification setting, composite USB and event
  budget. No flashing, physical credential creation/deletion or SD changes performed
  by the agent.

Validation:

- Full desktop CTest suite: **35/35 passed**.
- FIDO/UI ASan+UBSan focused suite: **11/11 passed**, `detect_leaks=0` due to the
  environment's tracing limitation. Final discoverable-account and allow-list
  deletion assertions were rerun normally and under sanitizers and passed.
- WebAuthn verifier tests use the actual C engine and encrypted file-backed store;
  no virtual browser authenticator. Both Alice/Bob assertions verify, including
  getNextAssertion/account selection and server/engine reopen. Negative origin,
  RP, challenge, replay, expiry, session, signature, UV and user-handle cases reject.
- Actual HTTP handler tested without sockets for Host/Origin, content type, static
  routing, cookie attributes and consumption of failed challenges.
- Firmware adapter tests cover local list/delete, unknown/stale IDs, locked denial,
  persistence after reopening, deleted allow-list credential rejection and continued
  signing by the surviving credential. UI tests cover selection, cancel-by-default
  confirmation, stable ID handoff, fresh generation and empty-list behavior.
- Composite FIDO and FIDO-disabled device UI firmware compile/link successfully.
- In-app browser UI inspected using the Browser skill at localhost:8000: page loads,
  controls render and login before registration shows the expected error. Temporary
  server/tab stopped after checking. No physical WebAuthn ceremony claimed.

Artifact: `build-pico-fido/fuse_vault_security.uf2`
SHA-256: `9495546184e2dc179af8721af947fbb6d3c175c03f4f9cb71afb43e3943e9a36`
ELF size: text 415,548 bytes; BSS 347,068 bytes; separate data 0.

User hardware/browser follow-up (2026-09-21): registered Alice and Bob, deleted Bob,
and reported everything working as expected. Supplied screenshot confirms Alice
discoverable login verified by the local WebAuthn server, with UV/UP true and counter
zero. These are user-run physical tests, separate from the agent checks above.
Browser identity and coverage of both Chromium/Firefox, plus explicit rejection of
the deleted credential after reconnect, have not yet been confirmed.

Subsequent real-site user report (2026-09-21): Twitter and GitHub worked. User
clarified that GitHub's initial "Authentication failed" was an existing-passkey
authentication gate before registering the new passkey. Using the existing
passkey allowed Fuse Vault registration to succeed; no firmware defect was
established. Browser/version and separate real-site login/reconnect coverage
remain unspecified. Remaining acceptance runbook:
`docs/AI/v2-fido-browser-testing.md`.

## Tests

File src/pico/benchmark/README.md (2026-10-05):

# Laptop-controlled pipeline benchmark

The laptop sends test bytes over USB. The RP2354 encrypts each 512-byte sector,
writes the ciphertext to SD, and acknowledges the batch after the SD write
completes. For reads it fetches ciphertext, decrypts it, and returns the plaintext
for laptop verification. No disk is mounted and no RAM disk is exposed.

This is an already-unlocked test session using public test keys. Configuration
stays in RAM. There is no password handling, VMK wrapping, OTP programming or persistent
vault header yet. Optional `--integrity` enables HMAC-SHA-256 and packed metadata;
omitting it retains the cipher-only baseline. Additional stages can be added
to the same engine and timed independently. This is protocol 5 firmware, with Pico SHA acceleration enabled by default.

## What can be varied without reflashing

- Stack: `raw`, `aes`, `camellia`, `aes,camellia`, `camellia,aes`, or any ordered
  combination of up to four supported layers, including repeated algorithms
  with independent test keys per position.
- Batch: any whole-sector size from 512 bytes through 32768 bytes.
- Total test size: any whole-sector size up to 4 MiB; final batches may be short.
- Test seed and optional per-batch logging.

The crypto unit is always 512 bytes regardless of the USB/SD batch size. `raw`
is the same USB/SD path with encryption disabled for comparison (HMAC remains active if `--integrity` is set). The SD clock
is a build setting, initially 25 MHz; it is reported as a requested frequency,
not a measured pin clock. SD remains native four-bit PIO/DMA with multi-block
operations and CRC/status checking.

## Source structure

| Path | Responsibility |
|---|---|
| `src/shared/crypto/` | Prepared ciphers and ordered pipelines |
| `src/shared/storage/include/fuse_vault/block_device.h` | Raw block-device interface |
| `src/pico/platform/sd_native.c` | Reused four-bit SD adapter |
| `src/shared/benchmark/engine.c` | Configurable block processing and stage timings |
| `src/shared/benchmark/protocol.c` | Fixed, explicitly encoded binary headers |
| `src/pico/benchmark/worker.c` | Core-1 platform adapter |
| `src/pico/benchmark/usb.c` | Core-0 USB CDC framing and buffer ownership |
| `src/host/tools/board_bench.py` | Linux laptop runner, verification and JSON logs |

V1's native SD dependency was copied with its licenses to `third_party/pico_sd`.
Its recorded upstream revision is `d5e453404cdbfaa55ab30d285b6ab0b730e84a05`;
the copy includes the actual archived snapshot and any V1 adaptations, not an
assumption that an upstream checkout is identical. No V2 source target depends
on V1 source. SD pin mapping is CLK=4, CMD=5, DAT0..3=6..9. PIO1 and DMA IRQ1 are
owned by the SD worker. Card-detect polarity remains unconfirmed; the default
build relies on initialization/I/O errors for missing or removed cards.

## Build and first flash

```sh
cmake -S src/pico/benchmark -B build-pico \
  -DPICO_SDK_PATH=/home/adam/pico-sdk \
  -DCMAKE_BUILD_TYPE=Release -DPICO_NO_PICOTOOL=1
cmake --build build-pico -j4
picotool uf2 convert build-pico/fuse_vault_v2_bench.elf \
  build-pico/fuse_vault_v2_bench.uf2 --family rp2350-arm-s --platform rp2350
```

The offline build avoids downloading picotool. The UF2 already in `build-pico`
was produced using the installed executable available under
`v1/firmware/build/_deps/picotool/picotool`; that is a build-tool reuse only.
An installed picotool package can also provide automatic UF2 generation through
the SDK if `PICO_NO_PICOTOOL` is omitted.

Load the UF2 through BOOTSEL. Use **USB-C only**, leave USB-A empty, and leave the
damaged display disconnected. Firmware holds the backlight off and uses fixed
USB-C routing, disabling the mux if either USB-A presence pin asserts. This is
bench routing, not the final dual-connector policy.

Completely remove power after flashing if the SD card previously ran in SPI
mode. This firmware enumerates as **cafe:4021**, product `Fuse Vault V2 PIPELINE`.
It has USB CDC only. Old cafe:4020 RAM-disk firmware is not accepted by this runner.
Flashing is manual; the script never flashes hardware. Nothing writes SD at boot.

## First check: no SD access

Identify the `/dev/serial/by-id/...` path, then:

```sh
python3 src/host/tools/board_bench.py --port /dev/serial/by-id/DEVICE \
  --info-only --output results/v2-info.json
```

This checks USB protocol/version, CPU clock and configuration without opening SD.
The script uses the Python standard library and needs permission to open that
serial port. Use one serial client at a time. No block-device permissions or
host filesystem formatting are needed.

## First complete flow

**Use a disposable SD card. The test overwrites the first `--total-bytes` bytes
plus packed metadata when `--integrity` is enabled, including any partition table
or vault header in that range. For 4 MiB of data, authenticated mode touches
4,474,368 physical bytes.**
Both the host flag and the protocol configuration explicitly enable scratch
writes. All operations are bounded to the configured first 1–8192 sectors.

A small first test:

```sh
python3 src/host/tools/board_bench.py --port /dev/serial/by-id/DEVICE \
  --allow-scratch-write --stacks aes --batch-bytes 4096 --total-bytes 65536 \
  --label 'Board 1 / disposable card model' \
  --firmware build-pico/fuse_vault_v2_bench.uf2 \
  --output results/v2-first-flow.json
```

A matrix using defaults (five stacks, five batch sizes, 4 MiB per configuration):

```sh
python3 src/host/tools/board_bench.py --port /dev/serial/by-id/DEVICE \
  --allow-scratch-write --label 'Board 1 / disposable card model' \
  --firmware build-pico/fuse_vault_v2_bench.uf2 \
  --output results/v2-matrix.json
```

For each configuration, the runner:

1. Prepares public test keys on the board once and initializes SD.
2. Sends deterministic bytes in batches; each acknowledgment follows encryption
   and completed SD writes. No routine payload readback occurs in the write path.
3. Requests the same range back, decrypts on the board, and compares every byte
   on the laptop. Generation of test data occurs before timing.
4. Ends the session, syncs and clears prepared keys, then records the outcome.

Authenticated configuration formats the metadata region to unset before each
case. This initialization time is logged in the configuration response, outside
the transfer phases. It does not initialize the full payload.

The same data/range is reused between configurations. Tests measure a small
repeated scratch workload, not full-card steady-state or filesystem throughput.
If interrupted, reports retain completed cases and partial counts for the current
case with `complete: false`. Commands are never retried automatically. After a
transport timeout/framing failure, physically reconnect before starting again:
a pending write may already have reached the card.

## Results

The console prints one verified result per configuration. JSON also includes:

- Host, run label, seed, timestamp, optional UF2 SHA-256 and port identity.
- Cipher order, batch bytes, total/completed bytes and request counts.
- Key setup time, encryption/decryption time and ciphertext SD read/write time.
- HMAC time, metadata I/O time, and metadata sectors read/written.
- Actual physical footprint, including metadata.
- `transaction_seconds`: summed host request-to-response durations, including
  USB, framing, worker handoff and acknowledgment. Read duration includes receipt
  of all returned bytes, but excludes the subsequent laptop comparison.
- `kib_per_second`: completed payload KiB / transaction seconds.
- `wall_seconds` and `wall_kib_per_second`: entire phase including laptop loop,
  bookkeeping and read verification.
- Verification result and final sync result. `--log-batches` adds per-request
  timings and LBAs for detailed analysis.

USB-only time is not measured directly. The difference between host transaction
time and board crypto/HMAC/data/metadata time also contains framing, queueing and host overhead;
do not label it pure USB transfer time. Raw runs report zero crypto time.

The pipeline currently processes one complete batch at a time. Core 0 services
USB while core 1 works, but USB payload transfer, crypto and SD are not yet
pipelined across multiple outstanding batches. This establishes a measurable
baseline; later overlapping buffers can be compared against it. CDC uses bulk
USB endpoints; the nominal serial baud rate is not its actual transfer rate.
These rates are not a prediction of USB MSC/SCSI or filesystem performance.

## Verification state

Desktop tests cover cipher correctness, SD batch/error contracts, the real
benchmark engine, scratch bounds, malformed frames, failure handling, partial
host I/O, and a complete Python-runner-to-C-engine flow backed by a temporary
file. The integration matrix verifies multiple stack orders/batch sizes including
short final batches and detects deliberately altered returned bytes.

Release and address/undefined-sanitizer tests pass; LeakSanitizer is disabled in
this traced environment. The RP2354 ELF and UF2 build. The current image uses
approximately 98 KiB code and 72 KiB BSS, excluding runtime stack high-water
measurements. Core 1 has a 16 KiB stack allocated in main RAM.

**First hardware validation passed on 2026-09-16.** Board `317741A1459A6F94`
completed the USB handshake, a 64 KiB AES smoke test, and all 25 stack/batch
configurations (4 MiB written and verified per configuration). See the
[hardware baseline](../../../results/v3-hardware-baseline.md) and its raw logs.
This establishes the tested flow on this board/card, not broader reliability
or performance with authentication/metadata.

## Authenticated-storage comparison (protocol 5)

Reflash the newly built UF2 before using this runner. Older protocol replies are
shorter; the runner rejects their version before reading the remaining header. Disconnect/reconnect after flashing.
The USB ID remains cafe:4021, but the binary protocol version is checked.

Start with one stack and a small range, adding `--integrity`:

```sh
python3 src/host/tools/board_bench.py --port /dev/serial/by-id/DEVICE \
  --allow-scratch-write --integrity --stacks aes --batch-bytes 4096 \
  --total-bytes 65536 --firmware build-pico/fuse_vault_v2_bench.uf2 \
  --output results/v5-auth-first-flow.json
```

Then run the desired matrix once without and once with `--integrity`, saving
separate reports. Use the same board, card, firmware, stacks and batch sizes.
The runner verifies the returned bytes in both modes. Authenticated reads check
all requested written tags before decryption; corruption is board status 5.

The authenticated hardware smoke test and all 20 paired protocol-4 configurations
passed on 2026-09-16. See the [paired comparison](../../../results/v4-authenticated-baseline.md).
Historical V3 results remain an unauthenticated baseline.
See [layout and cache details](../../shared/storage/README.md) and
[device-state placement](../../../docs/AI/v2-security-state.md).

## SHA accelerator comparison

The default firmware now uses `FV_HMAC_PICO=ON`. First flash the new UF2 and run
`--info-only`. It must report `hmac_backend: pico-sha256-cpu-fed` and
`hmac_self_test: true`. The check compares hardware tags against a known vector
and the software reference before permitting SD operations.

Rerun the same five stacks at 4 KiB and 32 KiB batches, 1 MiB each:

```sh
python3 src/host/tools/board_bench.py --port /dev/serial/by-id/DEVICE \
  --allow-scratch-write --integrity --batch-bytes 4096 32768 \
  --total-bytes 1048576 --label 'SHA accelerator comparison' \
  --firmware build-pico/fuse_vault_v2_bench.uf2 \
  --output results/v5-sha-auth-matrix.json
```

Compare HMAC time as well as end-to-end throughput with
`results/v4-auth-matrix.json`. For a same-protocol software reference, configure
another build directory with `-DFV_HMAC_PICO=OFF`, flash its UF2 and repeat the
same command/report setup. Backend selection is a build option, not an SD format
change. The 25 MHz SD clock, XTS algorithms, full tags and metadata layout remain
the same. The on-board self-check and all ten accelerated configurations passed
on 2026-09-16. HMAC time fell about 84%; an AES encryption timing regression
limits write gains in this build. See the [measured comparison](../../../results/v5-sha-comparison.md).

See [backend implementation and tests](../../shared/crypto/backends/README.md).

## AES timing diagnostic

The whole-firmware `copy_to_ram` diagnostic failed to enumerate on USB after
flashing and power cycling. No performance measurements were obtained.

The narrower replacement is `build-pico-aes-ram/fuse_vault_v2_bench.uf2`, built
with `-DFV_AES_RAM=ON` and normal flash startup. This optional diagnostic moves
only AES block encryption/decryption into SRAM; hardware HMAC remains enabled.
The option defaults OFF. The build and linked addresses are verified. Board startup, HMAC self-check
and AES/Camellia authenticated round trips passed. AES encryption improved
from 1,054 to 634 ms/MiB, but Camellia slowed in the new layout; this remains
a diagnostic rather than a final optimization. See the
[investigation and build commands](../../../results/v5-aes-investigation.md).

## Both ciphers in SRAM

Firmware builds now default to `FV_CIPHERS_RAM=ON` (desktop builds remain OFF).
This places AES block encrypt/decrypt, Camellia ECB/Feistel and its four round
lookup tables in SRAM using the SDK startup copy mechanism. Startup, USB,
key setup and pipeline orchestration retain their normal placement. AES lookup
tables already reside in RAM. Hardware SHA remains enabled.

Ready artifact: `build-pico-ciphers-ram/fuse_vault_v2_bench.uf2`.
Build with the usual firmware CMake command, using that build directory and
`-DFV_CIPHERS_RAM=ON -DFV_HMAC_PICO=ON`; convert the ELF with the documented
picotool command. To reproduce historical flash/AES-only builds, explicitly
set `-DFV_CIPHERS_RAM=OFF` (and select `FV_AES_RAM` as required).

The linked initialized RAM increases from 15,440 to 19,200 bytes: **3,760 bytes**.
All selected routines and tables have verified SRAM addresses; the four
Camellia tables match the previous image byte-for-byte. All eight desktop
suites pass. All 30 board cases passed across three complete matrix runs
on 2026-09-16, with stable cipher timings. See the
[repeated hardware benchmark](../../../results/v5-ciphers-ram-benchmark.md).

After flashing, run three separate full-matrix passes, preserving each report:

```sh
for run in 1 2 3; do
  python3 src/host/tools/board_bench.py \
    --port /dev/serial/by-id/usb-Fuse_Vault_Fuse_Vault_V2_PIPELINE_317741A1459A6F94-if00 \
    --allow-scratch-write --integrity --batch-bytes 4096 32768 \
    --total-bytes 1048576 --log-batches \
    --label "Both ciphers in SRAM, repeat $run" \
    --firmware build-pico-ciphers-ram/fuse_vault_v2_bench.uf2 \
    --output "results/v5-ciphers-ram-matrix-$run.json" || break
done
```

This covers raw plus AES, Camellia and both stack orders at two batch sizes.
Compare per-stage timings and the spread across repeats before broadening to
longer transfers, other batch sizes and hardware interruption/corruption tests.

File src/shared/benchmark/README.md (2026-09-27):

# Benchmark engine and protocol

This module connects an already-prepared cipher pipeline to a raw block device.
It has no Pico or USB dependency. `fv_bench_engine` receives a device, opener and
microsecond timer; `fv_bench_execute` transforms an owned buffer and returns
status/timings. Desktop tests and RP2354 firmware execute this same code.

## Protocol 5

All integers are unsigned and little-endian. No C structs are transmitted.
One request at a time; no automatic retry or magic-byte scanning after an invalid
header. Requests and responses are carried over USB CDC binary bulk data.

Request: eight 32-bit words (32 bytes):

| Word | Field |
|---|---|
| 0 | Magic `0x33425646` |
| 1 | Version `5` |
| 2 | Operation: INFO=1, CONFIG=2, WRITE=3, READ=4, END=5, AUTH_CONFIG=6 |
| 3 | Host sequence, echoed in response |
| 4 | Logical sector, or CONFIG/AUTH_CONFIG write token `0x45524153` |
| 5 | Block count, or CONFIG/AUTH_CONFIG scratch capacity (1–8192 sectors) |
| 6 | Request payload bytes; WRITE only, exactly blocks × 512 |
| 7 | CONFIG/AUTH_CONFIG stack: one algorithm ID per byte, first layer in low byte |

Stack IDs: AES-256-XTS=1, Camellia-256-XTS=2. Zero whole stack means raw mode;
otherwise IDs must be contiguous, with no zero holes. Up to four layers. Other
operations require the algorithm field to be zero. INFO/END require zero args.
WRITE/READ accept 1–64 sectors within the configured scratch range starting at
physical LBA 0. Logical LBA supplies the XTS tweak.

Response: 104 bytes:

| Offset | Type | Field |
|---|---|---|
| 0, 4 | u32 | Magic, version |
| 8, 12 | u32 | Operation OR `0x80000000`, echoed sequence |
| 16, 20 | u32 | Status, response payload bytes |
| 24, 32, 40 | u64 | Crypto, SD, key-setup microseconds |
| 48 | u64 | Card capacity in sectors (zero before initialization) |
| 56, 60 | u32 | CPU Hz, requested SD Hz |
| 64, 72 | u64 | HMAC microseconds, metadata I/O microseconds |
| 80, 88 | u64 | Metadata sectors read, written |
| 96, 100 | u32 | HMAC backend (0 software, 1 Pico CPU-fed accelerator), self-check (1 passed) |

Only successful READ replies carry payload (blocks × 512 bytes). Error replies
have no payload. Status: 0=success, 1=invalid request, 2=not ready, 3=SD error,
4=crypto error, 5=sector integrity error. A transport/crypto failure clears the session and returns no data. Integrity
failure returns no data for the batch but leaves the session usable.

The header decoder rejects oversized/inconsistent payload lengths before USB
receives into the 32 KiB buffer. Invalid framing poisons the connection until
reconnect. Semantically invalid, correctly framed requests receive an error.
There is no HMAC on protocol framing: USB provides transport error detection and
the laptop compares final plaintext. This is a test protocol, not authentication.

## Ownership and completion

The USB core owns the shared buffer while receiving and transmitting. Queueing
a request transfers ownership to the worker; the response queue transfers it
back. A complete response is copied to the USB FIFO before the next request can
reuse the buffer. Partial frames never reach the engine. A disconnect discards
partial transport state; an in-flight worker operation completes before its
buffer is reused and a queued reset clears the old session.

CONFIG and AUTH_CONFIG replace any existing session. AUTH_CONFIG also formats
packed metadata and enables sector HMAC. The first ceil(N/15) physical sectors
then hold metadata, followed by N ciphertext sectors. This increases the
physical scratch footprint above the requested logical size.

CONFIG replaces any existing session. Fixed public 64-byte test keys use byte
`i + 71 * layer_index` modulo 256, data-key half first. This is reproducible
benchmark material, not a production derivation. Reconfiguration does not write
metadata or make previous scratch contents meaningful under a new stack.

WRITE encrypts every sector once per layer and issues one batched block-device
write. The block-device contract requires completed writes, including card busy
completion; the native SD adapter checks status before success. READ performs
one batched SD read then reverses the cipher stack. END syncs and clears keys.
There are no background write acknowledgments, old-payload reads, per-sector
nonce generation, persistent vault headers or write-readback verification.
Authenticated mode stores tags and state via the [storage module](../storage/README.md),
verifies ciphertext before decryption, and skips decryption for unset sectors.
It uses a distinct public integrity key (byte i = 0xd3 XOR i) and public volume
ID (byte i = 0x80+i), for benchmarking only.

See [board instructions](../../pico/benchmark/README.md) for builds and runs.

Protocol 5 adds backend identity and a startup self-check result. The engine runs
its selected HMAC backend against known/software reference results before the
first request. Failure stops operations before any SD work. The desktop runner
checks version/backend/self-check and logs them; it rejects older firmware.
The HMAC/tag bytes and storage layout are unchanged from protocol 4.

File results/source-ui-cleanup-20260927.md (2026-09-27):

# Source layout and scene-based UI refactor — 2026-09-27

Active first-party sources now live under `src/shared`, `src/pico` and `src/host`.
See [source guide](../src/README.md) and [UI guide](../src/shared/ui/README.md).

The UI now uses a static scene registry with entry, key and render callbacks;
menus keep labels and actions together. Credential workflows use a single named
flow state. Shared debounce logic is separate from Pico pin access, and TFT and
accelerated crypto sources live on the Pico side. No device was flashed or used.

## Validation

- Fresh pre-change desktop baseline: 38/38 tests passed with FIDO enabled.
- Refactored desktop build: 39/39 tests passed with FIDO enabled.
- ASan/UBSan: 39/39 passed (`ASAN_OPTIONS=detect_leaks=0`; no leak-check claim).
- FIDO-disabled desktop build: 28/28 passed.
- Final focused UI/component/FIDO-adapter reruns after readability edits: 3/3
  passed in both normal and sanitizer builds.
- Device ELF compiled/linked with UI + MSC + FIDO, and with UI + MSC without FIDO.
- Benchmark and minimal alive firmware ELF targets compiled/linked.
- All 30 offline preview fixtures (PBM pixels and generated gallery assets)
  matched the pre-refactor output exactly.
- Generated TinyUSB MSC driver tests passed with 4/16/32 KiB buffers; USB task
  budget test reproduced the original starvation and passed with the patched task.
- Active Markdown links and source references checked; `git diff --check` passed.

The Pico builds used `/home/adam/pico-sdk` and `-DPICO_NO_PICOTOOL=1`, matching the
existing local firmware build's compile/link configuration. UF2 conversion and
physical button/display/USB acceptance were not performed.

## Reproduction

From the repository root, with `PICO_SDK_PATH` pointing to the SDK:

```sh
cmake -S . -B build-check \
  -DFV_MBEDTLS_DIR="$PICO_SDK_PATH/lib/mbedtls" -DFV_ENABLE_FIDO_ENGINE=ON
cmake --build build-check -j4
ctest --test-dir build-check --output-on-failure

cmake -S src/pico/device -B build-device-check \
  -DPICO_SDK_PATH="$PICO_SDK_PATH" -DPICO_NO_PICOTOOL=1 \
  -DFV_DEVICE_UI=ON -DFV_USB_MSC=ON -DFV_USB_FIDO=ON -DFV_DEBUG_SCREEN=ON
cmake --build build-device-check -j4

python3 src/host/tools/ui_preview.py --output /tmp/fuse-vault-ui-preview
python3 src/host/tools/test_usb_pipeline_driver.py \
  --sdk "$PICO_SDK_PATH" --firmware-build build-device-check
python3 src/host/tools/test_usb_task_budget.py \
  --sdk "$PICO_SDK_PATH" --firmware-build build-device-check
```

Use new build directories for relocated Pico source entry points. Existing host
executables retain their names and remain at the build-directory root. Historical
reports and the V1 reference archive retain their historical source paths.

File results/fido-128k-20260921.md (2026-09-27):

# 128 KiB FIDO store expansion

The user requested increased capacity after board telemetry stabilized at
8.4 KiB heap reservation and 148 KiB uncommitted RAM with the 64 KiB image.

## Implementation

- Engine image increased to 131,072 bytes. The existing 1 MiB private SD region,
  USB geometry, engine wrapping key derivation and independent bank keys remain.
- Snapshot v2 uses 18 metadata sectors and 256 payload sectors per bank, plus
  the manifest. v1 reads retain the original 9/128-sector geometry.
- Authenticated legacy file lists are validated and relocated in RAM. Credential
  payloads remain byte-for-byte unchanged. Open performs no writes; the next
  commit writes v2 to the alternate bank. Invalid lists fail closed.
- Downgrade is unsupported: old firmware cannot read v2 and may select a stale
  surviving v1 bank. Do not use old firmware after saving expanded snapshots.
- Fixed RAM including stack reservations is about 427.6 KiB; the linker leaves
  92.4 KiB for the heap. At the user's previously observed 8.4 KiB reservation,
  about 84 KiB would remain uncommitted. New-build runtime usage is not measured.

## Measured desktop capacity

| Profile | 64 KiB | 128 KiB |
| --- | ---: | ---: |
| Same site, 100-character usernames, 4-byte user IDs | 44 | 103 |
| Same site, short usernames, 4-byte user IDs | 48 | 112 |
| Distinct sites, email/display name, 32-byte user IDs | 45 | 107 |
| Distinct sites, email/display name, 64-byte user IDs | 44 | 104 |

Each uses ES256 resident credentials and checks an existing signature after
full-store rejection and reopen. These are fixture capacities, not universal
guarantees. Nonresident SSH credentials do not consume a resident slot.

## Validation

- Full normal desktop suite: 37/37 passed.
- Legacy fixture generated by the previous engine: two resident credentials and
  one nonresident credential. Independent python-fido2/cryptography verification
  passed after expansion, discovery, new registration and reopen.
- 146 migration write/sync interruption cases and 702 expanded-snapshot fault
  cases passed, including dropped unsynchronized writes. USB/header boundaries
  remained unchanged. Authenticated malformed legacy lists are rejected.
- ARM FIDO/debug firmware built and UF2 generated. No device flashing,
  initialization, reset or real-account changes performed.
- Focused ASan/UBSan suite: 7/7 passed (`detect_leaks=0`; no leak-check claim).
  Covers adapter, store faults, migration, engine and encrypted client suites.
  Physical migration, memory/load measurements and power-fault acceptance remain
  board checks.

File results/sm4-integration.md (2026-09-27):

# SM4 integration validation

Validated 2026-09-26 on the current working tree, including the existing FIDO/UI
work. No device was flashed and no SD contents were changed.

- Release desktop build with FV_ENABLE_FIDO_ENGINE=ON: all 37 CTest suites pass.
- Debug build with address/undefined sanitizers: all 37 suites pass with
  ASAN_OPTIONS=detect_leaks=0 and UBSAN_OPTIONS=halt_on_error=1. LeakSanitizer is
  disabled for this environment. The final additional effective-key suffix
  checks also pass a targeted sanitizer rerun of the crypto suite.
- Published single-block and million-iteration SM4 answers pass. Full sectors
  match an independent OpenSSL SM4 + XTS reference at zero, ordinary, high and
  maximum LBAs. All 120 one-to-four-layer combinations match independent output.
- Independent Python/OpenSSL fixtures verify SM4-only and AES/SM4/Camellia/SM4
  VMK envelopes. Existing AES/Camellia fixture bytes are unchanged. A valid outer
  HMAC with a corrupt SM4 wrap fails without publishing any VMK bytes.
- Mixed-stack vault lifecycle tests cover creation, unlocking, I/O, credential
  changes and failures. FIDO snapshot lifecycle tests cover SM4-only and mixed
  stacks, including reopen and credential changes.
- Pico security firmware builds with UI, MSC and FIDO enabled. ELF and binary:
  build-pico-sm4/fuse_vault_security.elf and fuse_vault_security.bin.
  PICO_NO_PICOTOOL=1 follows the existing offline build configuration; no UF2
  was produced. Hardware execution and Pico throughput remain unmeasured.
- Linker symbols confirm sm4_encrypt at 0x2000174c (1790 bytes) and SM4_T at
  0x20002cf0 (1024 bytes), both in SRAM. These are symbol sizes, not a complete
  before/after RAM delta. The existing context union accommodates SM4 schedules.

Build commands:

```sh
cmake -S . -B build-sm4 -DCMAKE_BUILD_TYPE=Release \
  -DFV_MBEDTLS_DIR=/home/adam/pico-sdk/lib/mbedtls -DFV_ENABLE_FIDO_ENGINE=ON
cmake --build build-sm4 -j4
ctest --test-dir build-sm4 --output-on-failure -j4
cmake -S . -B build-sm4-sanitize -DCMAKE_BUILD_TYPE=Debug \
  -DFV_MBEDTLS_DIR=/home/adam/pico-sdk/lib/mbedtls \
  -DFV_ENABLE_FIDO_ENGINE=ON -DFV_SANITIZERS=ON
cmake --build build-sm4-sanitize -j4
ASAN_OPTIONS=detect_leaks=0 UBSAN_OPTIONS=halt_on_error=1 \
  ctest --test-dir build-sm4-sanitize --output-on-failure -j4
cmake -S firmware/security -B build-pico-sm4 \
  -DPICO_SDK_PATH=/home/adam/pico-sdk -DPICO_NO_PICOTOOL=1 \
  -DFV_DEVICE_UI=ON -DFV_USB_MSC=ON -DFV_USB_FIDO=ON -DCMAKE_BUILD_TYPE=Release
cmake --build build-pico-sm4 -j4
```

One desktop RAM benchmark run (MiB/s; public test keys, no I/O/authentication):

| Cipher | Encrypt | Decrypt |
| --- | ---: | ---: |
| AES-256-XTS | 187.32 | 187.69 |
| Camellia-256-XTS | 98.82 | 132.17 |
| SM4-128-XTS | 160.61 | 161.84 |
| AES → SM4 | 95.61 | 95.02 |

These host measurements do not predict Pico throughput.

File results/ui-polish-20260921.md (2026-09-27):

# First software UI polish pass — 2026-09-21

Implemented in the shared 160 × 80 device renderer:

- Back from passkey deletion returns to the same credential/text page. Back from
  passkey management, verification settings and destructive settings screens
  returns to the relevant settings row. Selecting Cancel follows the same route.
- Passkey labels scroll only through populated pages; a shorter site/account
  retains its last page while the other scrolls. Page counts are visible, deletion
  confirmation supports inspecting long labels, and each new credential starts
  on page one. Selection and stable credential IDs remain independent of paging.
- Settings shows position/total. Busy screens identify the operation in progress.
- FIDO credential entry labels Back as Cancel, matching its existing behavior.
  Normal pattern entry explains deletion and cancellation at empty input.
- Confirmation text fits the display and describes effects on files/passkeys;
  FIDO initialization also explains that it resets FIDO settings. Destruction
  retains an explicit setup-slot warning. Added missing parenthesis glyphs.
- Offline preview tool produces synthetic fixtures using the actual C renderer,
  without requiring a connected device. No real credentials are included.

Validation:

- Full desktop suite after navigation changes: 35/35 passed.
- After final rendering changes: UI and FIDO firmware-adapter tests 2/2 passed
  normally and 2/2 under ASan/UBSan. The focused sanitizer pass also covered USB
  storage during setup and FIDO USB scheduling (4/4 before final text-only edits).
  Leak detection disabled for the existing tracing limitation.
- Inspected the 30-state [contact sheet](ui-polish-20260921.png), then final changed
  screen images. Coverage includes home, setup, all credential methods, settings,
  approvals, passkey list/delete/empty/long labels, busy/error, lockout and rotation.
- Composite FIDO and FIDO-disabled device UI firmware builds passed.
- No hardware flashing, physical interaction or storage changes performed.

Artifact: `build-pico-fido/fuse_vault_security.uf2`.
SHA-256: `22bd5f635575a248bc3331431fa1296a87c034acf166fe0471a89e11fb0c5f95`.
ELF text 417,004 bytes; BSS 347,068 bytes; data 0.
The configured build disables automatic picotool outputs; explicitly converted
the final ELF with the documented picotool command so the UF2 is current.

Remaining: physical readability/button feel, richer success feedback and error
classification, and broader software/release work in the persistent polish plan.

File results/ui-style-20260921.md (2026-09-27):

# Unified UI and button conventions — 2026-09-21

Follow-up to the first behavioral polish pass. The user identified inconsistent
FIDO styling and requested conventional navigation with concise button hints.

FIDO request, verification, credential list/delete/empty views, destructive
confirmations, unlock-method and encryption menus, failure policy and error views
now share header/footer separators and highlighted choices. Repeated prose button
instructions are replaced by Back/Select icons with contextual action labels.
Long RP approval labels retain all five 25-character content rows; approval still
requires Select, and Back rejects. Destructive menus still default to Cancel.

Controls:

- Up/Down selects an item or credential.
- Left/Right changes the selected setting/cipher or pages credential text.
- Select enters a menu or acts on the highlighted item.
- Back steps out; at unlocked home it submits the existing lock operation.
- Normal credential entry retains its method-specific behavior. FIDO credential
  Back cancels verification, as before. Home Left/Right still rotates the display.

Failure policy now has Attempts, Action and Review rows; selecting a value row
advances focus, and selecting Review opens the existing confirmation. Cipher
removal is an explicit menu item rather than a hidden Left-button action. At least
one cipher layer is retained. No storage formats, credentials or USB locking
semantics changed; the home shortcut has the same eject-before-lock requirement.

Validation:

- Full desktop suite: 35/35 passed.
- UI and FIDO adapter ASan/UBSan: 2/2 passed, with leak detection disabled for the
  existing tracing limitation.
- Composite FIDO and FIDO-disabled firmware builds passed.
- Inspected [30 rendered screen states](ui-style-20260921.png). Generated with
  `python3 tools/ui_preview.py`, using the actual shared C renderer and synthetic
  data. Hardware readability/button feel remain untested.
- Added behavioral checks for Back locking only at home, no duplicate busy
  submission, selection versus editing, explicit cipher removal and directional
  input never approving a FIDO request.

Final UF2: `build-pico-fido/fuse_vault_security.uf2`, explicitly converted from
the final ELF. SHA-256:
`50c3df04f3d6937865d7dedd87af574ce38467f4bd2af0a7a0aefee194220a79`.
No hardware flashing or physical credential operations performed.

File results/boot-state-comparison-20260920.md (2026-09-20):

# Read-only BOOTSEL comparison — 2026-09-20

Working sample: 66ED2A91873CF67F.
Original failing sample: 317741A1459A6F94.

Sources: working-board-boot-state-complete-20260920.json and
original-board-boot-state-20260920.json. All four reads returned success on both.
The initial working-board snapshot had an unsupported wildcard selector; the
complete snapshot uses explicit row numbers and contains all 128 rows.

## Findings

- Raw OTP rows 0x0040–0x00bf (pages 1 and 2) are all zero and identical,
  including redundant copies, boot flags, critical configuration and signing hashes.
- Selected permanent locks match exactly: pages 0, 1, 2, 16–24, 59 and 60.
- Neither board has a flash partition table.
- Both report A4, QFN60, ROM gitrev 0xa8bfe860, 2 MiB flash, ARM default,
  secure boot disabled, and normal/secure debugging enabled.
- Installed images differ as expected: working sample has V2 startup-only;
  original has ALIVE built for pico2. Both report SDK 2.3.0 and valid ARM Secure
  image metadata without extra image security. Metadata is not a bytewise image
  verification. Chip IDs and per-boot random values naturally differ.

## Interpretation and limits

No evidence supports accidental programming of boot settings/signing keys or
changes to the selected OTP locks. The current measurements agree with earlier
application-level blank-page summaries. Application OTP contents, all other OTP
pages, flash-chip status/configuration, full flash contents and electrical state
were not compared. These results do not prove a physical defect or exclude every
persistent-state mechanism. Manual BOOTSEL entry does not preserve a diagnostic
record of the preceding failed cold start; zero current boot diagnostics are not
proof that the cold boot succeeded.

All commands were info, partition info, or otp get. No reset, reflash, OTP write,
SD command, provisioning or recovery was performed during collection.

## Normal restart after read-only comparison

User unplugged/reconnected the original sample without BOOTSEL. Elevated lsusb
showed neither ALIVE nor BOOTSEL; no serial/by-id port existed. The ALIVE probe
stopped at identity validation before sending any ping. Missing-USB behaviour
therefore persists after the read-only inspection. CPU execution state remains
unknown; this does not independently identify a hardware failure.

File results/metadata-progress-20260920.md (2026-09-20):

# Metadata initialization progress — 2026-09-20

Artifact: `build-pico-device-ui/v2_device_ui_progress.uf2`
SHA-256: `fa9fbbdd2d294c011b07db1cfa2957b04a7938d179fd4285bd3aea40c019b7a7`
UF2 payload ends at `0x10022000`, below the authority journal.

- Device UI creation uses 64-sector / 32 KiB zero-write batches, reusing the
  existing 32 KiB worker diagnostic buffer. Previously six sectors / 3 KiB.
- No disk-format change. Default portable formatter remains six-sector compatible.
- Worker publishes successful-sector counts through atomic fields. Core 0 draws
  a progress bar, percentage, MiB written/total, average KiB/s and elapsed seconds.
- Preparation and finalization have separate screen labels. 100% metadata written
  is not reported as successful vault creation until sync/headers/authority finish.
- 24 desktop tests pass, including buffered-format boundaries, write/sync failures
  and monotonic progress. ASan/UBSan suite 24/24 passes (leak detector disabled).
- Progress framebuffer visually inspected; ARM firmware builds successfully.
- No attached-board writes or firmware updates performed. Existing running format
  cannot acquire progress instrumentation without a subsequent firmware update.
- Raw four-bit 25 MHz ceiling is 12.5 MB/s before overhead; 3.66 GiB takes over
  five minutes even at that ceiling. Actual improved speed awaits board measurement.

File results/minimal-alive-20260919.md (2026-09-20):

# Minimal ALIVE firmware — 2026-09-19

- Release build passed with SDK 2.3.0 for fuse_vault / rp2350-arm-s.
- ELF size: text 31,468 bytes; data 0; BSS 2,640 (not total runtime RAM).
- UF2: 54784 bytes, 107 blocks.
- Payload bounds: 0x10000000..0x10006b00 (end exclusive).
- Every payload checked below the reserved journal at 0x101fe000.
- SHA256: 738b3995076729cbd4d228a3fd5cc1b90d32158e143837d1c4d79d3c99d04a5a.
- Symbol checks: no embedded XIP call, boot trace hook or core-1 launch.
- Host probe passed Python compilation and CLI-help checks.
- Hardware flash/handshake and cold-start validation pending.

See firmware/alive/README.md for reviewed documentation, exact scope and test order.
No firmware was flashed and no attached device state was changed during this build.

## First hardware test: post-flash PASS

User reported ready after flashing. USB enumerated as 2e8a:0009,
product Fuse Vault ALIVE, serial 317741A1459A6F94 (bus 5/address 101).
The host probe exited successfully:

```text
FV_ALIVE_V1 PONG 56707
FV_ALIVE_V1 AWAKE 57003
FV_ALIVE_V1 AWAKE 58003
PASS: ping answered and heartbeat uptime advanced
```

This confirms application execution, USB receive/transmit and advancing timer
uptime after flashing. Cold-start behaviour is not yet established. Only the
single-byte '?' ping was sent; no storage or OTP commands were issued.

## Second hardware test: cold-start handshake unavailable

After the user reported complete unplug/replug, elevated lsusb showed neither
2e8a:0009 ALIVE nor BOOTSEL. No serial/by-id directory existed; the probe refused
to open an unidentified device and sent no ping. Kernel log recorded the working
ALIVE device disconnecting at 11:31:28, then a UCSI error at 11:31:34, without a
new USB enumeration in the checked interval. This reproduces the post-flash /
cold-start difference with the minimal SDK USB application and fixed USB-C mux.
It does not establish whether the CPU reached main or whether power/USB routing
failed. Storage, crypto, core-1 launch, authority recovery and dynamic presence
mux logic are not required to reproduce the observed missing-USB outcome.

## Standard Pico 2 comparison prepared

Built the same heartbeat/ping loop with PICO_BOARD=pico2 and rp2350-arm-s in
build-pico2-alive. Vault GPIO setup is compiled out; stock Pico 2 linker layout
is used. Release build passed. picotool confirms pico2, SDK 2.3.0, ARM Secure,
image 0x10000000..0x10006a00. Disassembly confirms main enters stdio_init_all
without vault GPIO setup. Artifact: build-pico2-alive/pico2_alive.uf2.
SHA256: c996026c92a268621d60815cf19a44d8c538f0d413fb17769cf7ceea035b57e9.
Hardware validation pending; original custom-board UF2 retained unchanged.
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

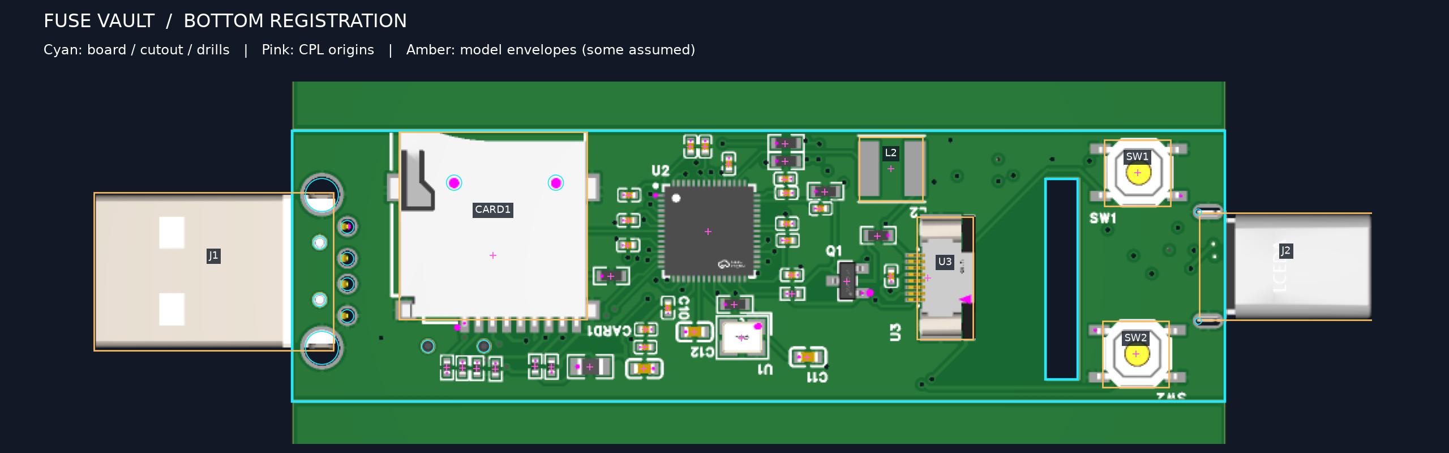
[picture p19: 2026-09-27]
CaseDesign/bottom_validation.png

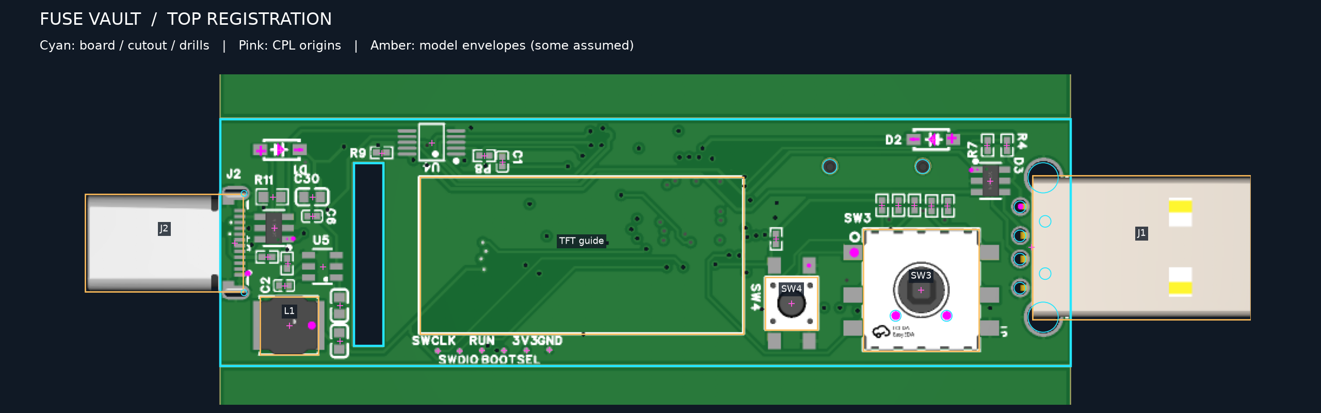
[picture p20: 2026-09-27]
CaseDesign/top_validation.png

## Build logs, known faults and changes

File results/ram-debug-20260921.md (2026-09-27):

# Debug RAM telemetry

Added RAM fields to the debug `SCREEN` response and a separate label in the GTK
viewer: total RAM, fixed allocation including stack reservations, current heap
reservation, peak reservation since boot, and uncommitted RAM. Old firmware
remains supported; unavailable telemetry is explicit. Disconnection clears the
displayed readings.

The debug-screen build wraps newlib `_sbrk` and observes the actual resulting
break, including optimistic partial growth. Two lock-free counters add 8 bytes
of persistent RAM. It does not inspect allocator lists across cores or expose
memory contents. Heap reservation includes reusable freed blocks, so this does
not measure live allocations or stack high-water usage. The viewer tooltip and
device UI documentation explain those distinctions.

Validation:

- FIDO/debug-screen firmware and no-debug-screen USB-storage firmware built.
- Linked `_sbrk_r` calls `__wrap__sbrk` in the FIDO ELF; the no-debug build has no
  RAM instrumentation symbols.
- `ram_debug` and `device_ui_and_capacity` CTests passed. The RAM test covers
  growth, a peak between samples, shrink, failure, and optimistic allocation.
- Viewer text formatting checked with synthetic values and absent telemetry.
- GTK visual check could not initialize the display in this environment; the
  actual viewer layout and board readings remain to be checked by the user.
- Regenerated `build-pico-fido/fuse_vault_security.uf2` from the rebuilt ELF.
  No flashing, device access or credential changes performed.

The 160×80, 1-bit framebuffer already exists (1,600 bytes). The V2 TFT still
needs initialization and transfer/pixel-conversion code; a line buffer is enough
to avoid a full colour framebuffer.

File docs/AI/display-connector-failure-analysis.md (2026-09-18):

# Revision-1 display connector investigation

Inspected 2026-09-14 after smoke at the screen flex-to-glass junction.

## Findings

The saved PCB project preserves the schematic's U3 pad-to-net assignments.
It records U3 moving from the top layer to the bottom layer, without changing
those assignments. The photographed screen insertion appears to mate screen
contact 8 with PCB pad 1, through screen contact 1 with PCB pad 8. This would
reverse the display supply. Confirm the physical mapping by unpowered
continuity measurements before any repair or further powered screen test.

Bottom-side placement is not intrinsically an electrical error. Nor does
moving a correctly defined component between layers swap its logical nets.
The important mismatch is the assumed one-to-one numbering between the generic
socket footprint and this particular screen flex when physically mated.
The history does not establish that the earlier top-side arrangement would
have mated correctly, or that the layer change alone introduced the mismatch.

## Project evidence

Source: `circuit board/fuse-vault.eprj2`, SHA-256
`6f312cc7bd64cec8153562116cc56b969398c859f1d0831f089b2fd661811e82`.
The project was opened read-only as SQLite and was not edited.

Its ordinary documents/components tables are empty, but its history records
can be decoded using the keys stored in the same project. All 149 history-data
rows authenticated and decompressed successfully. The read-only decoder used
AES-GCM, each row's hex UUID prefix as IV, its matching history key, then gzip
decompression. Format reference:
https://github.com/dao-genesis/Dao-PCB-Design-Agent/blob/main/lceda_bridge/cdp_studio/eprj2_codec.py

U3 is component `ec90907c7ad7b679` in PCB `44c27b65225b0f26`, linked to footprint
`b71b10e9dd10b0db` and device `ef96e276abfd6d99`. The device identifies C5373445,
SHOU HAN 0.5-8P CTSJ-H2.0 119, with top contacts.

Selected saved component records:

| History-data row | Ticket | Layer | Angle | Position (native coordinates) |
|---|---:|---|---:|---|
| 103 | 11172 | 1, top | 0 | 3786.055, -3875.2184 |
| 107 | 12214 | 1, top | 270 | 935, -345 |
| 108 | 12354 | 2, bottom | 90 | 955, -330 |
| 115 | 21967 | 2, bottom | 90 | 915, -455 |

Row 115 contains the latest U3 placement and pad-net records found in this
saved project. The pad assignments are unchanged across all six saved U3
placement records (rows 103, 107, 108, 109, 112, 115):

| PCB U3 pad | Net |
|---|---|
| 1 | LEDA |
| 2 | GND |
| 3 | TFT_RST |
| 4 | TFT_DC |
| 5 | TFT_MOSI |
| 6 | TFT_SCK |
| 7 | 3V3 |
| 8 | TFT_CS |
| 9, 10 | GND, mechanical anchors |

The stored footprint has pads 1 to 8 in increasing local X order, from
-68.9 to +68.9 at local Y=37.4. No reversal of those pad numbers was found.
Selected extracted records are preserved in
[u3-project-records.json](hardware-evidence/u3-project-records.json).
This is a focused connector audit, not a full PCB connectivity or DRC audit.

## Physical evidence and inference

The user's PCB screenshot has LEDA/R25 at one end of U3 and C13/3V3 toward the
other end. In the actual board photograph, R25 is above U3 and C13 below it;
the screen flex shows 8 above and 1 below. The screenshots must therefore be
compared with the board-side viewing reversal accounted for.

With the apparent mating order, screen ground (contact 2) meets PCB pad 7
(3V3), and screen VDD (contact 7) meets PCB pad 2 (GND). Thus VDD relative to
screen ground would be -3.3 V. This is a strong explanation for the reported
damage, but neither rail voltage nor continuity has yet been measured.

The screen datasheet identifies pins 1–8 as LEDA, GND, RESET, RS, SDA, SCL,
VDD, CS. Its VDD operating range is 2.5–3.3 V, with absolute minimum -0.3 V.
The supplier connector drawing identifies a top-contact socket. Having gold
facing its contacts establishes contact engagement, not matching pin numbers.

Source attachments inspected in this conversation:

- Screen: `/home/adam/Downloads/8248e3d07e4da27b04062054a843a030.pdf`.
- Connector: `/home/adam/Downloads/75add602f4fdc20b628ec2d91ab8ed8d.pdf`.
- Schematic: `/home/adam/Downloads/SCH_Schematic1_2026-09-06.pdf`.
- PCB screenshot: `/tmp/codex-clipboard-d2bd0a20-9e79-4db7-91dd-99883041e060.png`.
- Board photograph: `/tmp/codex-clipboard-c58f0310-bcbe-4de4-ab44-73511e9b4d4f.png`.

## Why nets did not catch it

The schematic models a generic connector with numbered terminals. It instructs
CAD to connect 3V3 to socket pad 7, which the saved PCB does. It does not model
which screen contact physically touches that terminal. Consequently a netlist
comparison can agree perfectly while a mated peripheral receives reverse power.
No claim is made here that a complete DRC run passed.

## Next verification and correction

With all power and the screen disconnected, measure continuity from U3's small
solder terminals to known board ground and 3V3. In the board photograph's
orientation, the second small terminal from the top is expected to be GND,
and the second from the bottom 3V3. Match each to the screen's numbered flex
contacts, rather than relying on an arbitrary left/right description.

If the reversed mating order is confirmed and the same socket and insertion
geometry are retained, the required PCB-pad mapping would be:
1=TFT_CS, 2=3V3, 3=TFT_SCK, 4=TFT_MOSI, 5=TFT_DC, 6=TFT_RST,
7=GND, 8=LEDA; mechanical anchors remain GND. This is a conditional design
mapping, not an instruction to power the existing hardware.

Existing boards may be repairable with a verified reversing adapter or suitable
connector rework. A replacement bottom-contact socket is not automatically a
drop-in fix: footprint, contact geometry, numbering and flex fit must all be
checked. Simply flipping the flex is not a validated repair. Revisions should
represent the screen-to-socket mapping explicitly in the schematic and include
a mating-orientation drawing. Validate repaired supply polarity/voltage before
connecting an undamaged screen; damaged screens cannot validate the repair.

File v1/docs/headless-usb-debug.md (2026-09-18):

# Testing revision-1 boards without a screen

Branch: `codex/headless-usb-debug`.

## Start here

1. Disconnect the physical screen. Its supply is directly wired to the PCB;
   disabling display firmware cannot make the reversed connector safe.
2. Hold BOOTSEL while connecting USB-C and copy
   `firmware/build-headless/fuse_vault.uf2` onto the boot drive.
3. Run from a terminal in the desktop session:

   ```sh
   python3 /home/adam/projects/fuse-vault/firmware/tools/usb_screen.py
   ```

4. The viewer finds the debug firmware automatically. Press the physical
   D-pad, OK and Back buttons; the window mirrors the real firmware's 160x80
   framebuffer at 4x size. There are no simulated button presses or simulated
   storage in this viewer.
5. For storage tests, use a disposable SD card. The normal setup flow can erase
   it and create permanent device roots in OTP. The headless option does not
   disable root creation, the attempt limit, or destructive lockout. Use test
   credentials and data. No secure-boot/page-lock provisioning is added here.

The viewer uses Python 3 and GTK 3/PyGObject, already available in this Linux
workspace. Run it in a graphical desktop session. On another Debian/Ubuntu
machine the packages are `python3-gi` and `gir1.2-gtk-3.0`. PySerial is not needed.
Use `--port /dev/ttyACM0` to override automatic discovery if necessary.
If opening the serial device reports permission denied, check that the desktop
user has access to that device (commonly membership in `dialout`, followed by
logging out and back in); do not run the entire viewer as root.

## What this build changes

- Development-only USB CDC serial interface is available before unlocking and
  remains connected through lock, eject and application faults.
- MSC shares the same USB configuration, with no medium available until the
  normal authenticated storage-mode attachment. Lock/eject removes that medium
  and follows the existing key-clearing runtime path.
- Physical display SPI is disabled; display signal pins are inputs and the
  backlight control is held off. The normal view renderer supplies USB images.
- Real board buttons, SD, cryptography, OTP and flash-journal code still run.
- VID/PID is development identity `cafe:4013`, product `Fuse Vault SCREEN DEBUG`.
- FIDO2 and release builds are rejected when the headless option is enabled.
- Connector presence/conflict checks remain active. A connector change or
  conflict disables the mux; power-cycle with one connector to recover.

This profile deliberately exposes whatever the device screen displays,
including secret-entry/review screens. It is not a production security profile.
It does not expose arbitrary memory, keys, or host control commands.

## Reading the diagnostics

The viewer displays the app state, framebuffer sequence, uptime, physical
button bitmask and initial boot checks. Boot checks cover input initialization,
flash interface, OTP interface, SD driver, USB, connector routing and composed
services. An SD-driver OK result does not establish that a card is present or
readable. Boot recovery is reported separately as ready, waiting for media,
or failed. These checks are an initial snapshot, not continuous health tests.

KDF and SD operations still run synchronously. The image may pause during
those operations; the viewer reports that it is waiting. This first version
is a screen mirror and boot diagnostic, not a trace of every internal operation.
If initialization hangs before the USB service loop, no frame will arrive.

No serial device at all: confirm the headless UF2 was flashed, connect USB-C
only, and check OS USB enumeration. A failed connector-presence check can
prevent the application from routing USB even though ROM BOOTSEL works.

## Rebuilding

```sh
cmake -S firmware -B firmware/build-headless \
  -DPICO_SDK_PATH=/home/adam/pico-sdk \
  -Dpicotool_DIR=/home/adam/projects/fuse-vault/firmware/build/_deps/picotool \
  -DFUSE_VAULT_HEADLESS_DEBUG=ON -DCMAKE_BUILD_TYPE=RelWithDebInfo
cmake --build firmware/build-headless -j4
```

The picotool argument reuses the existing local tool on this machine, avoiding
another download; omit or replace it on other machines. The normal build folder
and its configuration remain separate.

## Wire format and verification

Host sends ASCII `f` to request a snapshot. Firmware returns eight little-endian
32-bit words: magic bytes `FVD1`, payload length 25600, frame sequence, app-state
ID, physical button mask, boot-check bitmask, boot recovery, uptime milliseconds.
The payload is 160x80 RGB565 pixels, little-endian, row-major. Requests during
transmission are discarded. A separate snapshot buffer prevents tearing while
USB applies backpressure. Disconnect cancels the current transfer. The viewer
requests up to twenty frames per second, waiting for each response.
Actual rate depends on USB and any synchronous SD/crypto work. The bench
firmware services USB without the normal 1 ms main-loop sleep; the viewer
drains available serial chunks every 5 ms.

Host CTests cover partial USB writes, zero transmit capacity, coherent snapshots
while the displayed frame changes, disconnect/reconnect, physical display pin
safety, and MSC lock/eject/reattach with USB remaining initialized. Python tests
cover fragmented/coalesced reads, invalid-length resynchronization and RGB565
conversion:

```sh
ctest --test-dir firmware/build-host --output-on-failure
python3 firmware/tools/usb_screen_tests.py
```

At implementation time: 35 host checks and 4 viewer protocol tests pass; both
normal and headless RP2354 builds link. Actual USB enumeration, GTK window
rendering and end-to-end board operation still require the user's desktop/board.

## Storage performance investigation (2026-09-14)

The first board showed about 24 KiB/s completed writes, with FAT32 creation
lasting 15 minutes 35 seconds. This is not an accepted performance baseline.
The current headless build uses RelWithDebInfo (-O2 with debug symbols), rather
than Debug (-Og). This is compiler optimisation, not a production release or
an alteration of encryption, sector layout, or durability guarantees.

The original profiling request `g` returns five counters. This preserves the FVD1
header but increases payload length from 25600 to 25680. After the pixels,
five records each contain four little-endian uint32 words: operation count,
total microseconds low word, total microseconds high word, maximum microseconds.
Categories are SD sector read, SD sector write, SD sync, encrypted sector read,
and encrypted sector write. The totals include failed operations. Counters
start at boot and are not reset by locking. Vault timings include their nested
SD operations; do not add all category totals together. Other vault time
includes cryptography, validation, memory work and instrumentation overhead.
The on-card format is unchanged. Old viewers can still request `f` without the
extension. The updated viewer sends `hg`: new firmware accepts `h` and
ignores the following `g` while transmitting; older profiling firmware ignores
`h` and accepts `g`. Screen-only firmware falls back to `f`, with periodic
profiling retries. A timeout never disables previously confirmed metrics;
timings older than two seconds are labelled stale.

Request `h` returns 13 counters (25808 payload bytes). The first five retain
their original order, followed by: select existing copies, read-back
verification, record nonce KMAC, layer IV KMAC, AES-XTS including key setup,
ChaCha20, Ascon encrypt, Ascon decrypt. Selection and verification include their
nested SD and crypto operations; do not sum them with those components. AES
and ChaCha timings combine encryption and decryption calls. Counts show how
many times each layer runs, rather than assuming the selected preset. Timing
rows scroll in the viewer.

For a useful comparison, capture counters after unlock, copy one small test
file (for example 1 MiB) and wait for the host to finish writing, then capture
again. Capture before and after the slow delete separately. Differences in
count and total time isolate each workload; the displayed means are cumulative
since boot. This build does not automatically run a benchmark or alter data.

Finish or safely stop the current host operation before reflashing. Then close
and relaunch the updated viewer, unlock the existing vault, and use normal
small file operations. Capture the timing panel after slow operations. This
identifies whether physical card commands or work above the SD layer dominate
before changing buffering, transport or cryptography. No automatic disk writes,
benchmarks, formatting or reflashing are performed by the viewer.

The SD transfer implementation currently configures two DMA channels even for
single-byte status polling; sector payloads are already transferred in bulk.
That is a candidate optimisation, not yet a measured root cause or changed
transport. This performance build adds measurements rather than weakening
read-back verification or copy-on-write recovery.

### Prepared KMAC optimisation

The storage nonce and layer-IV paths now prepare the fixed KMAC prefix and
key state once per unlocked session. Each computation copies that state before
absorbing the original per-record message and output length. For these short
messages this reduces three Keccak permutations to one. It does not change
keys, nonce inputs, ciphertext format, authentication, recovery or read-back
verification. Prepared state is key-equivalent and lives inside the encrypted
block/pipeline owners, whose existing lock/fault clearing erases it.

The original one-shot implementation remains in use for other KMAC callers
and as the differential test reference. Tests cover 1,728 combinations of
key/customization, message and output lengths, including rate boundaries,
repeated use without mutation, invalid initialization, erasure, and the
existing encrypted-record golden values and interrupted-write recovery tests.
Device speedup has not yet been measured. Compare record-nonce and layer-IV
means against the previous 1.33/1.31 ms and total vault writes against 19.90 ms
using the same scheme/card and a similar workload. No SD transport changes
are included in this comparison.

### Further performance build

`firmware/build-headless/fuse_vault-performance.uf2` includes prepared KMAC,
constant rho/pi rotations in Keccak (same permutation/round count), and a
16-entry SD CRC lookup (same polynomial and checking). The KMAC-only image
remains at `firmware/build-headless/fuse_vault-kmac-cache.uf2` for comparison.
The Keccak change was checked against the pre-change implementation across
the 1,728-case corpus; its concatenated output SHA-256 is
`fe57451d323042359b48a5e9f128c6e7e3f255fb3b2e5802e500365b9c1dceb6`.
SD protocol tests use an independent bitwise CRC reference and cover corrupted
reads, command status, transport failure and recovery. The 8 MHz SD clock,
DMA/PIO transport and write ordering are unchanged.

After obtaining a full frame, the viewer sends `ihg`. Firmware handling `i`
returns only the 208 timing bytes when the last transmitted frame sequence
still matches, or a full frame plus timings when it changes. The same FVD1
header carries fresh state, buttons and uptime. Reconnect invalidates the
firmware's frame history, and the viewer starts each connection with `hg` to
force a full frame even if the device did not observe the disconnect. Older
firmware ignores unsupported request letters. Legacy `f`, `g`, and `h`
responses retain their formats.

An unchanged screen now uses 240 rather than 25,840 bytes per response:
about 4.8 KB/s instead of 517 KB/s at 20 responses/second. These are protocol
traffic calculations, not measured storage throughput. New firmware and a
restarted updated viewer are both required for the reduction. Host tests
exercise short writes, unchanged/changed frames, and disconnect recovery;
viewer tests cover fragmented and coalesced full/timings-only packets.

No measured device speedup or unlock-time improvement is claimed until the
hardware is retested. Password KDF iteration counts are unchanged. Compare
with the same card and Scheme 3, and retain the before/after timing panels.

### Native four-bit SD bench build

Build separately to preserve the SPI comparison images:

```sh
cmake -S firmware -B firmware/build-native-sd \
  -DPICO_SDK_PATH=/home/adam/pico-sdk \
  -Dpicotool_DIR=/home/adam/projects/fuse-vault/firmware/build/_deps/picotool \
  -DFUSE_VAULT_HEADLESS_DEBUG=ON -DFUSE_VAULT_SD_NATIVE=ON \
  -DCMAKE_BUILD_TYPE=RelWithDebInfo
cmake --build firmware/build-native-sd -j4
```

This selects native four-bit data at 25 MHz and multi-sector commands, using
PIO1 and two DMA channels. It retains the encrypted on-card format, KMAC
optimisations, authenticated read-back and synchronous write completion. It
supports sector-addressed SDHC/SDXC cards; smaller byte-addressed SDSC cards
are rejected. Production builds reject the native option until validated.

Finish file operations and eject before flashing. **Fully unplug all USB
power after flashing, then reconnect:** the card must leave the old SPI mode
through a power cycle. No format or vault reprovisioning is required. Restart
the viewer; its status line should show `4-bit SD / 25 MHz`. Boot flag bit 7
identifies the native backend. With this flag, the SD counters are labelled
read/write **request**, not sector: a request can contain multiple sectors.
The existing vault-sector timing categories remain comparable across builds.

Test reading an existing file before copying a new small test file. Capture
vault timings before host file operations and after copy/eject. Successful
builds and mock tests do not validate PIO electrical timing on the actual card.
The SPI performance and KMAC-only UF2s remain available for recovery/comparison.

No change to CPU-core allocation is included. This build isolates the larger
transport change so measured gains and any card/transport errors are attributable.

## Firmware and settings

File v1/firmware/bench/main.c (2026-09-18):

/* Standalone, public test keys, no OTP/provisioning or vault access.
 * SD writes occur ONLY after the explicit ERASE-SD command. */
#include "fuse_vault/rp2354_sd.h"
#include "fuse_vault/rp2354_connector.h"
#include "fuse_vault/rp2354_usb_msc.h"
#include "fuse_vault/crypto_pipeline.h"
#include "crypto_aead.h"
#include "pico/stdlib.h"
#include "pico/unique_id.h"
#if !FUSE_VAULT_BASELINE_BENCH
#include "pico/bootrom.h"
#include "hardware/exception.h"
#else
#include "fuse_vault/baseline_bench.h"
#endif
#include "hardware/clocks.h"
#include "tusb.h"
#include <stdio.h>
#include <string.h>

#if FUSE_VAULT_BASELINE_BENCH
static fv_rp2354_sd_t *bench_sd;
#define sd (*bench_sd)
static void (*bench_service)(void);
static bool requested, active;
#else
static fv_rp2354_sd_t sd;
static fv_connector_safety_t connector;
static fv_rp2354_connector_t connector_context;
#endif
static uint8_t ram_disk[128 * 1024];
static uint8_t buffer[16 * 1024] __attribute__((aligned(4)));
static uint8_t check[16 * 1024] __attribute__((aligned(4)));
static bool ram_attached;
static bool sd_attempted;
#if !FUSE_VAULT_BASELINE_BENCH
/* Survives the software return to ROM; contains only public startup state.
 * Read its ELF symbol address with picotool save after automatic fallback. */
volatile uint32_t bench_boot_trace[8]
    __attribute__((section(".uninitialized_data"), aligned(65536)));

static void boot_fallback(uint32_t reason) {
    bench_boot_trace[2] = reason;
    bench_boot_trace[3] = gpio_get_all();
    bench_boot_trace[4] = (uint32_t)time_us_64();
    /* ROM reboot is not a promise to reset our external mux's GPIOs. Release
     * SEL and OE# to the board's physical pull-downs (USB-C ROM default), after
     * disabling the mux while changing selection. Bench wiring is USB-C only. */
    fv_connector_safety_disable(&connector);
    gpio_set_dir(FUSE_VAULT_USB_SELECT_PIN, GPIO_IN);
    gpio_disable_pulls(FUSE_VAULT_USB_SELECT_PIN);
    gpio_set_dir(FUSE_VAULT_USB_OUTPUT_ENABLE_PIN, GPIO_IN);
    gpio_disable_pulls(FUSE_VAULT_USB_OUTPUT_ENABLE_PIN);
    reset_usb_boot(0, 0);
}
static int64_t boot_timeout(alarm_id_t id, void *context) {
    (void)id; (void)context;
    if (bench_boot_trace[1] != 5) boot_fallback(1);
    return 0;
}
static void boot_hardfault(void) {
    bench_boot_trace[5] = *(volatile uint32_t *)UINT32_C(0xe000ed28); /* CFSR */
    bench_boot_trace[6] = *(volatile uint32_t *)UINT32_C(0xe000ed2c); /* HFSR */
    boot_fallback(2);
}
#endif

static void service(void) {
#if FUSE_VAULT_BASELINE_BENCH
    if (bench_service) bench_service();
#else
    if (!fv_connector_safety_poll(&connector)) return;
    fv_rp2354_usb_msc_task();
#endif
}
static void reply(const char *line) {
    size_t offset = 0, n = strlen(line);
    uint64_t deadline = time_us_64() + 2000000;
    while (offset < n && time_us_64() < deadline) {
        service();
        if (!tud_cdc_connected()) return;
        offset += tud_cdc_write(line + offset, (uint32_t)(n - offset));
        tud_cdc_write_flush();
    }
}
static void result(const char *name, unsigned batch, uint64_t bytes,
                   uint64_t us, bool ok) {
    char line[240];
    snprintf(line, sizeof(line),
        "{\"test\":\"%s\",\"batch_bytes\":%u,\"bytes\":%llu,\"us\":%llu,\"ok\":%s}\n",
        name, batch, (unsigned long long)bytes, (unsigned long long)us,
        ok ? "true" : "false");
    reply(line);
}
static void info(void) {
    char serial[2 * PICO_UNIQUE_BOARD_ID_SIZE_BYTES + 1], line[320];
    pico_get_unique_board_id_string(serial, sizeof(serial));
    snprintf(line, sizeof(line),
        "{\"bench\":1,\"board\":\"%s\",\"cpu_hz\":%lu,\"sd_sectors\":%llu,"
        "\"sd_bus\":\"4-bit/25MHz\",\"ram_bytes\":%u,\"msc_buffer\":%u,"
        "\"build\":\"%s %s\"}\n", serial, (unsigned long)clock_get_hz(clk_sys),
        (unsigned long long)(sd_attempted && sd.interface.ops
            ? sd.interface.ops->block_count(&sd.interface) : 0),
        (unsigned)sizeof(ram_disk), CFG_TUD_MSC_EP_BUFSIZE, __DATE__, __TIME__);
    reply(line);
    reply(sd_attempted ? "{\"sd_initialization_attempted\":true}\n"
                       : "{\"sd_initialization_attempted\":false}\n");
#if FUSE_VAULT_BENCH_FIXED_USB_C
    uint32_t pins[20];
    fv_rp2354_connector_diagnostic_snapshot(pins);
    snprintf(line, sizeof(line),
        "{\"fixed_usb_c\":true,\"presence_samples\":%lu,\"presence_changes\":%lu,\"last_pattern\":%lu}\n",
        (unsigned long)pins[0], (unsigned long)pins[1], (unsigned long)pins[2]);
    reply(line);
    for (unsigned i = 0; i < 16; ++i) {
        if (!pins[4+i]) continue;
        snprintf(line, sizeof(line), "{\"presence_pattern\":%u,\"samples\":%lu}\n",
            i, (unsigned long)pins[4+i]);
        reply(line);
    }
#endif
}

static fv_block_result_t ram_read(fv_block_device_t *d, uint64_t first,
                                uint32_t count, uint8_t *out) {
    (void)d;
    if (!out || first >= 256 || !count || count > 256 - first)
        return FV_BLOCK_ERROR_OUT_OF_RANGE;
    memcpy(out, ram_disk + first * 512, count * 512);
    return FV_BLOCK_OK;
}
static fv_block_result_t ram_write(fv_block_device_t *d, uint64_t first,
                                 uint32_t count, const uint8_t *in) {
    (void)d;
    if (!in || first >= 256 || !count || count > 256 - first)
        return FV_BLOCK_ERROR_OUT_OF_RANGE;
    memcpy(ram_disk + first * 512, in, count * 512);
    return FV_BLOCK_OK;
}
static fv_block_result_t ram_sync(fv_block_device_t *d) {(void)d; return FV_BLOCK_OK;}
static uint64_t ram_count(const fv_block_device_t *d) {(void)d; return 256;}
static bool ram_present(const fv_block_device_t *d) {(void)d; return true;}
static const fv_block_device_ops_t ram_ops = {ram_read, ram_write, ram_sync, ram_count, ram_present};
static fv_block_device_t ram = {.ops = &ram_ops};

static void pattern(uint32_t first, unsigned count) {
    for (unsigned s = 0; s < count; ++s) {
        uint32_t state = (first+s) ^ UINT32_C(0xa5f03127);
        for (unsigned j = 0; j < 512; ++j) {
            state ^= state << 13; state ^= state >> 17; state ^= state << 5;
            buffer[s * 512 + j] = (uint8_t)state;
        }
    }
}
static void sd_test(bool write) {
    /* Each pass uses the first 4 MiB. Write pass destroys partition/vault headers. */
    const unsigned batches[] = {1, 8, 32};
    if (!sd_attempted || !sd.interface.ops ||
        sd.interface.ops->block_count(&sd.interface) < 8192) {
        reply("{\"error\":\"SD missing or smaller than 4 MiB\"}\n"); return;
    }
    for (unsigned b = 0; b < 3; ++b) {
        unsigned n = batches[b];
        uint64_t elapsed = 0, bytes = 0;
        bool ok = true;
        for (uint32_t first = 0; first < 8192; first += n) {
            if (write) pattern(first, n);
            uint64_t start = time_us_64();
            fv_block_result_t r = write
                ? sd.interface.ops->write(&sd.interface, first, n, buffer)
                : sd.interface.ops->read(&sd.interface, first, n, buffer);
            elapsed += time_us_64() - start;
            if (r != FV_BLOCK_OK) {ok = false; break;}
            bytes += n * 512;
            service();
        }
        if (write && ok) {
            uint64_t start = time_us_64();
            ok = sd.interface.ops->sync(&sd.interface) == FV_BLOCK_OK;
            elapsed += time_us_64() - start;
        }
        result(write ? "sd_write" : "sd_read", n*512, bytes, elapsed, ok);
        if (!ok) return;
        /* Verification is separate and excluded from write timing. */
        if (write) {
            uint64_t start = time_us_64();
            bytes = 0;
            for (uint32_t first = 0; first < 8192; first += 32) {
                pattern(first, 32);
                if (sd.interface.ops->read(&sd.interface, first, 32, check) != FV_BLOCK_OK ||
                    memcmp(buffer, check, sizeof(buffer))) {ok = false; break;}
                bytes += sizeof(buffer);
                service();
            }
            result("sd_verify", n*512, bytes, time_us_64()-start, ok);
            if (!ok) return;
        }
    }
}
static void crypto_test(void) {
    uint8_t key[16] = {1}, nonce[16] = {0}, aad[88] = {0};
    uint8_t plain[512] = {0}, cipher[528], decoded[512];
    uint64_t enc = 0, dec = 0;
    bool ok = true;
    unsigned completed = 0;
    for (unsigned i = 0; i < 2048; ++i) {
        memcpy(nonce, &i, sizeof(i));
        unsigned long long length = 0;
        uint64_t t = time_us_64();
        int r = crypto_aead_encrypt(cipher, &length, plain, 512, aad, sizeof(aad), NULL, nonce, key);
        enc += time_us_64()-t;
        if (r || length != sizeof(cipher)) {ok = false; break;}
        t = time_us_64();
        r = crypto_aead_decrypt(decoded, &length, NULL, cipher, sizeof(cipher), aad, sizeof(aad), nonce, key);
        dec += time_us_64()-t;
        if (r || length != 512 || memcmp(plain, decoded, 512)) {ok = false; break;}
        ++completed;
        service();
    }
    result("ascon_encrypt_88byte_aad", 512, completed*512u, enc, ok);
    result("ascon_decrypt_88byte_aad", 512, completed*512u, dec, ok);
    fv_volume_master_key_t vmk = {.bytes = {1}};
    uint8_t vault[16] = {1}, epoch[16] = {2};
    for (size_t preset = 0; preset < fv_crypto_stack_preset_count(); ++preset) {
        fv_crypto_pipeline_t pipeline;
        fv_encryption_stack_descriptor_t stack;
        ok = fv_crypto_stack_preset(preset, &stack) &&
             fv_crypto_pipeline_init(&pipeline, &stack, &vmk, vault);
        enc = dec = completed = 0;
        for (unsigned i = 0; ok && i < 1024; ++i) {
            memset(decoded, 0, sizeof(decoded));
            uint64_t t = time_us_64();
            ok = fv_crypto_pipeline_encrypt_block(&pipeline, i, 1, epoch, i+1, decoded);
            enc += time_us_64()-t;
            if (!ok) break;
            t = time_us_64();
            ok = fv_crypto_pipeline_decrypt_block(&pipeline, i, 1, epoch, i+1, decoded);
            dec += time_us_64()-t;
            ok = ok && memcmp(plain, decoded, 512) == 0;
            if (ok) ++completed;
            service();
        }
        char name[64];
        snprintf(name, sizeof(name), "pipeline_preset_%u_encrypt", (unsigned)preset);
        result(name, 512, completed*512u, enc, ok);
        snprintf(name, sizeof(name), "pipeline_preset_%u_decrypt", (unsigned)preset);
        result(name, 512, completed*512u, dec, ok);
        fv_crypto_pipeline_clear(&pipeline);
    }
}
static void command(const char *cmd) {
#if FUSE_VAULT_BASELINE_BENCH
    if (!strcmp(cmd, "B")) {
        reply("{\"bench_mode\":true,\"startup\":\"existing_headless\"}\n{\"done\":true}\n");
        return;
    }
#endif
    if (ram_attached && strcmp(cmd, "INFO")) {
        reply("{\"error\":\"Power-cycle before another baseline; RAM disk is attached\"}\n{\"done\":true}\n");
        return;
    }
    if (!strcmp(cmd, "INFO")) info();
    else if (!strcmp(cmd, "INIT-SD")) {
        reply("{\"stage\":\"initializing_sd\"}\n");
        /* USB and INFO must work even if the card driver cannot initialize. */
        if (!sd_attempted) {
            sd_attempted = true;
            fv_rp2354_sd_init(&sd);
        }
        reply(sd.interface.ops && sd.interface.ops->is_present(&sd.interface)
            ? "{\"sd_ready\":true}\n" : "{\"error\":\"SD initialization failed\"}\n");
    }
    else if (!strcmp(cmd, "READ-SD")) sd_test(false);
    else if (!strcmp(cmd, "ERASE-SD")) sd_test(true);
    else if (!strcmp(cmd, "CRYPTO")) crypto_test();
    else if (!strcmp(cmd, "RAM-USB")) {
        ram_attached = fv_rp2354_usb_msc_attach(&ram);
        reply(ram_attached ? "{\"ram_attached\":true}\n" : "{\"error\":\"RAM attach failed\"}\n");
    } else reply("{\"error\":\"Unknown command\"}\n");
    reply("{\"done\":true}\n");
}
static void process_commands(void) {
    static char line[40];
    static unsigned used;
    static bool overflow;
    while (tud_cdc_available()) {
        char c; tud_cdc_read(&c, 1);
        if (c == '\n') {
            line[used] = 0;
            if (used && !overflow) command(line);
            else if (overflow) reply("{\"error\":\"Command too long\",\"done\":true}\n");
            used = 0; overflow = false;
        } else if (c != '\r') {
            if (used < sizeof(line)-1) line[used++] = c;
            else overflow = true;
        }
    }
}
#if FUSE_VAULT_BASELINE_BENCH
void fv_baseline_bench_request(void) { requested = true; }
bool fv_baseline_bench_poll(fv_rp2354_sd_t *raw, bool allowed,
                            void (*service_fn)(void)) {
    if (requested) {
        requested = false;
        bench_service = service_fn;
        if (!allowed) {
            reply("{\"error\":\"Lock the vault before entering bench mode\"}\n{\"done\":true}\n");
            return false;
        }
        bench_sd = raw;
        sd_attempted = true; /* Existing product startup already initialized it. */
        active = true;
        reply("{\"bench_mode\":true,\"startup\":\"existing_headless\"}\n{\"done\":true}\n");
    }
    if (!active) return false;
    service();
    if (fv_rp2354_usb_msc_take_eject_request()) {
        fv_rp2354_usb_msc_detach(); ram_attached = false;
    }
    process_commands();
    return true;
}
#else
int main(void) {
    for (unsigned i = 0; i < 8; ++i) bench_boot_trace[i] = 0;
    bench_boot_trace[0] = UINT32_C(0x46564254);
    bench_boot_trace[1] = 1;
    exception_set_exclusive_handler(HARDFAULT_EXCEPTION, boot_hardfault);
    add_alarm_in_ms(10000, boot_timeout, NULL, true);
    fv_rp2354_connector_init(&connector_context);
    bench_boot_trace[1] = 2;
    /* Presence GPIOs must agree and identify one connector. Retry with the mux
     * disabled while power/pins settle; never bypass conflict checks. */
    while (!fv_connector_safety_init(&connector, &fv_rp2354_connector_ops,
                                    &connector_context, NULL, NULL) ||
           !fv_connector_safety_route(&connector)) sleep_ms(10);
    bench_boot_trace[1] = 3;
    if (!fv_rp2354_usb_msc_init()) boot_fallback(3);
    bench_boot_trace[1] = 4;
    for (;;) {
        service();
        if (tud_mounted()) bench_boot_trace[1] = 5;
        if (fv_rp2354_usb_msc_take_eject_request()) {
            fv_rp2354_usb_msc_detach(); ram_attached = false;
        }
        process_commands();
    }
}
#endif

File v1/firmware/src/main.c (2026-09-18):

#include "fuse_vault/diagnostics.h"
#if FUSE_VAULT_BASELINE_BENCH
#include "fuse_vault/baseline_bench.h"
#endif
#include "fuse_vault/app.h"
#include "fuse_vault/boot_recovery.h"
#include "fuse_vault/device_roots.h"
#include "fuse_vault/device_runtime.h"
#include "fuse_vault/device_services.h"
#include "fuse_vault/display.h"
#include "fuse_vault/input.h"
#include "fuse_vault/fido_store.h"
#include "fuse_vault/fido_verification.h"
#include "fuse_vault/peripheral_safety.h"
#include "fuse_vault/rp2354_connector.h"
#include "fuse_vault/rp2354_input.h"
#include "fuse_vault/rp2354_display.h"
#include "fuse_vault/rp2354_otp.h"
#include "fuse_vault/rp2354_random.h"
#include "fuse_vault/rp2354_sd.h"
#include "fuse_vault/rp2354_security_flash.h"
#include "fuse_vault/rp2354_usb_msc.h"

#include "fuse_vault/usb_debug_display.h"

#include "pico/stdlib.h"
#include "pico/unique_id.h"

#include <stdbool.h>
#include <stddef.h>
#include <stdint.h>
#include <string.h>

static fv_app_t app;
static fv_device_roots_storage_t roots_storage;
static fv_journal_flash_t security_flash;
static fv_rp2354_sd_t sd;
static fv_rp2354_connector_t connector_context;
static fv_connector_safety_t connector;
static fv_platform_services_t services;
static fv_device_services_context_t services_context;
static fv_device_runtime_t runtime;
static fv_input_controller_t input_controller;
static fv_display_t display;
#if !FUSE_VAULT_HEADLESS_DEBUG
static fv_rp2354_display_t display_context;
#endif
static bool runtime_ready;
static bool display_ready;
static bool connector_ready;

#if FUSE_VAULT_ENABLE_FIDO2
static fv_fido_store_t fido_store;
static fv_fido_verification_t fido_verification;
static bool fido_running, fido_fault, fido_reunlock;
static uint8_t fido_keepalive_status = 1;

static uint32_t fido_millis(void *context) {
    (void)context; return to_ms_since_boot(get_absolute_time());
}
static bool fido_safe(void *context) {
    (void)context;
    fv_rp2354_sd_poll(&sd);
    if (!runtime.authentication.vmk_valid || !app.session_unlocked ||
        !display_ready || !connector_ready ||
        !sd.interface.ops->is_present(&sd.interface) ||
        !fv_connector_safety_poll(&connector)) {
        fido_fault = true; return false;
    }
    if (fido_running && !fv_rp2354_usb_fido_poll(fido_millis(NULL), fido_keepalive_status)) return false;
    return true;
}
static void fido_presence_event(void *context, fv_event_t event) {
    int *result = context;
    if (event == FV_EVENT_SELECT) *result = 0;
    if (event == FV_EVENT_BACK) *result = 2;
}
static int fido_presence(void *context) {
    (void)context;
    fv_input_controller_t approval;
    fv_input_timing_t timing = {FV_INPUT_DEFAULT_DEBOUNCE_MS,
        FV_INPUT_DEFAULT_REPEAT_DELAY_MS, FV_INPUT_DEFAULT_REPEAT_INTERVAL_MS};
    uint32_t start = fido_millis(NULL);
    fv_input_controller_init(&approval, &timing, fv_rp2354_input_pressed_mask(), start);
    fv_input_map_t map;
    fv_input_map_clear(&map);
    (void)fv_input_map_bind(&map, FV_INPUT_SELECT, FV_EVENT_SELECT, false);
    (void)fv_input_map_bind(&map, FV_INPUT_BACK, FV_EVENT_BACK, false);
    fv_input_controller_set_map(&approval, &map);
    int result = -1;
    app.fido_waiting = true;
    fido_keepalive_status = 2;
    while (result < 0) {
        uint32_t now = fido_millis(NULL);
        if (!fido_safe(NULL)) { result = 2; break; }
        if ((uint32_t)(now - start) >= 30000u) { result = 1; break; }
        if (!fv_display_render(&display, &app, now)) {
            display_ready = false; fido_fault = true; result = 2; break;
        }
        fv_diag_service(1);
        uint64_t input_start=fv_diag_begin();
        fv_input_controller_update(&approval, fv_rp2354_input_pressed_mask(),
            now, fido_presence_event, &result);
        sleep_ms(1u);
    }
    app.fido_waiting = false;
    fido_keepalive_status = 1;
    /* Consume the approval press so it cannot become a menu action. */
    fv_input_controller_init(&input_controller, &timing,
        fv_rp2354_input_pressed_mask(), fido_millis(NULL));
    fv_input_map_for_app(&app, &map);
    fv_input_controller_set_map(&input_controller, &map);
    return result;
}
static bool fido_local_authorized(void *context) {
    (void)context;
    return fido_safe(NULL) && fido_verification.valid &&
        (uint32_t)(fido_millis(NULL) - fido_verification.verified_at) < FV_FIDO_UV_COMPLETE_MS;
}
static bool fido_cancelled(void *context) {
    (void)context; return fido_fault || fv_rp2354_usb_fido_cancelled();
}
static uint8_t fido_uv_retries(void *context) {
    (void)context;
    return app.failed_attempts < FV_MAX_UNLOCK_ATTEMPTS ? (uint8_t)(FV_MAX_UNLOCK_ATTEMPTS - app.failed_attempts) : 0;
}
static bool fido_verify_user(void *context, const uint8_t *rp_hash) {
    (void)context;
    if (!runtime.authentication.vmk_valid || !app.session_unlocked ||
        !fv_fido_verification_use(&fido_verification, fido_millis(NULL), rp_hash)) {
        fido_reunlock = true; return false;
    }
    return true;
}
static size_t fido_dispatch(void *context, uint32_t channel,
    const uint8_t *request, size_t size, uint8_t *response, size_t capacity) {
    (void)context;
    fido_running = true;
    app.fido_reset_pending = size != 0 && request[0] == 7;
    size_t count = 1;
    response[0] = 0x7f;
    if (fido_safe(NULL)) count = fv_fido_engine_command_channel(channel,
        request, size, response, capacity);
    (void)fido_safe(NULL);
    if (!fido_store.ready || fido_fault) {
        response[0] = 0x7f; count = 1;
        if (!fido_fault && fv_rp2354_usb_fido_cancelled()) fido_reunlock = true;
        else fido_fault = true;
    }
    if (fido_verification.started && (uint32_t)(fido_millis(NULL) -
            fido_verification.verified_at) >= FV_FIDO_UV_COMPLETE_MS) {
        response[0] = 0x3c; count = 1; fido_reunlock = true;
    }
    fido_running = false;
    app.fido_reset_pending = false;
    return count;
}
#endif

typedef enum {
    BOOT_RECOVERY_READY = 0,
    BOOT_RECOVERY_WAITING_FOR_MEDIA,
    BOOT_RECOVERY_FAILED,
} boot_recovery_state_t;

static bool target_random(void *context, uint8_t *output, size_t length) {
    (void)context;
    return fv_rp2354_random_fill(output, length);
}

static bool usb_attach_msc(void *context,
                           fv_block_device_t *plaintext_blocks) {
    (void)context;
    if (!fv_connector_safety_poll(&connector)
#if !FUSE_VAULT_HEADLESS_DEBUG
        || !fv_connector_safety_route(&connector)
#endif
        ) {
        return false;
    }
    if (fv_rp2354_usb_msc_attach(plaintext_blocks)) return true;
#if !FUSE_VAULT_HEADLESS_DEBUG
    (void)fv_connector_safety_disable(&connector);
#endif
    return false;
}
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

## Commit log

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2026-09-03 Add initial firmware for Fuse Vault RP2354A board
    - Create CMakeLists.txt for firmware build configuration.
    - Add README.md with project overview, prerequisites, and build instructions.
    - Define custom board properties in boards/fuse_vault.h.
    - Implement host simulator and tests in host/ directory.
    - Develop application logic in src/app.c and main entry point in src/main.c.
    - Include necessary header files for application and block device interfaces.
    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
2026-09-03 Add graphical display simulator and enhance secret entry functionality
    - Implemented a GTK-based graphical simulator for the Fuse Vault display.
    - Enhanced secret entry logic to allow for wheel adjustments and input clearing.
    - Updated README with simulator usage instructions.
    - Added tests for secret entry behavior.
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2026-09-05 Add persistent state management for Fuse Vault simulator
    - Introduced a new persistent simulator mode in the display simulator to manage attempt persistence across restarts.
    - Updated launch and task configurations in VS Code for the new persistent simulator.
    - Enhanced the security design documentation to reflect the new state management features.
    - Modified the firmware to include a new host services library for managing persistent state.
    - Implemented device state loading and storing functionality to handle persistent attempts and device secrets.
    - Updated application state machine to include a new state for reserving attempts before authentication.
    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
2026-09-05 Implement device secret management and security journal
    - Introduced new structures and enums for device secret status and security state management.
    - Updated host services tests to include provisioning, reading, and revoking device secrets.
    - Added NOR flash emulation with read, program, and erase functionalities.
    - Created a security journal to manage state transitions and recoveries with authentication.
    - Implemented random number generation specific to the RP2354A platform.
    - Added documentation for RP2354A secret and security-state storage.
    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
2026-09-05 Refactor secret entry methods and enhance encoding
    - Introduced modular entry methods for secret input: wheels, directions, keypad, and word list.
    - Updated `fv_app_init` to accept an entry method parameter.
    - Refactored `fv_app_handle` to manage different entry methods during setup and unlocking.
    - Enhanced `fv_secret_entry` structure to accommodate various input methods and their states.
    - Implemented handling and rendering functions for each entry method.
    - Updated encoding logic to support new entry methods and ensure backward compatibility.
    - Adjusted tests to validate new functionality and ensure correctness across all entry methods.
    [main.c]
2026-09-05 Add boot recovery and provisioning coordinator tests, and implement authentication and boot recovery functionality
    - Introduced `boot_recovery_tests.c` to validate the recovery of entry methods after a restart.
    - Added `provisioning_coordinator_tests.c` to test various provisioning scenarios and failure cases.
    - Created `authentication_coordinator.h` and `authentication_coordinator.c` to handle authentication sessions and validation.
    - Implemented `boot_recovery.h` and `boot_recovery.c` for recovering entry methods from vault headers.
    - Developed `provisioning_coordinator.h` and `provisioning_coordinator.c` to manage device secret provisioning and state storage.
    - Added necessary utility fun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
    [main.c]
2026-09-05 Add new modules for display, encrypted block, peripheral safety, vault header store, and virtual MSC
    - Introduced `display.h` and `display.c` for managing UI display operations.
    - Added `encrypted_block.h` and `encrypted_block.c` to handle encrypted block storage with integrity checks.
    - Created `peripheral_safety.h` and `peripheral_safety.c` to ensure safe operation of USB connectors and removable blocks.
    - Implemented `vault_header_store.h` and `vault_header_store.c` for serialization and deserialization of vault headers.
    - Developed `virtual_msc.h` and `virtual_msc.c` to provide a virtual mass storage controller interface.
    - Implemented block slice functionality in `block_slice.c` for man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
2026-09-06 Add USB descriptors and MSC implementation for Fuse Vault
    - Implement USB device descriptors in rp2354_usb_descriptors.c
    - Create MSC functionality in rp2354_usb_msc.c for handling storage operations
    - Configure TinyUSB settings in tusb_config.h
    - Introduce provisioning files for OTP policy and permissions
    - Add tools for preparing signed releases and verifying OTP policies
    - Document release and provisioning processes in README.md
2026-09-06 Implement FIDO2 integration plan and associated SD SPI functionality
    - Added a comprehensive FIDO2 reuse assessment and integration plan document outlining the recommendations, source revisions inspected, findings, proposed product policy, and delivery sequence.
    - Introduced SD SPI interface and implementation for the RP2354 platform, including initialization, transfer, and deinitialization functions.
    - Created test suite for SD SPI protocol to validate read/write operations, error handling, and timeout scenarios.
    - Developed stubs for the Pico SDK to facilitate testing without hardware dependencies.
    - Implemented PIO program for SPI communication, ensuring compatibility with the Raspberry P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
    [rp2354_sd.c, rp2354_sd_spi.c]
2026-09-06 Add Fuse Vault credential management and settings functionality
    - Introduced credential_change.h and credential_change.c for handling credential updates.
    - Added passkeys.h to define structures and actions related to passkeys.
    - Created settings.h and settings.c to manage user settings, including password and entry method changes.
    - Implemented settings_view.c to render the settings interface.
    - Added app_view.c to manage the main application view rendering.
    - Included runtime linker scripts and documentation for stack and memory management.
    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
2026-09-27 Add SM4 encryption implementation and UI preview tools
    - Implemented SM4 encryption algorithm with key scheduling in `sm4_setkey.c`, encryption in `sm4_enc.c`, and decryption functions.
    - Added lookup tables for S-box and T-box in `sm4_common.c`.
    - Created local header file `sm4_lcl.h` for internal SM4 functions and constants.
    - Developed UI preview tool in `ui_preview.c` to render synthetic UI states without USB, saving outputs as PBM files.
    - Added Python script `ui_preview.py` to automate the compilation and rendering of UI states, generating a contact sheet and HTML gallery.
    [Drill_NPTH_Through.DRL, Drill_PTH_Through.DRL, Drill_PTH_Through_Via.DRL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]
2026-10-01 Refactor code structure for improved readability and maintainability
    [back_button_coupon.step, back_button_coupon.stl, base.step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]
2026-10-05 snap case and documentation update
    [base.step, base.stl, base_snap_firm.step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]
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2026-10-10 Enhance FIDO journal functionality and improve file handling
    - Increased dynamic file slots and maximum dynamic files to accommodate larger data sets.
    - Introduced a file view mechanism to manage file data access without retaining data after use.
    - Updated file reading functions to utilize the new file view structure, ensuring efficient memory management.
    - Implemented error handling for file size limits to prevent overflow.
    - Added tests for FIDO journal operations, including capacity checks, migration scenarios, and fault tolerance.
    - Created a new header file for FIDO journal definitions and functions to streamline code organization.
    - Improved overall code structure and readability by re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
2026-10-17 Implement token-only OTP enrollment with 228 slots (replaces permanent device root)
    Replace the permanent device root + 8 enrollment slot layout with a token-only
    design: a 3-bit status mask on OTP page 3 and token secrets on pages 4-60,
    providing 228 enrollment slots on a fresh token area. The token is both the
    binding key and journal-authentication key input, eliminating the permanent
    root. Mask states (UNUSED/STARTED/READY/REVOKED) enforce write-once OTP
    transitions. Interrupted provisioning consumes STARTED slots and advances to
    the next UNUSED slot.
    Adds otp_mask_tests.c host test harness covering mask transitions, provisioning,
    binding from token only, destroy-and-rotate, interrupted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
2026-10-27 Implement token-only OTP enrollment and associated tests
    - Added a new markdown file documenting the token-only OTP enrollment feature, detailing the changes made, validation results, and remaining acceptance criteria.
    - Created a JSON file for RAM buffer test results, capturing firmware information and RAM usage samples.
    - Introduced button diagnostic tests in Python, simulating GPIO interactions and validating button press behavior.
    - Added C tests for USB vault I/O operations, ensuring correct handling of read/write requests and error conditions.
    - Developed a Python tool for monitoring physical button states, providing real-time feedback on button presses.
    - Implemented a header file for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
